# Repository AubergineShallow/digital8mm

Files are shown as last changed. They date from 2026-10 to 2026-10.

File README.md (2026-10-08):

# digital8mm: GS8 D2

GS8 D2 is a pistol-grip digital "Super 8" cine camera in the spirit of the Nizo:
- a Raspberry Pi 5 with the Raspberry Pi Global Shutter camera (IMX296, C/CS mount);
- an integrated micro-OLED electronic viewfinder;
- a 3D-printed ASA body;
- a physical 18/24 fps switch, an exposure dial and a record button;
- recording RAW to a removable USB stick.

This repository holds **only the D2 fork** of the wider GS8 project, plus the few shared files its build needs.

**Status:** a computed CAD release candidate (r6, 2026-10-08), **not a qualified design**.
- Every result here is a computed check on built solids and purchased-part proxies, desk research, or a document.
- Nothing has been printed, sliced, bought, measured, assembled or powered.
- 53 physical bench gates are open.
- **Print order (r6).** It is settled and enforced: [`PRINT-GUIDE.md`](cad/gs8-d2-v1/PRINT-GUIDE.md) section 7 says
  which measurements each part waits for. Start with the calibration coupons and the bench measurements (camera and
  lens first).
- **Print orientation (r6).** It is settled and checked layer by layer (`print_overhang`).
- **Open design defect.** The lens collar's clamp has no spring (audit 2026-10-06 M1); fix it before the collar is
  printed.

## Start here

1. [`cad/gs8-d2-v1/HANDOFF.md`](cad/gs8-d2-v1/HANDOFF.md): current state, latest build receipt, open items.
2. [`CLOUD-START-HERE.md`](CLOUD-START-HERE.md): how to reproduce the CAD and run the software on a host.
3. Design and build documents:
   - [`SPEC.md`](cad/gs8-d2-v1/SPEC.md): the contract;
   - [`DESIGN.md`](cad/gs8-d2-v1/DESIGN.md);
   - [`ASSEMBLY.md`](cad/gs8-d2-v1/ASSEMBLY.md);
   - [`PRINT-GUIDE.md`](cad/gs8-d2-v1/PRINT-GUIDE.md);
   - [`FASTENER-POLICY.md`](cad/gs8-d2-v1/FASTENER-POLICY.md);
   - [`MEASURED-PARTS.md`](cad/gs8-d2-v1/MEASURED-PARTS.md): the bench gates.
4. Electronics: [`electronics/gs8-d2-v1/WIRING.md`](electronics/gs8-d2-v1/WIRING.md) and
   [`BOM.md`](electronics/gs8-d2-v1/BOM.md).

## Layout

| Path | Contents |
|---|---|
| `cad/gs8-d2-v1/` | CadQuery sources (`layout.py` is the single geometry source), checks, tests, docs, research notes |
| `cad/gs8-d2-v1/out/` | Current release outputs: production STLs, modifier and coupon meshes, the collar centring gauge (`stl/tools/`), STEP, manifests, `checks.json`, `build-receipt.json`; Fujinon variant in `out/_fujinon-cloud-polish-20261007/` |
| `electronics/gs8-d2-v1/` | Wiring, BOM generator and BOM, power and fuse research, second-hand sourcing notes |
| `software/gs8-camera-evf/` | Camera software package, including the D2 integration (`d2_*.py`, `D2-INTEGRATION.md`) |
| `audit/d2-readiness-*` | Independent readiness audits of D2 and their responses |
| `visual-review/`, `validation/` | Rendered review views and computed verification records |

**Shared files carried over from the parent project** because the D2 build reads them:
- `electronics/gs8-evf-v1/EVF-SELECTION.md`: an EVF gate document;
- `cad/gs8-pxl-v3/cad-requirements-lock.txt`: the pinned CAD environment;
- `tools/bootstrap_cad.py`: creates that environment;
- `outputs/bom-release-2026-09-25/prices.json`: BOM prices.

**Kept out of git** (see `.gitignore`):
- manufacturer drawings and datasheet images used in research;
- airflow-simulation checkpoints;
- historical build folders;
- baseline zip snapshots.

## Reproduce

Use the pinned environment (Python 3.12.14 plus 43 locked packages), then run from the repository root. On Windows
use `.venv-cad/Scripts/python.exe` as the interpreter:

```text
python tools/bootstrap_cad.py
python cad/gs8-d2-v1/run_locked.py -- cad/gs8-d2-v1/test_r3_regressions.py
python cad/gs8-d2-v1/run_locked.py -- cad/gs8-d2-v1/build_d2.py --skip-renders --sweep-step 1.0
```

The full release sequence (coupons, Fujinon variant, tables, BOM, audit) is in `CLOUD-START-HERE.md`. Heavy CAD
commands always go through `run_locked.py`.

## Licences

- `software/gs8-camera-evf/` and `tools/` carry their own licence files.
- The DejaVu font has its licence in `cad/gs8-d2-v1/fonts/`.
- No licence has been chosen yet for the rest of this repository.

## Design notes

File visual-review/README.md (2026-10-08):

# D2 cloud polish visual supplement

Six views of the final Kowa cloud-polish CAD candidate. They preserve the approved D2 architecture and show the intended paint-filled markings. The camera has not been physically built or tested.

## Gallery

- `renders/hero.png` - overall form and intended finish
- `renders/controls.png` - corrected selector shaft state and pinned-font labels
- `renders/controls-raw.png` - the same control geometry with unfilled engraving
- `renders/collar_pinch.png` - collar, washer seating and top-down pinch access
- `renders/rear.png` - viewfinder, storage access, grip and strap-side view
- `renders/service.png` - illustrative part separation; harnesses omitted

The exploded view is not an assembly sequence. Follow the main ASSEMBLY.md, including shutdown and physical battery isolation before internal service. Assembly STEP depicts cleared, post-processed holes; sacrificial printing membranes belong to the production STL/print guide.

The visible materials are illustrative. Black fill on the silver panel and white fill on the selector index/power symbol follow the existing finish intent. The exposed encoder shaft is a neutral hardware proxy, not a blue PCB surface. No decorative part was added, and no bore, fastener, or access opening is hidden.

## Findings and evidence

`REVIEW.md` explains the visual/ergonomic review and the changes it informed. `ENCODER-PUSH-REQUIREMENT.md` defines the measurement and acceptance procedure for the uncommissioned encoder push. `control_geometry_probe.json` preserves the baseline geometric measurements behind that finding and the repaired selector mismatch.

All 53 physical gates remain open. The render is not evidence of lens-band fit, optical focus, print quality, switch travel, comfort, cable routing, thermal performance or assembled stability. Kowa is the default modeled lens; the alternative Fujinon has its separate validated computational build in the main package.

`RENDER-PROVENANCE.json` binds the final images/scripts to the Kowa build receipt and source/STEP checks. It also records the independently passing Fujinon receipt. Baseline and intermediate candidate renderings are excluded.

## Reproduce the views

Prerequisites: the main project beside this folder; its pinned CadQuery 2.6.1 environment and exported final STEP files; Blender 4.3.2. From `project/visual-review`, use the pinned Python interpreter for this serialized mesh-export step:

    python ../cad/gs8-d2-v1/run_locked.py -- scripts/export_review_meshes.py --cad-root ../cad/gs8-d2-v1 --build-out ../cad/gs8-d2-v1/out --out meshes

The exporter refuses mismatched recorded Python/font sources or part STEP hashes. Do not run a second CAD command concurrently or remove its lock.

Render one view:

    blender -b -t 6 --python scripts/render_review.py -- --assets meshes --out renders --view hero --samples 128 --revision r5-cloud-polish-20261007

Repeat with `controls`, `collar_pinch`, `rear` and `service`. Add `--raw` to `controls` for the unfilled comparison. Optional exploration views are `collar` and `grip`.

The renderer uses Cycles CPU with denoising disabled and no external scene assets. It changes only lighting, display materials and explanatory exploded positions. The scripts do not rebuild a production release or close any hardware gate.

The separately delivered six-page PDF contains these same six views. `scripts/build_visual_gallery.py` reproduces it from `renders` using Pillow and ReportLab; its hash is recorded in RENDER-PROVENANCE.json.

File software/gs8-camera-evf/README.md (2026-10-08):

# GS8 EVF software fork

## D2 cloud-copy integration (2026-10-06)

For D2's physical 18/24 switch, toggle-run input and **1S X1203** power policy,
start with [D2-INTEGRATION.md](D2-INTEGRATION.md). The new `d2-demo` command runs
labelled synthetic controls/descriptor takes on a host; `d2-run` is an explicit
integrator adapter/config entrypoint with no default live deployment. D2 host
logic is tested; physical GPIO, display retention, media handling and power/heat
qualification remain open. The historical `run` path and **3S** battery text
below are preserved and must not be used as D2 wiring/configuration.

[D2-PRESENTATION.md](D2-PRESENTATION.md) adds pure host-rendered EVF status pixels
and a labelled preview gallery. Its full-sensor viewport requires a future
compositor adapter; it is not a drop-in overlay or verified shutdown display.

## Historical release-v1 / GNB 3S commissioning path

The remaining commands and battery configuration describe the preserved
**3S / hold-trigger** path, not D2's **1S / toggle-run** path. For the D2 cloud
copy, use [D2-INTEGRATION](D2-INTEGRATION.md) and the project-level
[CLOUD-START-HERE](../../CLOUD-START-HERE.md).

Historical branch battery: **GNB11003S60AHV 3S LiHV**, charged outside the camera.
`power.py` supplies the common pack-voltage stop policy and
`step_with_battery` recorder adapter. It inhibits new takes before voltage
qualification and uses the existing durable-drain contract before OS poweroff.
It does not replace independent per-cell protection or a kernel halt interface.
See [power design](../../electronics/gs8-gnb3s-v1/README.md).

This independent package preserves `software/gs8-camera` and adds a real,
lazy-loaded Picamera2 adapter for the colour IMX296 and an HDMI colour EVF.
Host tests pass; no Pi, sensor, DNG output, display, or optical latency has been
tested on physical hardware here. Treat this as a commissioning build.

The ISP feeds a 728 × 544 XRGB8888 preview directly to DRM/KMS. That is exactly
half the 1456 × 1088 sensor in each dimension. DRM preserves the whole sensor
aspect ratio within the HDMI canvas; no electronic finder parallax is added.
The default HDMI canvas is 1024 × 768, the native input of the selected EVF-A (and of
EVF-A2 and EVF-B; see [EVF-SELECTION.md](../../electronics/gs8-evf-v1/EVF-SELECTION.md)).
`--display-size 1920 1080` applies only to the external Kinefinity EAGLE fallback. The active CRTC must match the
requested dimensions at progressive 59–61 Hz, or startup fails. The display
controller can still scale/crop internally: verify a grid and colour bars in
the actual eyepiece, using its native input resolution wherever supported.

## Capture and exposure policy

| Recording | Default sensor/ISP rate | Recorded source frames | 90° exposure |
|---|---:|---|---:|
| 24 FPS | 48 FPS requested | every second frame | 10,417 µs |
| 18 FPS | 54 FPS requested | every third frame | 13,889 µs |

These are new sensor exposures, not repeated recording frames. A 60 Hz display
repeats some of the 48/54 source images. The integer ratios preserve uniform
recorded sampling; the sensor clock and microsecond frame-duration quantisation
still cause small rate error, so actual timestamps and measured rate are saved.

`--source-fps 60` lowers the source period for either recording rate, but 24 FPS
then alternates 2/3 sensor periods (33.3/50 ms), and 18 FPS uses 3/4 periods
(50/66.7 ms). This uneven capture cadence is explicit in the manifest. No
interpolation, duplicates or fabricated sensor timestamps hide the difference.

High source FPS cannot coexist with long per-frame cinema exposures on this
single sensor: 180° at 18 FPS is 27,778 µs, and at 24 FPS it is 20,833 µs.
Both are rejected by the default high-rate modes with a provisional 200 µs
sensor timing margin. **The hardware CLI explicitly defaults to 90°.** It
never silently shortens a selected shutter angle. Actual exposure, gain, WB,
frame duration, and source timestamp are checked and recorded for each take.

## Latency and storage ownership

Preview uses upstream Picamera2's newest completed request, DMA buffer scanout,
`queue=False`, four camera buffers, and noise reduction off. There is no video
encoder, network transport, compositor, or Python preview pixel copy.
`queue=False` disables cached still capture; upstream newest-request rendering
is what prevents a FIFO of old preview frames.

The callback only checks metadata and hands off a reference. A worker retains
**at most one** camera request, copies selected RAW pixels, and releases that
request before a separate worker creates an uncompressed DNG. Copied RAW is
bounded to two queued frames, DNG output to four, and the CLI disk writer to
four. Disk or conversion overload explicitly fails the take rather than
retaining the entire sensor pool. Accepted data drains before durable close;
the inherited journal, hashes, commit receipt and storage reservation remain.

Recording sample indices and original sensor frame sequences are separate.
Intentionally unrecorded preview exposures are counted separately from losses.
Any sensor sequence gap or failure to sustain the requested cadence fails the
take. `record_pts_ns` is an explicitly nominal postproduction timeline;
`sensor_timestamp_ns` remains libcamera's measured CLOCK_BOOTTIME timestamp.

Continuous preview survives normal take completion through `release_take()`.
Subsequent takes use the same sensor controls; changing controls requires a new
backend session. Idle preview errors inhibit recording. Shutdown and faults
fully close the preview/camera; no software code asserts the OS_HALTED line.

## Run on a Raspberry Pi 5

Use Raspberry Pi OS with its matched apt versions of `python3-picamera2`,
libcamera, KMS bindings and NumPy. Run on the local text console with KMS access,
the EVF as the only connected display, and no desktop display server owning DRM.
`kmsprint` reports the active HDMI timing. Before starting, apply the EVF-A HDMI
settings in [EVF-SELECTION.md](../../electronics/gs8-evf-v1/EVF-SELECTION.md) section 4
(also [release WIRING.md](../../electronics/gs8-release-v1/WIRING.md) section 8):
`max_framebuffers=2` and `disable_fw_kms_setup=1` in `config.txt`, and
`video=HDMI-A-1:1024x768@60D vc4.force_hotplug=1` in `cmdline.txt`. Section 4 also
gives the custom-EDID fallback, and receipt gate G2 accepts the mode. The software never
sets an HDMI timing. It refuses to start unless the active mode matches
`--display-size` at progressive 59–61 Hz. Pin and record the installed package
versions after commissioning; upstream API inspection alone is not a version
qualification.

From this package directory:

```sh
python3 -m venv --system-site-packages .venv
. .venv/bin/activate
python -m pip install -e .
kmsprint
# Set these to measured white-balance calibration values for the scene:
export GS8_WB_RED=1.5 GS8_WB_BLUE=1.25  # examples only; replace before commissioning
gs8-camera-evf run --output /media/gs8/takes --fps 24 --shutter-angle 90 \
  --wb-gains "$GS8_WB_RED" "$GS8_WB_BLUE" --seconds 10 --takes 3 --pause-seconds 2 \
  --display-size 1024 768
# External Kinefinity EAGLE fallback only (1920x1080); EVF-A uses --display-size 1024 768:
gs8-camera-evf run --output /media/gs8/takes --fps 18 --shutter-angle 90 \
  --wb-gains "$GS8_WB_RED" "$GS8_WB_BLUE" --preview-only --seconds 60 \
  --display-size 1920 1080
gs8-camera-evf inspect --output /media/gs8/takes
```

SIGINT/SIGTERM request a drained stop. A take may remain failed/incomplete if
hardware or storage refuses to drain. The CLI creates scheduled bench takes;
physical selector/trigger GPIO, audio/I2S, film/pixel looks, automatic service
startup and shutdown wiring still require integration/commissioning. Hardware
capture rejects audio, encoded recording and unimplemented looks. The separate
`simulate` command produces labelled descriptors, never camera footage.

The optional `--battery-hwmon PATH` enables an INA260 low-battery drained stop
through the Linux hwmon driver. It needs a kernel `ina2xx` hwmon device named `ina260`,
which the release `config.txt` does not create yet (open item in
[release WIRING.md](../../electronics/gs8-release-v1/WIRING.md) section 10).
Add `--battery-poweroff` to request OS poweroff
after a battery-triggered stop only when recorder/preview/store cleanup succeeds.
Startup requires one second of valid readings at ≥11.1 V; ≤10.5 V for one second,
≤10.2 V immediately, or faulty/stale telemetry latches stop. Thresholds remain
provisional. Normal command completion ends monitoring without halting the Pi.
This is commissioning software, not an independent battery protector or a
completed physical cutoff. See the [GNB 3S power design](../../electronics/gs8-gnb3s-v1/README.md)
for setup boundaries, warnings, waveform qualification and remaining gates.

Uncompressed 16-bit containers for RAW10 are about 3.17 MB/frame before DNG
overhead: about 76 MB/s at 24 FPS or 57 MB/s at 18 FPS. Use storage with measured
sustained write/fsync margin. DNG conversion and Linux scheduling can compete
with preview despite bounded ownership: benchmark on the actual Pi under heat,
power and disk stress. Optical source-to-eyepiece measurements, not callback
timing, must establish a latency claim. See the fork's root EVF design and
latency acceptance procedure.

## Host verification

```sh
python -m unittest discover -s tests -v
python -m gs8_camera_evf simulate --output /tmp/gs8-evf-smoke --fps 24 --frames 48
```

Tests include source cadence, colour-mode validation, exposure conflicts,
HDMI geometry, retained-buffer limits, blocked conversion, queue saturation,
source loss, applied metadata, close retry, idle fault handling, two complete
takes with continuous preview, and final shutdown. Fake DNG bytes are labelled
test data; these tests do not validate a real DNG decoder or display latency.

## Primary sources inspected 2026-09-20

- [Raspberry Pi Global Shutter Camera specifications](https://www.raspberrypi.com/products/raspberry-pi-global-shutter-camera/): colour IMX296, RAW10, up to 1456 × 1088 at60 Hz.
- [Picamera2 camera configuration and event loop source](https://github.com/raspberrypi/picamera2/blob/main/picamera2/picamera2.py): stream controls, queue semantics and newest-request preview selection.
- [Picamera2 request and DNG helper source](https://github.com/raspberrypi/picamera2/blob/main/picamera2/request.py): reference ownership, owning RAW copies, `Helpers.save_dng()`.
- [Picamera2 DRM preview source](https://github.com/raspberrypi/picamera2/blob/main/picamera2/previews/drm_preview.py): DMA scanout, aspect fit, retained display request and atomic commit.
- [libcamera control definitions](https://docs.libcamera.org/master/internal-api/namespacelibcamera_1_1controls.html): applied sensor controls and timestamp clock.
- [KMS Python bindings](https://github.com/tomba/kmsxx/blob/master/py/pykms/pykmsbase.cpp): CRTC active mode and video timing readback.

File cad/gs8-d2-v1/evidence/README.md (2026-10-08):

# GS8 D2 evidence records (r3)

Nothing in this folder exists until someone slices, prints, measures or assembles real hardware. The build machine
has no slicer, printer or parts: `build_d2.py` only reads the records here and reports them; it never judges them and
never closes a hardware gate.

## One record per tested item

A record is a JSON object (a file may hold one object, a list, or `{"records": [...]}`) in any `*.json` file under
`evidence/` (by convention `slicer/`, `coupons/`, `measured/`, `assembly/`). Copy `_record-template.json`. Files whose
name starts with `_` or contains `template`, and this README, are skipped. Any other non-JSON file (a photo, a `.md`
report) is listed as `ignored_files` in the receipt: keep it as an attachment and name it in `notes`, but it is not
evidence by itself. **File names are never matched**: `panel.md`, `base_edge_panel.json` or `old-panel-r1.md` say
nothing to the build.

| Field | Content |
|---|---|
| `item` | the exact item id: a printed part id for `slicer_review` (`panel`, `tub`, ...), a gate id otherwise (`G-CAP-1`, `G-KNOB-1`, `G-W6`, `EVF-G2`, ...) |
| `state` | `slicer_review`, `coupon_validation`, `measured_fit` or `assembly_operation` |
| `artifacts` | `{path: sha256}` of every artifact actually tested: `stl/<part>.stl` (production STL), `stl/coupons/<coupon>.stl`, or a source/doc path relative to `cad/gs8-d2-v1/` or the repo root |
| `profile` | printer, nozzle, material, slicer + version + profile (or the measuring tool / variant) |
| `verdict` | `pass` or `fail` (nothing else) |
| `date`, `by` | when and who. r6 (audit 2026-10-06 L12b): `date` is ISO 8601, `YYYY-MM-DD`, optionally with a time (`2026-10-20 14:30`); anything else is rejected, because the print order compares dates |
| `notes` | optional: settings, values, observations, attachment names |

sha256 of a file: `python -c "import hashlib,sys;print(hashlib.sha256(open(sys.argv[1],'rb').read()).hexdigest())" out/stl/panel.stl`
(the receipt `out/build-receipt.json` `files` lists the current hashes).

## What the build reports (receipt `status_states`, `open_evidence`, `hardware_gates`)

- **Completeness** per item: a current, valid record exists (`evidence_complete`).
- **Outcome** per item: `pass`; `fail`; `conflict` (current records disagree); `stale` (every record names an artifact
  whose sha256 differs from the CURRENT production STL, coupon STL or source, or that no longer exists: r1 and older
  records are stale); `rejected` (the item has a rejected record: it stays open until that record is corrected or
  removed, whatever the other records say); `not run`.
- Rejected records (listed with the reason, never counted as a pass): missing field, bad hash, verdict other than
  pass/fail, unknown state, a coupon artifact on a production-part item, a record that does not name the required
  artifacts. A record of a valid state whose `item` is not a required id (e.g. `Panel` for `panel`) is listed in that
  state's `unmatched_records` and keeps the state open. A file that is not readable JSON, or a record with an unknown
  state AND an unknown item, is listed in `evidence.unassigned_records` (and `rejected_records`) and named in
  `open_evidence`.
- Required artifacts (artifact keys: production / coupon STLs as `stl/...`; docs and sources as repo-root paths, e.g.
  `cad/gs8-d2-v1/MEASURED-PARTS.md`; a path relative to `cad/gs8-d2-v1/` is accepted and converted):
  - `slicer_review`: `stl/<item>.stl` and (r4) every modifier mesh of that part,
    `stl/modifiers/<item>__mod_<id>.stl` (r5: tub 10, panel 4, base_grip 4; the slice must load them);
  - `coupon_validation`: every coupon STL of its gate (from `out/coupons-manifest.json`, `coupons-r1-manifest.json`)
    or calibration;
  - `measured_fit`: the gate's acceptance doc (`electronics/gs8-evf-v1/EVF-SELECTION.md` for EVF-G*,
    `electronics/gs8-d2-v1/WIRING.md` for G-W*, else `cad/gs8-d2-v1/MEASURED-PARTS.md` if it names the gate, else
    `cad/gs8-d2-v1/SPEC.md`); also name any printed STL the part was fitted to (it is hash-checked too);
  - `assembly_operation`: that doc AND every production STL `stl/<part>.stl` (the assembly, service or bench test
    belongs to that release geometry; a geometry change makes the record stale).
- A state stays in `open_evidence` until EVERY required item has a current pass; failed, conflicting and stale item ids
  are named there. A rebuild that changes an STL or source makes the records for it stale: re-test and add a new
  record (keep the old one; it stays as history).

## Required items

- `slicer_review`: the 12 printed parts (`base_grip`, `cap`, `eyecup`, `hood`, `knob_exp`, `knob_fps`, `lens_collar`,
  `panel`, `pi_keeper`, `plunger`, `stick_sleeve`, `tub`; r5 added the lens collar, audit 2026-10-06 B-9).
- `coupon_validation`: G-PT-1, G-KEEP-1, G-PANEL-1, G-CAP-1, G-EVF-2, G-SNAP-2, (r5) **G-COL-1** (`collar_tub_front`
  + `collar_hood_plate` + `collar_part`, and since r6 the centring gauge `stl/tools/collar_gauge.stl`) and the
  PRINT-GUIDE s6 calibrations **G-KNOB-1** (`knob_bore_ladder_enc` +
  `knob_bore_ladder_sw`), **G-COMB-1** (`clearance_comb`), **G-J4-1** (`tongue` + `keyhole_slot`).
- **Names (audit L12c):** MEASURED-PARTS record ids (`MP-CAM`, `MP-PACK`, ...) are not items. File the record under
  its gate id: MP-CAM is `G-CAM-1` (the camera stack) and `G-LENS` (its lens line). A record filed as `MP-CAM` is
  unmatched and keeps `measured_fit` open.
- **Print order (r6, audit 2026-10-06 M2):** a `slicer_review` record for a part counts only after every gate of
  `layout.PRINT_PREREQS[part]` (PRINT-GUIDE s7) has a current recorded pass dated on or before it. The same holds for
  a G-COL-1 coupon record and `COUPON_PREREQS`. Otherwise the record is **rejected** with the missing gate named, and
  the part stays open. File the measured and calibration records first, then slice. The receipt's `print_release`
  says which parts that releases.
- `measured_fit`, `assembly_operation`: every other gate id named in MEASURED-PARTS.md, SPEC.md, WIRING.md and the
  EVF-SELECTION gate table (the receipt lists them in `hardware_gates`).
- **r4 split items** (`assembly_operation`): `G-SNAP-2/whole` (5 remove/refit cycles of the whole hood on the tub),
  `G-KEEP-1/whole` (5 keeper cycles on the real stack in the printed tub + the far-corner tilt test) and
  `G-PANEL-1/whole` (5 panel cycles on the body, strap fitted). Name the gate's doc (SPEC.md) and every production
  STL. The gate itself reads `recorded pass` only when its coupon item AND its `/whole` item have a current pass.
- **Field types (r4):** `item`, `state`, `verdict`, `profile`, `date`, `by` must be JSON strings and `artifacts` an
  object; a record with another type is rejected and listed (it never stops the build).

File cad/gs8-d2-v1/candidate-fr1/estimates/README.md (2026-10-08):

# Panel stiffness estimates (ESTIMATE only, not FEA-validated, nothing measured)

Copied 2026-10-05 15:16 by fix-candidate (finding VC-M3) from the fr-panel-2 session scratchpad `fp2/` so that
JOINT-panel.md s. 11.2 and CANDIDATE.md s. 2/6 can be reproduced from the fork. Files are byte copies of the scratchpad
originals (10:33-11:23).

- `grill.py`: grillage (Hambly) model of the 2.8 ASA panel (method in JOINT-panel.md s. 11.1).
- `opts.py`, `opts2.py`: option table (opts2 = unilateral wall-bearing contact, the model the table uses).
  Option '1e 1c+front rib' is **A2** (the chosen FR panel geometry).
- `opts2-output.txt`: output of `opts2.py` re-run here 15:17 (pure numpy, no CAD); it reproduces every number of the
  JOINT-panel.md s. 11.2 table and the bottom-edge profiles.
- `sens.py`: sensitivity runs; `depth.py` + `depth.pkl` + `ribchk.py` + `show.py`: the inner-face free-depth map used to
  place the frame ribs (depth.py reads the r2 STEP parts from `cad/gs8-d2-v1/out/step/parts/`, run from the repo root).

Run: `cd cad/gs8-d2-v1/candidate-fr1/estimates && ../../../../.venv-cad/Scripts/python.exe opts2.py`

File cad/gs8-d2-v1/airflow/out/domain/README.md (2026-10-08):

# D2 air domain (af-domain), baseline r2 arrangement

Made 2026-10-05 by `airflow/export_meshes.py` (run once under the CAD lock, 129 s) and `airflow/voxelize.py`
(run outside the lock, about 30 s for both grids). Geometry: the baseline release pipeline (`build_d2.build_printed` +
`build_cots`, default lens kowa_lm6hc, no FR1 changes). There were no stubs, and all 38 meshes are watertight
2-manifolds (`out/meshes/index.json` has the bounds, triangle counts and source hashes). Purchased parts are proxies.
Nothing here is a measurement.

## Files

- `../domain-2.0.npz`, `../domain-1.5.npz`: the shared interface from `airflow/NOTES.md`. Keys: `dx`, `origin`
  (centre of cell (0,0,0), assembly mm), `solid`, every `mask__*`, and `meta_json`. Two extra keys: `label` (int8,
  legend in meta) and `part` (int16 index into `part_legend`, -1 = none).
- `summary-<dx>.json`: the same meta as readable JSON (vents, fan, heat, pockets, plugs, connectivity, counts).
- `slice-<dx>-<axis><value>.png`: label slices through the cooler (z 27), the blower top / out_corner (z 33), the
  X1203 sandwich (z 13), the exhaust plenum (x -7), the EVF board (x -140), the roof inlet over the blower (x -58),
  roof inlet - blower - fins - front (y -10), and the right wall (y -33.6). Dark red dots mark air cells that
  receive heat.
- `voxelize.log`: per-part occupancy, timings and results.

## How the domain is built

- **Grid.** Cell faces lie on multiples of dx, so x = 0 (the front face) and z = 0 (the body bottom) are cell faces.
  dx 2.0 gives 86 x 45 x 60 cells; dx 1.5 gives 112 x 57 x 77.
- **Occupancy.** Each part is sliced (manifold3d) at 3 levels per cell and scan-converted with the even-odd rule at
  3 x 3 points per cell, giving 27 sub-samples. The shells (tub, hood, panel, base_grip) are solid where ANY
  sub-sample is inside, which keeps walls of dx/3 or more closed. All other parts are solid where 14 or more of the
  27 sub-samples are inside.
- **Body interior.** First the vent zones and the plugs are closed and the outside is flood-filled from the grid
  boundary. Nothing leaks: the interior never meets the outside except through a vent. The main interior is the
  connected air that holds the fan intake. The outside is inactive (solid) except in the vent buffers.
- **Closed holes (label 10, `mask__leak__*`).** The grip/battery bay is excluded. The floor lead holes
  (`floor_pigtail`, `floor_run_lead`) are treated as closed by the leads and a grommet. The microSD tweezer slot
  through both front walls (`ko_sd`, about 12 x 2.3 mm less the card) is treated as closed with the card in place.
  It is a real leak path. Opening it as a sensitivity also needs an outside buffer there, which is not built.
- **Vents (`mask__vent__<id>`, label 5).** A vent zone is the set of cells that overlap the wall along the normal and
  whose centre lies inside the vent's lateral box. The front vents are the tub window and the hood plate in series
  (x -5.2..0). The slots are not resolved; the porous zone carries the loss. The meta gives each vent's normal,
  thickness in cells, face cells, discrete/box area ratio (1.00 to 1.29), slot_w/pitch and its shortest air path
  from the fan intake and from the fin exit.
- **Outside buffer.** Beyond each vent face there are 5 buffer cells (label 3), grown 2 cells laterally, plus an
  ambient layer (label 4, `mask__ambient`) on the far face and the lateral rim.
- **Fan.** The proxy blower box (x -72.8..-42.8, y -24..4, z 23.4..36.3) is turned into housing walls one cell thick
  (-X, +-Y, top; the floor is the cooler plate) and an interior actuator (`mask__fan_actuator`, force unit +X). The
  top wall has an intake disc of r 9.0 at the proxy hub circle (`mask__fan_intake`). That radius is an ESTIMATE: no
  published intake size was used. The +X housing face is open only over the fin height (z 23.4..30.5) and is wall
  above it.
- **Fins.** `mask__fin_block` covers x -42.8..-9.5, y -25.55..16.95, z 23.4..30.5. The plates are normal to Y and
  open on top in the proxy, which models no shroud. So the block should be porous with low resistance along X (and
  along Z between the plates) and high resistance along Y. `mask__fan_outlet` is the first cell layer past the fins
  (x about -9). The SoC heat goes into the fin block (`mask__heat__soc`).
- **Heat masks.** Each mask is the interior air within 1 cell (26-neighbour) of its proxy:
  - X1203: the charger/boost field box.
  - EVF board.
  - Camera: gs_camera.
  - USB stick.
  - Pi board remainder: the PCB slab plus the underside parts (z 16..21.4); the jack blocks get no heat.
- **Probes.** Each probe is a set of air cells to average over:
  - `fan_intake_air`: the 2 layers above the intake.
  - The 5 component probes. Each one is the same set of cells as that component's heat mask.
  - `exhaust_plenum`: the ko_exhaust box.
  - `fin_exit`.
  - `roof_inlet_inner`: the layer under the roof zone.
  - `outside_<vent>`: the first buffer layer beyond each vent.

## Checks

| | dx 2.0 | dx 1.5 |
|---|---|---|
| interior air | 656 cm3 (82 051 cells) | 678 cm3 (200 983 cells) |
| fluid components | 1 | 1 |
| every vent reaches the fan intake and the fin exit through air | yes | yes |
| dropped pockets (no path to the fan or a vent) | 19, 9.6 cm3 | 11, 5.4 cm3 |
| fin block cells / actuator cells / intake cells | 1008 / 816 / 62 | 2576 / 2210 / 113 |
| fin section discrete / proxy | 252 / 302 mm2 | 252 / 302 mm2 |
| blower outlet open discrete / proxy | 144 / 199 mm2 | 153 / 199 mm2 |

**Dropped pockets.** The pockets are sealed air with no forced flow, so they are solid in the model.
- The largest (5-9 cm3) is the hood lens-collar cavity in front of the front wall, around the camera ring and C-CS
  adapter.
- Next come the small EVF optics cavities behind the board (hmx039 / eyepiece / foam).
- The rest are single cells: around the stack standoffs and screw bosses, plus a 40 mm3 corner by the X1203 at
  dx 2.0.

## Findings for the solver and the report (geometry, not flow results)

- **x1203 slots.** The proxy pogo-pin field (x -64..-13, y -31.8..-27.3, z 7.6..16) sits directly behind the x1203
  slots (x -65..-49, z 9.5..17.5). The slots only reach the sandwich through a band about one cell high above the
  pins (z 16..17.5) and around the ends. Their path from the fan intake (49 / 61 cells) is the longest of the vents.
  The pogo box is an estimate, so this needs checking on the real board.
- **out_wall slots.** The Pi 5 GPIO header and the board edge (0.2 mm off the right wall) sit behind the lower part
  of the slots, and the QT lead keep-out sits behind the upper part. At dx 1.5, 20 zone cells are pi5 solid.
- **Shortest paths.** The fin exit is 2 cells from out_band, 4 from out_corner and 7 from out_wall. The roof inlet is
  31 / 41 cells from the fan intake through the tall open chamber over the blower. There is NO wall between the fin
  exit / plenum and the space above the fins (the deleted baffle), so recirculation of exhaust to the intake is
  geometrically open.
- **Not modelled.** Cables and keep-out volumes (ribbon S-fold, HDMI coil, leads) are not modelled as solids, so
  they add blockage the model does not include. Fin height is 3 cells at dx 2.0 and 4 cells at dx 1.5 (6.0 mm
  against 7.1 mm), and the solver should scale the porous loss by the section ratio above.

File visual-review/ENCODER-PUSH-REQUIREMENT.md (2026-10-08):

# D2 exposure encoder push acceptance

Acceptance guidance integrated into the cloud-polish MP-ENC/G-MP-ENC and G-W9 work. The original geometry measurements are from the immutable r5 source. Required switch travel remains unknown, and no physical control test is claimed.

## Finding

The exposure encoder is push-capable, and WIRING section 8 makes a reset function available. The current fit gate verifies only shaft fit and the knob rest gap. It does not verify axial push travel. A knob can rotate normally yet stop against the panel or bushing before the switch closes.

Source evidence:
- `layout.py`: panel outer plane `YL = 35.0`; `KNOBS["knob_exp"]["y"] = (35.2, 44.2)`.
- `layout.py`: fixed bushing tip `ENCODER["bushing"]["a"][1] = 37.2`.
- `printed_small.py::build_knob`: recess roof is bushing tip + `FDM["SLIDE"] = 37.45`.
- Therefore unloaded panel clearance is 0.20 mm and unloaded bushing-roof clearance is 0.25 mm. The first-contact limit is at most 0.20 mm, before print/finish error or a positive running-clearance allowance. These are assembly-coordinate distances, not a measured switch travel.
- `MEASURED-PARTS.md`, MP-ENC: no push travel or full-stroke clearance record exists.

## Datum definitions

Use the fitted production panel, encoder and knob. The encoder must be fully latched in its actual cradle and the knob fitted to the depth intended for normal operation.

1. Panel datum P: the local outer panel plane, nominal Y = 35.0 mm. Positive Y points out of the control face; a press moves the knob and shaft in negative Y.
2. Fixed bushing datum B: the outer end of the stationary threaded bushing. Do not confuse this with the moving shaft shoulder or tip.
3. Rest datum K0: the nearest rigid knob underside face over the panel, with no finger load and the switch released.
4. Recess datum KR: the inside roof of the knob recess directly above the stationary bushing.
5. Travel s: the negative-Y displacement of the moving shaft/knob from the released position. Measure it at the shaft or knob using a dial indicator/caliper with the panel fixed, not by hand-force displacement of the whole panel.

Record gP = K0 - P and gB = KR - B after painting/finishing. Record the encoder part/variant, actuation stroke, release stroke, rated/full permitted stroke where available, and any drawing tolerances. Record whether the knob slides on the shaft or the cradle visibly deflects during the operation; neither is acceptable as a substitute for real switch travel.

## Acceptance procedure for MP-ENC and G-W9

- Measure the actual part before freezing knob height and recess depth. Record reliable contact closure and release over at least ten normal presses; use the manufacturer's allowed travel and force limits when available. If the switch travel specification is unavailable, leave it unconfirmed until the installed test is recorded.
- Choose the required operating stroke from the actual part data and repeated test, including its stated tolerance/overtravel. Do not populate the CAD parameter with a generic encoder value.
- Parameterize `required_push_travel_mm` as unknown until that record exists. Derive both rest gaps from the model, and report the available first-contact travel as `min(gP, gB)`.
- At the required operating stroke, the knob must clear both the panel and the fixed bushing by the declared axial running allowance. Use the project's existing slide allowance (0.25 mm) unless a validated fit record explicitly establishes another allowance; never infer allowance from successful rotation alone.
- Keep sufficient measured D-flat engagement and no axial shaft preload at rest. The knob must remain removable by the documented method. Do not hide the through bore with a separate cosmetic cap.
- Turn throughout the useful range, then press and release with the production panel closed. There must be no panel rubbing, bushing stop, binding, switch held closed at rest, accidental reset while rotating, or knob migration. Verify the reset behavior on the EVF under G-W9; software-only tests do not close this hardware gate.
- If it fails, raise the knob mounting/underside clearance and deepen its bushing recess as required by the measurement, then recheck shaft engagement, envelope/hand clearance, printability and the CAD operation sweep. Reprint only the affected part if the revised design permits.

## Example check (symbolic, not an assumed hardware dimension)

`panel_remaining = gP - required_push_travel_mm`

`bushing_remaining = gB - required_push_travel_mm`

`pass = measured_travel_is_current and min(panel_remaining, bushing_remaining) >= axial_running_allowance_mm`

For the existing r5 gaps this reduces to `min(0.20 - s, 0.25 - s)`. No positive stroke can satisfy a 0.25 mm residual allowance. The current CAD does not establish push readiness; this should be an explicit uncommissioned control operation, not a fabricated pass or a reason to invent a switch dimension.

The encoder remains the exposure control and the physical 18/24 selector remains unchanged. No new menu, indicator, printed part, or external control is proposed.

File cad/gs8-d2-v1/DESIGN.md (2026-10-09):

> Cloud-polish copy (`r5-cloud-polish-20261007`): see `CLOUD-POLISH-NOTES.md` before the historical record below.
> The generated blocks reflect the current copied build; hand-written r1-r5 results remain labelled history.
> This fork does not supersede later desktop work. All physical gates remain unvalidated.

# GS8 D2 release v1: design record (`cad/gs8-d2-v1`)

Integrator record, 2026-10-04 (machine time 12:43-14:15; skeleton by the docs owner); fixer pass 13:16-14:10 (section 6b); **r2 rectification 2026-10-05 00:00-01:30 (section 6c, `RECTIFICATION.md`)**; **r2 fixer pass 02:00-03:40
(verifier findings on r2; section 6d)**. **r5 2026-10-06: heavy-lens support (J7-R float; section 6f, `R5-BRIEF.md`).** The blocks between
`BEGIN`/`END` markers are generated by `python cad/gs8-d2-v1/make_tables.py` from `layout.py`, the build receipt and
the print manifest; the text around them is maintained by hand. Nothing in D2 is printed, bought or measured: purchased parts are
proxies, and only computed checks may say "pass".

## 1. Status

| Item | State (**r5 release build 2026-10-06 16:32:38 +0800**: heavy-lens support, the J7-R float (`R5-BRIEF.md`; `RECTIFICATION.md` "r5"): the camera model is rebuilt to the official GS drawing, a printed per-lens `lens_collar` carries the lens on 3 M3 screws in tub inserts + a foot, the camera hangs on the lens; pins and turret deleted. Kowa, `--sweep-step 1.0`; receipt `out/build-receipt.json`, checks.json SHA-256 c9d748c8...; 17 of 17 sources, 101 of 101 outputs and 4 of 4 gate docs match the files on disk; the generated s3 block carries the full receipt status) |
|---|---|
| `cad_checks` | **computed: pass**: 27 of 27 checks, 749 rows (732 pass, 17 info, 0 failed), 0 stubs (section 3). New r5 categories: `inserts` 4, `j7_float` 11, `lens_support` 28 pass + 4 info (WARN: no support band is measured yet), `lens_clamp` 3 pass + 1 info (WARN: the Kowa's slip moment 0.170 N m is below the 5 g moment 0.286 N m; static ratio 2.97 >= 1.5). `critical_features` 135 rows = 125 pass + 10 info (incl. the J7 joint_check row; the 10 info as r4); `cable_routes` 8 pass + 2 info. `cad_release_candidate: true` means only that: computed CAD checks on proxies |
| `slicer_review` | **not run** (no slicer on this machine; none downloaded): 0 of 12 printed parts with a current recorded pass |
| `coupon_validation` | **not run** (27 coupon STLs exported, none printed): 0 of 10 items (7 coupon gates incl. r5's G-COL-1 + the calibration records G-KNOB-1, G-COMB-1, G-J4-1) |
| `measured_fit` | **not run** (every purchased part is a proxy; `MEASURED-PARTS.md` lists what to measure; r5: MP-CAM rewritten with its lens line): 0 of 17 gates |
| `assembly_operation` | **not run** (no dry assembly, no service cycle, no powered test): 0 of 26 items (incl. G-W13, r5's G-CAM-2 sag acceptance and the r4 whole-part halves `G-SNAP-2/whole`, `G-KEEP-1/whole`, `G-PANEL-1/whole`) |
| Hardware gates | 55 listed, 53 open, 2 withdrawn (G-SNAP-1, G-SKIRT-1): the gate-doc ids incl. EVF-G1..G9, G4b, G-MP-FPC, G-W13, r5's G-COL-1 and G-CAM-2, the calibration ids G-KNOB-1, G-COMB-1, G-J4-1, and the 3 `/whole` items; receipt `hardware_gates` |
| Printed parts | 12 (generated count: s1.1; r5 adds the `lens_collar`, one per lens with a support band; r1 had 12 with the 2 skirts, r2-r4 11); all real CadQuery solids, 0 stubs |
| Purchased parts | 20 COTS proxies + 7 PT screws (4 enclosure + 2 keeper + the J4 lock s_j) + (r5) 4 M3 lens-collar screws with washers and heat-set inserts (`m3_hw`; generated counts incl. the separate X1203 kit screws/standoffs: s1.1), from datasheet, listing, drawing, repo or estimate |
| Second run | Fujinon lens, `--fast --sweep-step 1.0`, on the final r5 sources (`out/_fujinon-r5`, built 16:16:05): 27 of 27 checks pass, 746 rows (729 pass, 17 info, 0 failed); its STLs differ from the Kowa build only in its own `lens_collar` (`out/checks-fujinon-sweep1mm.json`, SHA-256 83b55def..., hash-linked in the receipt) |
| r5 geometry vs r4 | changed: `tub` (lip dia 32.4 + BFAR counterbore dia 37.5 instead of the dia 36.5 bore, no pins, 3 M3 insert bosses; 96.4 -> 96.6 g), `hood` (no turret, 4 foot holes dia 8.6, roll fin + 2 webs; 64.6 -> 51.7 g), `panel` (camera keeper moved to x -30.67..-27.34; 46.5 g); new: `lens_collar` (17.0 g Kowa / 18.6 g Fujinon, about 0.95 h) and the tub modifiers `tub__mod_s_c1..3` (15 -> 18 modifier meshes); the other production STLs (8 of them) and 15 modifiers byte-identical to r4. Coupons: 3 new for G-COL-1 (`collar_tub_front`, `collar_hood_plate`, `collar_part`); `hood_ledge_ret` re-triangulated only (same volume and bounds: the TL insert boss edge meets its cut plane); the other 23 identical. r4 outputs: `out/_r4-2026-10-06/` and `baseline-r4-2026-10-06.zip` |
| Audit findings 1-8 | all accepted; 1, 2, 3, 6 rectified in CAD (physical gates open); 4, 5 dependent on hardware; 7 docs + options presented; 8 receipt states. Per finding: `RECTIFICATION.md` |
| User decisions open | the lens (r5: both the Kowa and the Fujinon build and pass with their own collars; every lens needs a fixed band under J7-R regardless of mass, a zoom one of at least 15 mm); the black band (16 -> 8 mm, audit finding 3: the band could come back only through R2's rejected option (b), removable barb-free skirts at +2 printed parts, NOTES.md "r2 R2 options"; not OPTIONS.md (b), which is the shorter FPC); OPTIONS.md (b) 150 mm FPC ((a), 18/24 in the menu, was declined by the user on 2026-10-05: the 18/24 stays a physical switch); the EVF feed: option A diode or option C 4.55 V LDO as the primary feed (WIRING s4.8; BOM D2-16R/C/P at quantity 0) |
| Next gate | in this order (HANDOFF s5): measure the parts, **first MP-CAM with its lens line (G-CAM-1, G-LENS, r5) before any collar is printed**, and run the EVF bench assembly incl. G-W6 (MEASURED-PARTS); print and run the coupons (PRINT-GUIDE s6: G-PT-1, G-KEEP-1, G-PANEL-1, G-CAP-1, G-EVF-2, G-SNAP-2, r5's G-COL-1, and the s6.1 calibration records G-KNOB-1, G-COMB-1, G-J4-1); then the print set; then G-CAM-2 on the assembled camera and G-W12 |
| Still open in CAD (r2 fixer) | the cap detent strip is 1.25-1.5 (a gated `flexure` exception, G-CAP-1); the hood plunger-channel web 1.08 (a named exception); RECTIFICATION "Fixer pass". r5: the `lens_clamp` Kowa 5 g WARN (until G-COL-1 measures the pinch) and the `lens_support` band-status WARNs (until G-LENS) |
| r1 outputs | `out/_r1-2026-10-04/` and `baseline-r1-2026-10-04.zip` (r1 receipt 2026-10-04 14:15:51) |

### 1.1 Counts (generated, r3: the one authoritative count table)

Audit 2026-10-05 correction 1D. The shared counts below are computed by `make_tables.py` from source (`layout.py`, the
coupon manifests, `MEASURED-PARTS.md`, the ASSEMBLY s1.1 toolset table); other docs point here instead of restating
them, and `make_tables.py --check` lints the handwritten count phrases left in the D2 docs against this table.
The X1203 kit screws and standoffs are purchased with the UPS board and are not body screws.

<!-- BEGIN:counts -->
Generated by `make_tables.py` from source; the other D2 docs point here instead of restating these totals. `make_tables.py --check` lints handwritten count phrases against this table.

| Count | Value | Detail | Source |
|---|---|---|---|
| Printed production parts | **12** | `tub`, `hood`, `panel`, `base_grip`, `cap`, `plunger`, `knob_exp`, `knob_fps`, `eyecup`, `stick_sleeve`, `pi_keeper`, `lens_collar` | `layout.PARTS` |
| PT 3.0 x 12 PH1 body screws | **7** | step 3: `s_j`; step 4: `s_k1`, `s_k2`; step 8: `s_b1`, `s_b2`, `s_r1`, `s_r2` | `layout.SCREWS` kind PT (`layout.pt_screw_ids()`) |
| M3 lens-collar screws (ISO 7045 PH1 + washer, into heat-set inserts) | **4** | step 7: `s_c1`, `s_c2`, `s_c3`; step 8: `s_c4` | `layout.SCREWS` kind M3 |
| X1203 kit M2.5 screws (UPS kit, not body screws) | **8** | 8 x M2.5 x 5 pan, PH (kit): 4 down through the Pi, 4 up through the X1203 | `layout.X1203_KIT['screws']` |
| X1203 kit standoffs (UPS kit) | **4** | 4 x M2.5 F-F hex 5 AF brass, 10.9 long (stack gap estimate; kit length on receipt) | `layout.X1203_KIT['standoff']` |
| Coupon STLs | **27** | 23 (`out/coupons-manifest.json`, 28 pieces by qty) + 4 (`out/coupons-r1-manifest.json`, 4 pieces by qty); 27 STL files in `out/stl/coupons/` | coupon manifests |
| Measured-part records | **10** | MP-PACK, MP-X1203, MP-CAM, MP-HDMI, MP-RUN, MP-EVF, MP-ENC, MP-SW, MP-STICK, MP-FPC | `MP-*` ids in MEASURED-PARTS.md |
| Harnesses (cables) | **10** | `fpc`, `hdmi`, `usb_5v`, `oled_flex`, `qt`, `run_lead`, `fps_lead`, `pigtail`, `fan`, `pack_lead` | `layout.CABLES` |
| Assembly tool categories | **17** | ASSEMBLY.md s1.1 rows 1-17 | ASSEMBLY.md s1.1 table |
| Assembly steps | **10** | 2 bench, 8 in the body | `layout.STEPS` |
<!-- END:counts -->

## 2. What D2 is

The D2 "Integral, refined" concept (`concepts/nizo-evf-2026-10-03/D2/CONCEPT.md`), developed into CAD with computed
checks on purchased-part proxies. Print and assembly readiness are open: `status_states` slicer_review,
coupon_validation, measured_fit and assembly_operation are all "not run". The design:
- a satin-silver ASA tub (open to the left) and dial panel, a black hood (roof, eyepiece housing, front plate; r5: no turret) and (r5) a black printed lens collar that carries the lens;
- a black base + grip in one print on 2 keyhole tongues, with a sliding battery cap (r2: no skirts);
- 7 x PT 3.0 x 12 PH1 screws in the whole body (4 close the enclosure, 2 hold the removable Pi keeper, r2, 1 locks the
  base slide, r2 fixer), plus (r5) 4 M3 PH1 lens-collar screws in brass heat-set inserts. "One PH1" covers the **screws only**: the whole build also needs a soldering iron, a socket,
  a saw and file, tweezers, 2 hood release pins, a torque screwdriver, the printed collar centring gauge and more
  (ASSEMBLY s1.1, 17 tools since r7);
- Pi 5 + Active Cooler on a Geekworm X1203 (pogo pins) flat on the floor, located by 4 bosses and held by a removable
  printed keeper (r2); GS camera hanging on the lens (r5, J7-R float; r1-r4: on 2 pins); EVF-A at the rear top;
  USB SSD stick out of a rear scoop; 1S2P 18650 pack + XT30 in the grip;
- controls: run button (GPIO26), exposure encoder (I2C 0x37), 18/24 rotary (GPIO13), power plunger on the Pi button.
  I/O = exposure dial (encoder, with its push switch), 18/24 dial, power plunger (on/off), run (record) button and the EVF; **no LED indicators** (user decision 2026-10-05: the plunger is black ASA, no light pipe; the Pi 5 onboard LEDs are switched off in config.txt; power-on and shutdown are shown on the EVF, WIRING s8).
Body 154 x 70 x 100 mm. Single source of truth: `layout.py`; contract and interfaces: `SPEC.md`.

## 3. Build results

<!-- BEGIN:checks -->
Source: `out/build-receipt.json`, built 2026-10-09 05:56:23 +0800 (--skip-renders --sweep-step 1.0). CAD release candidate (computed checks only, not a hardware or finished-camera claim): **True**. Stub parts: none.

| Evidence state | Status |
|---|---|
| `cad_checks` | computed: pass (34 of 34 checks, 960 rows) |
| `slicer_review` | not run |
| `coupon_validation` | not run |
| `measured_fit` | not run |
| `assembly_operation` | not run |

Open evidence: slicer_review (not run: 12 item(s)), coupon_validation (not run: 10 item(s)), measured_fit (not run: 17 item(s)), assembly_operation (not run: 29 item(s)).

| Check | n | passed | failed | stub | info | status |
|---|---|---|---|---|---|---|
| contract | 38 | 38 | 0 | 0 | 0 | pass |
| cots_containment | 20 | 20 | 0 | 0 | 0 | pass |
| interference | 62 | 62 | 0 | 0 | 0 | pass |
| mate_overlap | 42 | 42 | 0 | 0 | 0 | pass |
| clearance | 13 | 13 | 0 | 0 | 0 | pass |
| keepouts | 109 | 109 | 0 | 0 | 0 | pass |
| cable_routes | 10 | 8 | 0 | 0 | 2 | pass |
| lead_access | 9 | 9 | 0 | 0 | 0 | pass |
| mate_reach | 6 | 5 | 0 | 0 | 1 | pass |
| cable_stow | 7 | 1 | 0 | 0 | 6 | pass |
| header_housings | 10 | 10 | 0 | 0 | 0 | pass |
| bed_fit | 12 | 12 | 0 | 0 | 0 | pass |
| stl_mesh | 12 | 12 | 0 | 0 | 0 | pass |
| print_modifiers | 18 | 18 | 0 | 0 | 0 | pass |
| print_overhang | 13 | 13 | 0 | 0 | 0 | pass |
| thin_wall | 12 | 12 | 0 | 0 | 0 | pass |
| critical_features | 141 | 131 | 0 | 0 | 10 | pass |
| evf_restraint | 8 | 8 | 0 | 0 | 0 | pass |
| driver | 11 | 11 | 0 | 0 | 0 | pass |
| engrave_groove | 10 | 10 | 0 | 0 | 0 | pass |
| boss_geometry | 7 | 7 | 0 | 0 | 0 | pass |
| inserts | 4 | 4 | 0 | 0 | 0 | pass |
| j7_float | 50 | 50 | 0 | 0 | 0 | pass |
| roll_catch | 59 | 58 | 0 | 0 | 1 | pass |
| lens_support | 42 | 37 | 0 | 0 | 5 | pass |
| lens_clamp | 6 | 4 | 0 | 0 | 2 | pass |
| sweeps | 14 | 14 | 0 | 0 | 0 | pass |
| handling | 17 | 14 | 0 | 0 | 3 | pass |
| mate_paths | 13 | 13 | 0 | 0 | 0 | pass |
| removals | 13 | 13 | 0 | 0 | 0 | pass |
| service_driver | 11 | 11 | 0 | 0 | 0 | pass |
| release_access | 2 | 2 | 0 | 0 | 0 | pass |
| stack_retention | 1 | 1 | 0 | 0 | 0 | pass |
| layout_self_check | 188 | 188 | 0 | 0 | 0 | pass |
| mass_com |  |  |  |  |  | info |

| Lens | Total mass (g) | CoM (x, y, z) | CoM ahead of the grip axis (mm) | CoM above the grip top (mm) |
|---|---|---|---|---|
| kowa_lm6hc | 896 | (-45.5, 0.8, 26.8) | +1.6 | 34.8 |
| fujinon_hf6xa | 783 | (-56.6, 1.0, 22.0) | -9.7 | 30.0 |

_Only computed checks may say "pass"; purchased parts are proxies and nothing is hardware-verified._
<!-- END:checks -->

No check failed and no part is a stub. r2 has 19 checks (r1: 15; new in r2: `critical_features`,
`evf_restraint`, `removals`, `service_driver`). What the passes cover (computed on proxies; nothing printed or measured):
- **critical_features** (new, finding 2; 82 rows): 74 structural sections measured on the B-rep (exact line/face
  intersection) at their narrowest points, all >= min_mm; 6 coverage rows (tub, panel, hood, base_grip, cap,
  pi_keeper each have structural entries); 2 named nonstructural exceptions reported, not used as a pass basis (panel
  `antirot_slot_skin` 0.8, `badge_glyph_ridge` 0.33). Smallest margins: hood hook beams and J2 lip 1.60 / 1.6, base
  keyhole lips 1.60 / 1.6, hood tooth roots 1.22 / 1.2, keeper finger tips 1.70 / 1.6, Pi boss walls 1.70 / 1.6, panel
  boss cap 1.30 / 1.2, panel end lands 1.30 / 1.2, cap key head tip 1.55 / 1.2, cap detent bump 1.60 / 1.2.
  `unclassified_thin_spots` (screen samples under the wall threshold that no entry covers): none.
- **evf_restraint** (new, finding 6): gap to first contact +X 0.25, -X 0.25 (tub groove walls), +Y 0.30 (panel stop
  rib, on bare PCB), -Y 0.30 (tub groove ends; 29 % of that contact is on the HDMI receptacle proxy: G-EVF-2), +Z 0.25,
  -Z 0.25 (tub groove floors); limit 0.6. r1 had 4.2 in +Y.
- **removals / service_driver** (new, findings 1 and 3): `keeper_out` (2 screws, slide +Y), `pi_out` (reverse L path,
  no latch) and `panel_off` (4 screws, pull +Y, strap, cap, pack, lens and stick fitted: geometry evidence only; r3: every service starts with the pack out, ASSEMBLY s7 P1-P4) sweep at 0 mm3 with no release
  zone; r2 fixer adds `hood_off` (release zones hk1-hk4 only), `camera_out`, `eyepiece_out`, `evf_out` and the coverage
  row "parts taken off" (every part an entry takes off has its own path or a named latch-free reason); s_k1, s_k2,
  s_b1, s_b2, s_r1, s_r2 pass the straight-driver audit in their service states.
- **stack_retention** (r2 fixer, verifier M-V-MPS-4): with the new hood post 0.15 over the far kit screw head the
  stack CoM (-54.5, -7.1) lies 16.7 mm inside the retention hull (r2: 16 mm outside); the largest rigid lift the gaps
  allow at a boss pocket is 0.10-0.19 (r2 without the post: up to 0.58), limit 1.9 (pocket 2.4 - 0.5).
- **release_access** (r2 fixer): a dia 1.5 pin from the right through each hood release hole reaches the hk1/hk2 tooth
  with 0 mm3 on any other part; at the 0.55 push the beam strain is 1.51 % nominal, 2.26 % with Kt (limit 2.5 %).
- **interference** (55 pairs, exact OCP boolean, tol 0.05 mm3) and **mate_overlap** (30 mates): the 2 declared
  interference mates (panel cap on the eyepiece spigot, eyecup sleeve) stay within their stated values.
- **clearance** (12 zones): J1 hooks 0.10 / 0.09 (hk3/hk4 measured normal to the 45 deg return faces); J2 0.25 /
  0.225; J4 0.25 / 0.225; J7 0.25 / 0.225; J8 1.25 / 1.125; **J9 keeper bridge over the panel bosses 0.25 / 0.225 (r2
  fixer; r2 had 0.20 and no zone)**; J10 0.25 / 0.225.
- **keepouts** (97 pairs; r4: 33 keep-outs incl. 6 cable link boxes): no printed solid enters a cable or plug keep-out.
- **cable_routes** (r4; 10 cables): every route is one continuous chain of keep-out boxes (passage >= 1.0 x 1.0
  between neighbours), both chain ends reach the cable's end parts within 1.0, and an estimated route length plus
  max(10 mm, 10 %) fits the cable. Tightest: the QT lead, 17.4 mm over route + allowance. Bend radius is not
  checked (bench: G-HDMI, MEASURED-PARTS). The fan lead and the OLED flex are direct (info).
- **print_modifiers** (r4; 15 meshes): every slicer modifier mesh (`out/stl/modifiers/`, FASTENER-POLICY 40 % round
  each pilot) overlaps its part.
- **thin_wall** (secondary screen since r2; a fail blocks, a pass proves nothing): sampled minimums tub 1.25, hood 1.30
  (r1 1.05), panel 0.80 (= the named antirot skin), base_grip 1.44 (r1 0.77), cap 1.60 (r1 0.70), pi_keeper 1.30,
  plunger 1.20, knob_fps 0.99 (index groove edge), eyecup 1.60, stick_sleeve 0.80 (`THIN_OK`).
- **driver** (bit dia 6.5 x 40 + handle dia 30 x 100): s_b1 / s_b2 bit 0.25 radial, handle 12.3 / 24.2 mm from the grip;
  s_r1 / s_r2 bit 0.25; s_k1 / s_k2 (step 4) bit 1.23 from the keeper counterbore wall, handle 20.1 / 38.5; s_j (step
  3) bit 0.25, handle 2.35 from the strap.
- **boss_geometry** (7 screws; r2 fixer: wall sampled at 7 levels over 5-95 % of the depth): pilot dia 2.50; depth 8.4
  (s_b) / 11.0 (s_r, s_j) / 8.6 (s_k, need 8.5); minimum wall round the pilot 2.50 / 2.75 / s_k1 2.55, **s_k2 2.35**
  (r2 2.60 at 30-70 % but 1.75 over the top 2 mm) / s_j 2.75 (need 2.25).
- **sweeps** (12 insertions incl. `keeper_in`; `pi_in` has no snaps now): 0 hits; the Fujinon run repeats them at 1 mm.
- **engrave_groove**, **bed_fit**, **stl_mesh**, **contract**, **cots_containment**, **layout_self_check** (129 rows): pass.

**CoM against the concept.** Kowa: 887 g, CoM 3.7 mm ahead of the grip axis (concept +1.5; r1 +4.0) and 34.6 above the
grip top. Fujinon: 772 g, CoM 8.9 mm behind the grip axis (concept -8.3 with the sleeve; r1 -8.7). The keeper and its 2
screws (8.3 g, low at the rear of the stack) move the CoM about 0.4 mm rearward. Both CoMs stay over the 48 mm grip
(x -71..-23). Not measured: the COTS masses are listed or estimated values.

## 4. Parts

### 4.1 Printed (12 since r5)

<!-- BEGIN:parts -->
| id | Module | Owner | Material, colour | Face down | Envelope (assembly frame) | Mass as printed (g) | Basis |
|---|---|---|---|---|---|---|---|
| `tub` | `printed_tub.py` | tub | ASA, satin silver | -Y | x -154..-2.7 / y -35..35 / z -3.6..97.3 | 96.5 | manifest (out/print-manifest.json) |
| `hood` | `printed_hood.py` | hood_panel | ASA, black | +Z | x -170.2..1 / y -32.5..35 / z 0.3..100 | 52.4 | manifest (out/print-manifest.json) |
| `panel` | `printed_panel.py` | hood_panel | ASA, satin silver | +Y | x -154..-2.7 / y -32.3..35 / z 2.6..97 | 46.5 | manifest (out/print-manifest.json) |
| `base_grip` | `printed_grip.py` | grip_small | ASA, black | +Z | x -117..-0.5 / y -35.2..35.2 / z -110..0 | 58.4 | manifest (out/print-manifest.json) |
| `cap` | `printed_grip.py` | grip_small | ASA, black | -Z | x -71..-23 / y -15..15 / z -116..-105.8 | 7.2 | manifest (out/print-manifest.json) |
| `plunger` | `printed_small.py` | grip_small | ASA, black | +X | x -5.3..-1.3 / y 2.2..15.8 / z 16.6..24.4 | 0.3 | manifest (out/print-manifest.json) |
| `knob_exp` | `printed_small.py` | grip_small | ASA, black | +Y | x -77..-49 / y 35.2..44.2 / z 43..71 | 5.1 | manifest (out/print-manifest.json) |
| `knob_fps` | `printed_small.py` | grip_small | ASA, black | +Y | x -133..-113 / y 35.2..42.2 / z 47..67 | 1.3 | manifest (out/print-manifest.json) |
| `eyecup` | `printed_small.py` | grip_small | TPU 95A, black | +X | x -187.6..-171.3 / y -7..39 / z 55..101 | 5.3 | manifest (out/print-manifest.json) |
| `stick_sleeve` | `printed_small.py` | grip_small | ASA, satin silver | -X | x -154..-138 / y -16.8..6.2 / z 17.9..30.9 | 1.2 | manifest (out/print-manifest.json) |
| `pi_keeper` | `printed_keeper.py` | tub | ASA, black | +Z | x -105..-41 / y -23..31.9 / z 7.7..15.6 | 6.6 | manifest (out/print-manifest.json) |
| `lens_collar` | `printed_collar.py` | tub | ASA (PC if G-W11 shows > 50 C at the camera), black | +X | x -2.7..8.6 / y -35..33.6 / z 30..96.1 | 17.3 | manifest (out/print-manifest.json) |
<!-- END:parts -->

**Print set (r2 geometry, r3 manifest):** 10 ASA parts + 1 TPU part (eyecup); 292.9 g as printed (368.5 g at 100 %
infill), about 15.7 h of printing (`out/print-manifest.json` totals). Both figures are **estimates** from the
manifest's mass and time models, not slicer results (tub 4.9 h, hood 3.3 h, base_grip 3.0 h, panel 2.4 h, the 7 small
parts 2.0 h). Supports: tub 2 small paint-on blocks, hood 2 tree supports; every other part needs no support by the
computed overhang check (slicer review not run). Every part fits both bed classes (computed bed_fit check).

Print settings, orientation and supports: `PRINT-GUIDE.md`.

### 4.2 Purchased (COTS proxies)

<!-- BEGIN:cots -->
| id | Part | P/N or class | Source | Mass (g) | Step |
|---|---|---|---|---|---|
| `pi5` | Raspberry Pi 5 (4/8 GB) | SC1111/SC1112 | datasheet RP-008347 | 46 | 4 |
| `cooler` | Raspberry Pi Active Cooler | SC1148 | datasheet RP-008188 | 25 | 1 |
| `x1203` | Geekworm X1203 UPS (pogo pins, XH lead to any 1S pack) | X1203 | listing; height estimate | 30 | 1 |
| `x1203_kit` | X1203 kit standoffs + screws | kit | listing (estimate) | 6 | 1 |
| `gs_camera` | Raspberry Pi Global Shutter Camera (tripod block removed at B0) | SC0926 class | official GS side drawing (gs_side.png) via R5 judge 3 s6.1; MP-CAM open | 34 | 7 |
| `c_cs_adapter` | C-CS adapter ring 5 mm (with the camera) | kit | GS drawing (dia 30.75 x 5.0 face to face; MP-CAM) | 4 | 7 |
| `lens` | C-mount lens (LENS parameter) | see LENSES | see LENSES | 215 | 8 |
| `eyepiece` | Display Components 0PE039-16X glass eyepiece | 0PE039-16X | repo EVF-SELECTION.md | 35 | 6 |
| `hmx039` | Hicenda HMX039-V1 micro-OLED + 50 mm flex | HMX039 kit | repo | 2 | 6 |
| `evf_board` | Hicenda HDMI driver board Rev I | HMX039 kit | repo; thickness estimate | 8 | 6 |
| `usb_stick` | SanDisk Extreme PRO USB 3.2 SSD stick | SDCZ880 | listing 71 x 21.3 x 11.4 | 22 | 9 |
| `encoder` | Adafruit 5880 I2C QT rotary encoder (A0 bridged, 0x37) | 5880 | listing; depth estimate | 8 | 2 |
| `switch_1824` | mini 2-position rotary switch + nut + washer | Lorlin CK1049 class | estimate | 12 | 2 |
| `run_button` | pre-wired momentary, red cap (Squid Button class) | Pi Hut Squid | estimate | 4 | 3 |
| `pack` | 1S2P 18650 pack, BMS, XT30 male lead, pull ribbon | class | estimate | 105 | 10 |
| `xt30_pair` | XT30 pair (pigtail female + pack male) + fused 18 AWG pigtail (cut length L_cut, PIGTAIL) with its inline 15 A fuse | XT30U; fuse Littelfuse 0251015.MXL | estimate; fuse body: Littelfuse 251 datasheet rev VL | 12 | 10 |
| `tripod_nut` | 1/4-20 UNC hex nut, steel | ISO 4032 class | standard | 4 | 3 |
| `strap` | 12 mm hand strap with buckle | class | estimate | 15 | 3 |
| `microsd` | microSD card (OS), 32 GB A2 class | consumable class | PALETTE.md: protrudes ~2-3 mm past the Pi edge (2.5 used); socket part inside the pi5 underside proxy is not modelled (proxy x -12.4..-3.5) | 0.4 | 5 |
| `pt_screws` | 7 x PT 3.0 x 12 PH1 | see FASTENER-POLICY | standard class | 5.6 | 8 |
| `foam_pad` | closed-cell foam 16 x 14 x 1.0 (OLED pad) | consumable | estimate | 0.1 | 6 |
| `m3_hw` | lens collar M3 hardware: 3 x M3 x 10 + 1 x M3 x 16 ISO 7045 PH1 A2, 4 x ISO 7089 M3 washers, 3 x M3 short heat-set inserts (tub) + 1 x M3 L 5.7 insert (collar lug) | ISO 7045 / ISO 7089 / heat-set insert class | standard class (FASTENER-POLICY s I, r5) | 4.8 | 7 |
<!-- END:cots -->

Prices, SKUs and every consumable and tool: `electronics/gs8-d2-v1/BOM.md`.

## 5. Interfaces

SPEC.md s3 (joints J1-J15 and the 4 PT screw stations) is the contract; `layout.py` now carries every change below
(marked `INTEGRATOR` in the source). Joints whose built geometry differs from SPEC s3:

| Joint | Built | Why |
|---|---|---|
| J1 hood -> tub | band right edge y -32.35 (was -32.0), envelope y0 -32.5; **r2: tooth land 0.4 -> 0.6, catch plane and ledges +0.2 (z 88.15)** | closes the 0.5 open slit along the roof's right edge; r2: the tooth root was 1.05, under MIN_WALL 1.2 for a lug in shear (now 1.25, `hood_tooth_hk*`) |
| J2 panel -> hood | rail web to y 23.9; 6 piers 3 wide; the panel tongue is 5 teeth (SLIDE 0.25 to the piers) | the hood prints roof down: the groove lip was a 6.25 overhang, now 21 mm bridges |
| J3 panel -> tub | front locate rib z 41.3..70 (was 40) | the rib box overlapped rib_l (top z 41) |
| J4 base -> tub | T-tongue -Y wings without the 45 deg end chamfer; 2 paint-on supports | the 45 deg end left a 0.65 feather in mid-air; one-sided tongues would change the J4 load path (tub T5: keep the T) |
| J5 skirts -> base | **eliminated (r2, finding 3)**: no skirts, no grooves, no barbs; plain base side faces; the 2 panel boss tabs fill the tub lip notches flush | the skirt_l barb had no release access and the panel could not open without it; the J5 key/groove sections were 0.68-0.77 |
| J6 cap -> grip | 2 keys rise inside the bay into grooves z -108.6..-106.25 in the side walls, closed at x -60, out through 2 front notches; detent bump; **r2: key head tip 1.55 (was 0.8), bump 1.6 x 1.2 (was 0.6), detent arm >= 1.25, groove-exit feather removed** | the bottom rails had nothing to hold; r2: finding 2 sections |
| J7 camera -> tub (r1-r4; pins deleted in r5) | pins at (y -15, z 75) and (15, 45) (other diagonal); rib_r deleted; rib_l is a 45 deg gusset out to the panel plane | the CS ring hit the (15, 75) pin on the -Y leg (7.2 mm3); rib_r lay over the Pi drop path (255 mm3) |
| J7 (r5: J7-R float) | the pins and the turret are deleted; the lens collar holds the lens on its fixed band and is anchored on the tub front face (s_c1..s_c3 into M3 inserts; LR foot); the camera hangs on the lens; tub lip, hood roll fin and panel keeper are catches with gaps (SPEC s3 J7; `j7_float`) | r1-r4's camera model did not match the official GS drawing, and a heavy lens hung on the camera's own mount (R5-BRIEF; RECTIFICATION r5) |
| J8 EVF | **r2: panel stop rib x -138.9..-136.3, z 70..86, 0.3 off the PCB +Y edge (`EVF_STOP`, finding 6)**; board slot: the bottom rail's -X wall exists only for y 0.7..3.7, the +X wall stops at ko_5v_end and the 18/24 switch; ko_5v_end x -136.5..-130.0 (+1) | the board's micro-HDMI receptacle sweeps the -X lip as it slides in; room for the 1N5817 splice and PH junction |
| J9 Pi stack -> tub | bosses OD 9.0 (r2), head pockets locate the stack; **r2: the 4 floor hooks are deleted; a removable printed `pi_keeper` on s_k1/s_k2 (PT 3.0 x 12) puts 4 rigid fingers 0.1 over the X1203 at the r1 hook stations**; L-shaped insertion path unchanged | finding 1: the hooks had no release access, so Pi service destroyed the tub |
| J10 plunger | flange 1.2 thick (x -2.5..-1.3) stops on the floor of a 0.4 recess in the tub front wall (travel 0.6 kept); the hood pocket is a channel open at the plate foot | MIN_WALL; the hood dropping at step 5 hit the old flange |
| J11 stick | sleeve wall 0.8 kept (`THIN_OK`); guide = 4-sided channel to x -131.5, then a floor rail with a 45 deg lip to x -94.5 | non-structural cover; ko_usb_evf leaves no room for upper and -Y walls |
| J12 controls | encoder cradle: 1 hook over the top edge + 2 on the x edges at z 45..50, teeth 0.55; 18/24 shaft cut to y 42.0; knob_fps 32 teeth | a hook under the PCB sat in ko_hdmi_run; the knob top is y 42.2; 40 teeth failed the thin-feature screen |
| J13 run button | switch drops into a cradle through the base opening; the red cap is pressed on through the dia 13.6 grip-face hole | the cap cannot pass the wall on the switch (needs a cap that comes off the stem: bench gate G-RUN-1) |
| J14 vents | the exhaust baffle is deleted; exhaust = 2 front-wall windows + hood plate slots + right-wall slots | the baffle box lay over the Pi PCB edge, so any wall there blocks the stack drop |

## 6. Decisions

SPEC.md s8 (carried from the concept) and s9 (concept numbers changed, and why). Electronics decisions W-1 to W-8 are in
`electronics/gs8-d2-v1/WIRING.md` s3. Interface requests from the build (NOTES.md) and how the integrator resolved
them; every one is now in `layout.py`:

| Request | Decision |
|---|---|
| cots_build: x1203_kit box | grown to x PX1-64.4..PX1-0.6 (hex standoffs across corners) |
| cots_build: cable ends | `layout.CABLE_ENDS` + `ends` on every `CABLES` row (checks.py reads them) |
| cots_build: xt30_pair vs ko_xt30 | proxy box x -63..-37, inside the keep-out (the grip wall stays) |
| cots_build: panel_on vs skirt_l | option (a): skirt_l moves to step 8 with its own +X insertion `skirt_l_in` (r1; superseded: skirts eliminated in r2) |
| cots_build + hood_panel 1: hood envelope | `HOOD_BOX` y0 -32.5; band y0 -32.35 (closes the roof slit) |
| cots_build + grip_small 3: MIN_WALL | plunger flange 1.2 (tub recess 0.4); stick_sleeve 0.8 accepted in `THIN_OK` |
| cots_build: pi_in / rib_r; tub T2, T3 | rib_r and BAFFLE deleted; pi_in path per tub T2 (0 mm3) |
| cots_build: camera_in pin; tub T1 | T1 (pins on the other diagonal) instead of dx -14.1, which crossed ko_hdmi_run |
| cots_build: board_in | the tub's gapped -X wall (built); `bottom_rail_gaps` kept as the final-pose gap |
| cots_build: Pi hook t vs SPEC 1.6 | t 1.6 with the leaning slab (tub T4); no exception needed |
| docs: fan row, usb_5v name, ko_5v_end, STEPS[0] | all four adopted; STEPS[0] lists the 3 EVF-lead joints and a multimeter |
| docs: manifest key names | kept |
| hood_panel 2-5 | adopted as modelled (rib z 41.3, J2 piers + 5 teeth, plunger channel, encoder cradle hooks) |
| grip_small 1, 2, 4, 5 | adopted (skirt and cap envelopes, J5/J6 numbers, shaft cut at step 2, run-button and skirt_l text) |
| tub T4 (record), T5 | recorded; T5: keep the T-tongues and their 2 supports |

**Build-time deviations from the concept** (in addition to SPEC s9): rib_r and the exhaust baffle are gone; (r1: skirt_l
went on at step 8; r2: no skirts); the Pi stack enters on an L path, not a straight drop; knob_fps has 32 teeth (concept 40); the
hood's front-top edge is a 3.0 x 45 deg chamfer (concept fillet 5, the roof is the bed face); the camera pins used the
other diagonal (r1-r4; deleted in r5); bench solder joints are 12 (r4: + the 2 pigtail fuse-splice joints; +2 if the pack lacks an XT30) against the concept's 5 (+2 Rev I), because
the EVF 5 V lead gets a 1N5817 and a PH junction (WIRING W-3, W-4).

## 6b. Fixer pass 2026-10-04 (verifier findings)

Table in the r1 record (`out/_r1-2026-10-04/`, `baseline-r1-2026-10-04.zip`, HANDOFF.md s4). Superseded in r2: the
Pi hooks (G-SNAP-1), the skirt key and groove (P-P7), the share rule as the thin-wall pass basis (A-F6).

## 6c. r2 rectification 2026-10-05 (audit `audit/d2-readiness-2026-10-04/REVIEW.md`)

| Finding | Change (owner) | Evidence in the r2 build |
|---|---|---|
| 1 Pi service destructive | floor hooks deleted; removable `pi_keeper` on 2 PT screws, the same PH1 (R1; options in NOTES "r2 R1 options") | `removals` keeper_out, pi_out; `service_driver` s_k1/s_k2; `sweeps` keeper_in; `keeper_*` features; coupons G-KEEP-1 |
| 2 thin-wall coverage | CRITICAL_FEATURES registry + exact sections + missing-coverage FAIL (R3); skirt J5 removed, panel end land 1.30, cap retention >= 1.25, base_grip fixes (R2); hood tooth root 1.25 (integrator) | `critical_features` 82 rows; `unclassified_thin_spots` none |
| 3 skirt barb blocks the panel | skirts eliminated; panel = 4 PH1 screws + pull (R2) | `removals` panel_off with the strap fitted; coupons G-PANEL-1 |
| 4 power 27 W > 25.5 W | workload states, restrictions, fallback (R4, WIRING s4) | gate G-W12 (not run) |
| 5 interfaces not frozen | MEASURED-PARTS.md, G-MP-* (R4) | gates open |
| 6 EVF +Y restraint | panel stop rib (R2) + 6-direction check (R3) | `evf_restraint` 6 rows; section renders evf-board-x137 / z78 |
| 7 simplicity | OPTIONS (a), (b) presented, (c) applied as finding 3; toolset, PH1 scope, insert repair (R4) | BOM build counts |
| 8 release status | `cad_release_candidate`, `status_states`, `open_evidence`, `hardware_gates` (R3) | receipt |

## 6d. r2 fixer pass 2026-10-05 02:00-03:40 (2 verifiers' findings on the r2 rectification)

Per finding (M- mechanical, E- evidence/electrical): `RECTIFICATION.md` "Fixer pass". In short:
- **Service paths.** Hood: hk1/hk2 keep the 90 deg catch and get 2 dia 1.6 release holes in the right wall (2 pins
  hold them open, one at a time); hk3/hk4 get a 45 deg return catch (cam out on a straight lift); `hood_off`,
  `camera_out`, `eyepiece_out`, `evf_out` modelled; the 3 mm release blade is gone from the toolset. J4: its own lock
  screw s_j (step 3), so panel service no longer frees the base.
- **Sections.** s_k2 re-sited (y 28.25, r 3.6): wall 2.35 over the whole depth (was 1.75 at the top); feature classes
  set the minimum (hook/lug/lip/boss 1.6), which lifted the hood tooth (land 1.0: 1.62), the tub ledges (1.7 tall:
  1.65), the cap key head tip (1.65) and the panel boss cap (top 12.6: 1.6); the keeper bridge underside 12.85 keeps
  SLIDE over the panel bosses; EVF rail and collar entries added; the cap detent strip stays below 1.6 as a gated
  exception (G-CAP-1).
- **EVF board.** The bottom rail stands 1.0 clear of the receptacle and plug and 0.6 off the plug envelope in +X; the
  top rail is relieved 0.75 over the ZIF: the PCB is the first contact in all 6 directions (0.25-0.31).
- **Coupons.** G-KEEP-1 uses the whole keeper, a tub floor coupon with both keeper bosses and the 4 Pi bosses, and 2
  flat stand-in boards on the real X1203 kit; G-SNAP-2 adds the hk3 return hook and ledge.
- **Evidence.** Gate ids match as whole tokens; each evidence state lists its items and stays open until every item has
  a file with a recorded verdict; the EVF-SELECTION gates are in `hardware_gates`; the Fujinon run is on the final
  sources and hash-linked.
- **Docs.** WIRING s4: the S3 board estimate is 11-12.5 W (it was below the published CPU-only 9.8 W) plus an HDMI
  +5 V row: envelope 17.7-22.1 W, 0.8-2.3 W under the G-W12 P1 limit without the CPU cap; gate order G-W6 (before the
  freeze) -> print set -> G-W12; FASTENER-POLICY E per-boss drill table; MEASURED-PARTS: un-chosen variants marked as
  user procurement decisions, MP-FPC and the cooler line added.
- **Stack retention (M-V-MPS-4):** a post from the hood roof stops 0.15 over the far kit screw head; check
  `stack_retention` (CoM inside the retention hull, LP lift bound).
- **Rear-wall seam feather:** the eyepiece bore's teardrop roof ran out through the panel seam plane and left a 0.25
  feather in the tub rear wall end face; the end face is notched 1.2 deep there (behind the hood housing plate).
- **Not done (open):** the hood plunger-channel web (1.08, named).

## 6e. r3 docs corrections 2026-10-05 (audit `audit/d2-readiness-2026-10-05/REVIEW.md` corrections 1 and 4)

Documentation only; no geometry, check threshold or export changed by these edits.
- **Service isolation (correction 1):** ASSEMBLY s7 opens with the prerequisite P1-P4 (shut down, cap off, pack out,
  then the XT30 parted at the grip mouth) for every internal electronic service, panel-only included; a halted Pi is not established
  isolation (X1203 standby draw, downstream rail states unmeasured). Initial assembly connects the pack last (step 10,
  ASSEMBLY s1 "Power last"). The `panel_off` sweep with the pack fitted stays as geometry evidence only. No switch added.
- **Counts (correction 4):** s1.1 `counts` is generated from source; `make_tables.py --check` lints handwritten count
  phrases in the D2 docs (`lint_selftest()` keeps the r2 phrases the audit found in OPTIONS and PRINT-GUIDE as cases it must flag).
  Corrected: OPTIONS 7 PT screws (incl. s_j) and 10 measured-part records (incl. MP-FPC); PRINT-GUIDE s6 coupon
  count (r3: 20 from make_coupons.py, 4 from coupons_r1.py); s1 black-band option reference (R2's finding-3 option (b), not OPTIONS (b)).
- **Far-corner stack tilt:** ASSEMBLY s7 item 10 now says CAD restraint added (hood stack-stop post, `stack_retention`),
  physical tilt/retention test open (G-KEEP-1 follow-up).
- **Calibration records:** PRINT-GUIDE s6.1 names G-KNOB-1, G-COMB-1 and G-J4-1 and how to file them as evidence
  records (`evidence/README.md`). Not run.

## 6f. r5 heavy-lens support, 2026-10-06 (`R5-BRIEF.md`; study `research/r5-lens-support/`; log `IMPL-NOTES.md`)

User request: "Fix the sagging issue for the heavy lens first". The study found that the GS lens mount is milled
aluminium; the compliant link is the housing-to-PCB joint (2 small M2 screws, nylon washers, a gasket), and D2's r4
camera model did not match the official drawing (C flange 10 mm too far forward, no front lands, pins that located
nothing). Decision: the **J7-R float** (judge 3's spec, judge 1's details).
- **J7 contract.** The printed `lens_collar` holds the lens on its fixed rear band and sets its axial position with a
  45 deg cone; it is anchored on the tub front wall (TL, TR, LL bolted by s_c1..s_c3 into M3 heat-set inserts; LR a
  compression foot; the axis 16.0 inside the anchor polygon). The camera body, BFAR and adapter touch no printed part
  at any BFAR screw-out s 0..3.0; the tub lip (0.5 ahead of the BFAR face), the hood roll fin (0.8 to the cover) and
  the panel keeper (0.5 behind the cover at s 3.0) are catches. Any creep or flex in the printed parts moves lens and
  sensor together: an aim change, never a focus tilt.
- **Parts.** tub: lip + counterbore teardrops, 3 insert bosses (LL moved from (24.5, 36) to (28, 36) to clear the Pi 5
  box by 0.3), no pins. hood: no turret, 4 foot holes, roll fin + 2 webs. panel: keeper moved. New `lens_collar`
  (`printed_collar.py`, one per lens with a `support` band). `CAM` and the `gs_camera` proxy rebuilt as tagged
  sub-solids parametric in s; the tripod block comes off at bench step B0. `LENSES` corrected (Kowa focus ring at the
  rear, iris at the front, each with an M2 thumb screw; knurl dia 42 at +2.2..+7.6 is the fixed band); Computar
  H6Z0812 as a data-only entry.
- **Fasteners.** 4 M3 screws (ISO 7045, PH1) + washers into brass inserts (FASTENER-POLICY I); every `SCREWS` row has a
  `kind`; PT counts and PT checks apply to the PT kind only.
- **Checks.** `j7_float`, `lens_support`, `lens_clamp`, `inserts` (SPEC s6 5h), required by the J7 joint; the J7 ring
  zones, pins and turret rows were replaced by their real-camera equivalents (RECTIFICATION r5); `boss_geometry` is
  PT-only.
- **Order.** The brief's preferred order is used (no check broke): camera + adapter, then the collar (panel off) at
  step 7; the lens through the collar at step 8 while a finger holds the camera, then s_c4, then the panel; a level
  check at step 10.
- **Open, by design:** every `CAM` value is from the drawing or unconfirmed (MP-CAM), every lens band is unmeasured
  (G-LENS), and the clamp numbers are estimates (G-COL-1). G-CAM-2 is the acceptance test on the assembled camera.

## 7. Mass and centre of mass

Computed by `build_d2.py` from the solids (ASA 1.07 g/cm3 x `INFILL_FACTOR`) plus the COTS masses, for both lenses;
see the table in section 3.

**Balance statement for the lens review (r5 release build).** With the Kowa LM6HC (215 g) and its collar (17.0 g) the
computed CoM is 1.5 mm ahead of the grip axis, (-45.5, 0.8, 26.9), 34.9 above the grip top: still over the hand. With
the Fujinon HF6XA-5M (100 g) and its collar (18.6 g) it is 9.8 mm behind the axis, (-56.8, 1.0, 22.1), still over the
48 mm grip but toward its rear edge. Totals 895 g (Kowa) and 782 g (Fujinon); printed parts about 297 g (estimate).
r4 had +3.7 / -8.9 and 887 / 772 g: the real camera model puts the lens 10 mm further rearward (C flange x +0.6),
and the collars add 17-19 g ahead of the grip. The mass_com rules are unchanged (R5-BRIEF choice 10); judge 3's
proposed WARN band outside 0..+8 is not applied, and the Fujinon would WARN under it. The brief expected about +1.4
and about -11. All are estimates from proxies and listed COTS masses; weigh the parts.

## 8. Exports

All under `cad/gs8-d2-v1/out/` (r5 build 2026-10-06; the r4 outputs are in `out/_r4-2026-10-06/`, the r1 outputs in
`out/_r1-2026-10-04/`):
- `stl/<part>.stl`: 12 STLs in print orientation (r5: + `lens_collar`, the default lens's collar); SHA-256 in the
  manifest. `stl/modifiers/`: 18 slicer modifier meshes. `stl/coupons/`: 27 coupon STLs (23 from `make_coupons.py` +
  `coupons-manifest.json`, incl. r5's 3 G-COL-1 coupons; 4 from `coupons_r1.py` + `coupons-r1-manifest.json`).
- `step/gs8-d2-assembly.step` (Kowa) plus `step/parts/`.
- `print-manifest.json` (mass and time labelled estimates), `checks.json`, `build-receipt.json` (source SHA-256,
  `status_states`, `cad_release_candidate`, `open_evidence`, `hardware_gates`), `parts-manifest.json`,
  `checks-fujinon-sweep1mm.json` (copied from the `--fast --lens fujinon_hf6xa --sweep-step 1.0` run in `out/_fujinon-r5/`).
- `renders/`: `hero.png`, `exploded.png`, `xray.png`, `print-poses.png`, `step-01..10.png`, `section-lens-axis.png`,
  `section-evf-axis.png`, and the r2 sections `section-evf-board-x137.png` / `-z78.png` (EVF stop and 6-direction
  gaps), `section-pi-keeper-y-20.png` / `-y12.png` / `-x80.png` (keeper fingers), `section-base-edge-x91.png`, and
  (r5) `section-j7-y0.png` (cone seat on the knurl, the camera clear of lip, counterbore and keeper) and
  `section-j7-z90.png` (the TL / TR anchors).

The hero render keeps the D2 identity of the concept render (`concepts/nizo-evf-2026-10-03/D2/out/D2-hero.png`): black
hood with eyepiece housing (r5: the turret is gone; the black lens collar sits in its place), satin-silver tub and dial panel with the two knobs, black base and grip under the
front, red run button, EVF eyecup at the rear. **One visible change (r2, finding 3):** the black band under the panel
is now the 8 mm base only (the concept's 16 mm base + skirt band is gone); the tub lip and 2 flush boss tabs show silver
at the panel foot with 0.3 seams. The user decides whether to keep this or restore the band (R2 option (b), +2 parts).

## 9. Open items and bench gates

- CAD-side gates: SPEC.md s10: G-LENS and G-CAM-1 (r5: rewritten as MP-CAM with its lens line), r5's G-COL-1
  (collar coupons) and G-CAM-2 (sag acceptance on the assembled camera), G-EVF-1, **G-EVF-2** (r2 stop), G-PI-1 (keeper finger zones),
  G-PLG-1, G-PT-1 (incl. the 2 keeper bosses), **G-KEEP-1**, G-SNAP-2, **G-PANEL-1**, G-CAP-1, G-HDMI, G-RUN-1, G-ENC-1,
  mock-ups. Withdrawn in r2: G-SNAP-1 (Pi hooks), G-SKIRT-1 (skirts).
- Purchased-part gates: `MEASURED-PARTS.md` G-MP-PACK, G-MP-X1203, G-MP-EVF (EVF bench assembly before the carrier
  freeze), G-MP-ENC, G-MP-SW, G-MP-STICK.
- Electronics gates: WIRING.md s9 (G-W1 to G-W13; G-W13 = the EVF feed regulator bench qualification, r3; G-W12 = the full-workload power test of finding 4; G-W6 keeps the
  diode upper bound open).
- Print coupons: PRINT-GUIDE.md s6 (27 coupon STLs since r5).
- Open geometry items (no check fails on them):
  - R1-O1 / verifier M-V-MPS-4: in CAD, fixed by the hood stack-stop post (check `stack_retention`); physically open:
    bench tilt/knock test with the real stack and the printed hood (part of G-KEEP-1's follow-up, not run).
  - s_k2 is a marginal M3-insert repair site (1.6 wall round the 4.0 drill, exactly the minimum): FASTENER-POLICY E.
  - The panel antirot slot skin (0.8, 2 perimeters) waits for the measured 18/24 tab height (G-MP-SW).
  - The overhang screen (info only) lists the bridges and the 2 tub tongue wings; no print has been sliced.
- Not verified at all: any printed fit, snap strain, PT torque, service cycle, thermal behaviour, battery life, the
  power budget under load, and the lens choice.

## 10. Files and commands

| File | Role |
|---|---|
| `layout.py` | single source of truth (frame, envelopes, joints, screws, COTS, cables, keep-outs, steps) |
| `d2_common.py` | FDM constants and CadQuery helpers |
| `printed_tub.py`, `printed_hood.py`, `printed_panel.py`, `printed_grip.py`, `printed_small.py`, `printed_keeper.py` | printed parts (MODULE CONTRACT in `layout.py`) |
| `cots.py`, `checks.py`, `build_d2.py` | COTS proxies, checks, build + exports |
| `make_coupons.py`, `coupons_r1.py` | print-test coupons cut from the built parts (PRINT-GUIDE s6) |
| `RECTIFICATION.md`, `RECTIFICATION-BRIEF.md` | r2: per-finding status and evidence; the r2 task brief |
| `make_tables.py` | refreshes the generated tables in this file (incl. the s1.1 counts), PRINT-GUIDE.md, ASSEMBLY.md and WIRING.md (`--docs` to limit); `--check` also lints handwritten counts |
| `SPEC.md`, `FASTENER-POLICY.md` | the contract and the screw policy |
| `PRINT-GUIDE.md`, `ASSEMBLY.md` | how to print and how to build |
| `../../electronics/gs8-d2-v1/WIRING.md`, `make_bom.py`, `BOM.md`, `bom.csv` | wiring and bill of materials |

How to rebuild (repo root; every CadQuery process through `run_locked.py`, foreground):
1. `python cad/gs8-d2-v1/layout.py` (plain-python self-check, 129 checks, < 1 s).
2. `.venv-cad/Scripts/python.exe cad/gs8-d2-v1/run_locked.py -- cad/gs8-d2-v1/build_d2.py` (full: checks, STL, STEP,
   manifests, receipt, renders; about 250 s since the engraving grow and the new checks, peak about 1 GB). Options:
   `--fast` (no STEP or renders, about 210 s),
   `--lens fujinon_hf6xa`, `--sweep-step 1.0`, `--part <id> --fast` (one part).
3. `.venv-cad/Scripts/python.exe cad/gs8-d2-v1/run_locked.py -- cad/gs8-d2-v1/make_coupons.py` (coupons, about 4 min).
4. `python cad/gs8-d2-v1/make_tables.py` (then `--check` exits 1 if a generated block is stale) and
   `python electronics/gs8-d2-v1/make_bom.py`.

Commands (repo root): `python cad/gs8-d2-v1/layout.py`; `.venv-cad/Scripts/python.exe cad/gs8-d2-v1/run_locked.py --
cad/gs8-d2-v1/build_d2.py`; `python cad/gs8-d2-v1/make_tables.py`; `python electronics/gs8-d2-v1/make_bom.py`.

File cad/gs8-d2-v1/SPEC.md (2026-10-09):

# GS8 D2 release layer: CAD specification (`cad/gs8-d2-v1`)

> **Integrator, 2026-10-04:** the build changed some numbers in s3, s5 and s7 (interface requests in NOTES.md). They
> are in `layout.py` (marked `INTEGRATOR`) and listed in DESIGN.md s5-s6. Where this file and `layout.py` differ,
> `layout.py` wins.
>
> **r2 rectification, 2026-10-05** (audit `audit/d2-readiness-2026-10-04/REVIEW.md`; per-finding record in
> `RECTIFICATION.md`): the 2 skirts and J5 are eliminated; the 4 Pi floor hooks are replaced by a removable printed
> `pi_keeper` on 2 more PT screws (s_k1, s_k2); a panel rib stops the EVF board in +Y; the hood hook tooth land is 0.6;
> s6 adds the critical-feature, EVF-restraint, removal and service-driver checks; s6.5 is no longer a pass basis.
>
> **r2 fixer, 2026-10-05 02:00-** (verifier findings on r2; `RECTIFICATION.md` "Fixer pass"): hood hooks land 1.0
> (catch plane z 88.45/88.55, ledges 1.7 tall), hk1/hk2 get pin release holes, hk3/hk4 a 45 deg return catch; s_k2
> boss re-sited (y 28.25, r 3.6); panel boss tops 12.6 and the keeper bridge underside 12.85; EVF rails cut back round
> the HDMI plug and the ZIF; cap key top -105.8; the J4 lock screw s_j (7 PT screws); a hood post over the far kit
> screw head; the rear-wall bore roof notched 1.2 at the seam; checks: feature classes, release access, stack
> retention, hood/camera/EVF removals.
> Where this file still quotes an older number, `layout.py` wins.
>
> **r5, 2026-10-06: heavy-lens support** (`R5-BRIEF.md`; study `research/r5-lens-support/`; record `RECTIFICATION.md`
> "r5"). The camera model is rebuilt to the official GS drawing (the C flange is at x +0.6, not +10.6), and J7 becomes
> the **J7-R float**: a printed, per-lens `lens_collar` clamps the lens on its fixed rear band and is anchored on the tub
> front wall by 3 M3 screws in brass heat-set inserts plus a compression foot. The camera (housing, back-focus ring,
> adapter, PCB, cover) hangs on the lens and touches no printed part in service; the tub lip, a hood roll fin and the
> panel keeper are catches with gaps. The 2 camera pins and the hood turret are deleted. Now 12 printed parts and
> 7 PT + 4 M3 screws (s1, s2, s3, s5, s6, s10).

Written 2026-10-04 by the spec owner for the five build owners. **`layout.py` is the single source of truth**: every
number in this file is quoted from it, and if the two disagree, `layout.py` wins. `python cad/gs8-d2-v1/layout.py`
runs plain-Python consistency checks (126 rows, 0 failed in the r2 build of 2026-10-05). Nothing here is printed, bought or measured.
Purchased parts are proxies, so a "pass" can only come from a computed check, never from hardware.

Sources: the D2 concept (`concepts/nizo-evf-2026-10-03/D2/CONCEPT.md`, `build_concept.py`, `out/*.png`),
`research/PALETTE.md`, `electronics/gs8-evf-v1/EVF-SELECTION.md`, the FDM rules of `cad/gs8-release-v1/release_common.py`,
and the GS camera record in `cad/gs8-stills-v1/SPEC.md` (R1 s1.1-1.2).

## 1. Frame and datums

| Datum | Value | Note |
|---|---|---|
| Axes | X forward (toward the lens), Y to the operator's left (panel side), Z up | as in the concept |
| Origin | x 0 = hood front-plate outer face; y 0 = body centre plane; z 0 = tub floor underside | concept x is shifted by -77 (`cx()`) |
| Body | 154 x 70 x 100: x -154..0, y -35..35, z 0..100 | the base and grip hang below z 0 |
| Tub | rear face x -154, front face x -2.7, wall 2.5, front-wall inner face **x -5.2**, wall tops **z 97.3** | right-wall inner face y -32.5 |
| Panel | y 32.2..35 (2.8 thick), z 8.2..97.0 | the tub/panel joint plane is y 32.2 |
| Optical axis | y 0, z 60 | |
| Camera stack (r5, J7-R) | tub lip land x -3.9..-2.7; lip gap 0.5; back-focus-ring (BFAR) face = CS flange **x -4.4**; C flange **x +0.6**; housing front x -5.6 - s (s = BFAR screw-out 0..3.0, nominal 1.25); cover rear x -23.84 / -25.09 / -26.84 at s 0 / 1.25 / 3.0 | r4 had lands on x -5.2 and the C flange at +10.6 (a camera model that does not match the official drawing). The lens's axial position comes from the collar's 45 deg cone on the rear edge of its fixed band; the camera sets nothing |
| EVF axis | y 16, z 78; flange datum **F = x -154.0** on the tub rear face; display plane F + 6.0 = **x -148.0** | the cup lip is at x -187.6 (33.6 proud) |
| Grip | x -71..-23, y -15..15, z -110..-8; axis x -47; grip top (web of the hand) z -8 | er 9 |
| Base | x -117..-0.5, y -35.2..35.2, z -8..0 | 5 mm front chamfer |
| Tripod | 1/4-20 socket at x -107, y 0 | nut z -5.7..-0.1 |

## 2. Parts

**Printed: 12 parts (r5).** The concept had 10. r1 had 12 (2 separate skirts); r2 removes the skirts (finding 3) and adds the `pi_keeper` (finding 1); r5 adds the `lens_collar` (one per lens with a support band: the release exports the default lens's collar; a `--lens` build exports its own).

| id | module | material, colour | face down | owner | envelope (layout `PARTS`) |
|---|---|---|---|---|---|
| tub | printed_tub.py | ASA satin silver | -Y (right wall) | tub | x -154..-2.7, y -35..35, z -3.65..97.3 |
| hood | printed_hood.py | ASA black | +Z (roof) | hood_panel | x -170.2..1.0, y -32.5..35, z 0.3..100 (r5: no turret; was x ..8.5) |
| panel | printed_panel.py | ASA satin silver | +Y (face) | hood_panel | x -154..-2.7, y -32.3..35, z 2.6..97.0 |
| base_grip | printed_grip.py | ASA black | +Z (base top) | grip_small | x -117..-0.5, y -35.2..35.2, z -110..0 |
| cap | printed_grip.py | ASA black | -Z | grip_small | x -71..-23, y +-15, z -116..-110.1 |
| plunger | printed_small.py | ASA black | +X | grip_small | x -5.3..-1.3 |
| knob_exp | printed_small.py | ASA black | +Y | grip_small | dia 28 x 9 |
| knob_fps | printed_small.py | ASA black | +Y | grip_small | dia 20 x 7 |
| eyecup | printed_small.py | TPU 95A black | +X | grip_small | dia 46 x 16.3 (13 cup + 3.0 sleeve over the eye-end body) |
| stick_sleeve | printed_small.py | ASA satin silver | -X | grip_small | 22.9 x 13 x 16 |
| pi_keeper | printed_keeper.py | ASA black | +Z (top face) | tub (R1, r2) | x -105..-41, y -23..31.9, z 7.7..15.6 |
| lens_collar (r5) | printed_collar.py | ASA black (PC if G-W11 finds the camera zone above 50 C) | +X (front face) | tub | x -2.7..8.6, y -35..33, z 30..95.5 (Kowa; per lens from `layout.collar_spec`) |

**Purchased: 22 COTS rows (incl. the microSD proxy, FIXER A-F2, and r5's `m3_hw` lens-collar hardware row) plus 10 cables** (layout `COTS`, `CABLES`; the fan lead is the 10th). These are:
- Pi 5, Active Cooler, X1203 and its kit (4 standoffs, 8 M2.5 screws);
- GS camera and the C-CS adapter (r5: modelled from the official drawing as tagged sub-solids, `cots.gs_camera_parts(L, s)`; the
  camera's tripod block comes off at bench step B0 and is not modelled);
- the lens, set by the `LENS` parameter: `kowa_lm6hc` (default, 215 g) or `fujinon_hf6xa` (100 g); r5 adds the
  Computar H6Z0812 zoom (305 g) as a data-only entry (`LENSES_DATA_ONLY`: checked by `lens_support` / `lens_clamp`,
  never built);
- 0PE039-16X eyepiece, HMX039 panel, EVF board and foam pad;
- SDCZ880 stick, Adafruit 5880 encoder, 18/24 rotary, run button;
- 1S2P pack, XT30 pair, tripod nut, strap and 7 PT screws (4 enclosure + 2 keeper, r2, + the J4 lock s_j, r2 fixer);
- r5: the lens-collar hardware (`m3_hw`): 4 M3 screws, ISO 7045 PH1 (s_c1..s_c3 M3 x 10, s_c4 M3 x 16), 4 ISO 7089
  washers and 4 brass heat-set inserts (3 short in the tub bosses, 1 L 5.7 in the collar's lower lug); FASTENER-POLICY I.

## 3. Interfaces

Each row names the part that carries each feature. Clearances are per side.

| Joint | Carrier and features | Mating part | Clearance | Motion |
|---|---|---|---|---|
| J1 hood-tub | hood: 4 cantilever hooks (L 10.5, t 1.6, w 8, tooth 0.65 = reach 0.40, land 1.0 (r2 fixer; tooth root 1.65; hk1/hk2 90 deg catch + pin release hole in the tub right wall, hk3/hk4 45 deg return catch), 45 deg lead-in, 0.8 x 45 deg root gussets; strain 0.87 % nominal, 1.31 % with Kt 1.5, `layout.snap_strains()`) at hk1 x -45 and hk2 x -125 (right wall), hk3 y 22 (front wall), hk4 y -20 (rear wall) | tub: catch ledges 0.8 proud, z 88.55..90.25 (r2 fixer: +0.4, 1.7 tall; hk3/hk4 underside sloped 45 deg), 45 deg top chamfer; 2 dia 1.6 release holes at z 87.7 (hk1, hk2) | beam to ledge 0.25; tooth play 0.1 | hood straight down -Z |
| J1 seat | hood band underside z 97.3 on the wall tops; plate inner face x -2.5 (0.2 off the front wall); housing front x -154.2 (0.2 off the rear face) | tub | contact / 0.2 | |
| J2 hood-panel | hood: rail block x -134.5..-11.5, y 25.5..32.0, z 90.15..97.3; groove open +Y, z 91.75..94.85, lower lip with a 45 deg outer face | panel: top tongue x -134..-12, y 26..32.2, z 92..94.6 | 0.25 (groove) | panel along -Y |
| J3 panel-tub | panel inner face on the tub wall ends at y 32.2; 2 locating ribs inside the front and rear walls | tub: 2 lip notches (x -91 and -105, +-4.3) let the panel bosses pass | LOCATE 0.15 | panel along -Y |
| J4 base-tub | tub: 2 T-tongues under the floor at x -18 and -79 (8 long; head 36 wide z -3.65..-1.85, neck 26 wide z -1.85..0; -Y ends 45 deg) | base: window 10 mm ahead, neck slot through 1.6 lips, head pocket z -3.9..-1.6 | 0.25 | base on 10 mm back, then +X 10; **r2 fixer: locked by s_j** (PT up through the base into a tub floor boss at (-111, -20), step 3), independent of the panel screws s_b1/s_b2 |
| J5 skirt-base | **eliminated in r2** (finding 3): no skirts, no grooves; the base side faces are plain and the 2 panel boss tabs fill the tub lip notches flush | - | - | - |
| J6 cap-grip | grip: 2 dovetail rails z -110..-107 on the side walls; rear stop lip | cap: grooves + detent 0.4 | 0.25 | cap -X to close (+X opens) |
| J7 camera (r5: **J7-R float**; r4's seat, pins and turret are deleted) | **lens_collar** (per lens): bore = support band + 0.3 diametral, a 45 deg cone that takes the rear edge of the lens's fixed band (Kowa: the dia 42 knurl at C + 2.2..7.6, seat x 2.8), front at least 2.0 behind the first moving ring, -Y slit 2.0 closed by s_c4 (M3 x 16, -Z from above, into an insert in the lower lug); 4 feet dia 7.6 through 4 dia 8.6 hood holes onto the tub front face: TL (11, 90.5), TR (-11, 90.5) and LL (28, 36) bolted by s_c1..s_c3 (M3 x 10 + washer, -X from the front, into heat-set inserts in 3 tub bosses x -7.6..-5.2), LR (-19, 44) compression only; the lens axis is 16.0 inside the anchor polygon (rule 10). **Catches, never seats:** tub lip dia 32.4 (land x -3.9..-2.7, 0.5 ahead of the BFAR face) and BFAR counterbore dia 37.5; hood roll fin + 2 webs beside the cover; panel keeper x -30.67..-27.34 (0.5 behind the cover at s 3.0); rib_l, rib_r | the lens (on the cone) carries the hanging camera unit: GS housing + BFAR + C-CS adapter + PCB + cover | collar bore 0.15 radial; catches (check `j7_float`, s 0 / 1.25 / 3.0): body axial >= 0.4, lateral >= 0.5; BFAR axial >= 0.4, radial >= 0.6; adapter radial >= 0.6 | step 7: camera -Y through the open left side 11.1 back and 2 high, down 2, then +X 11.1 past the lip; collar +X 30 onto the face. Step 8: lens +X 40 through the collar into the adapter |
| J8 EVF | tub: rear-wall bore dia 29.3 + -Y half-collar x -151.5..-149.6; OLED cell (front ledge x -148.0, open +Y); board slot (2 grooves 2.1 wide, the bottom one gapped at y 3..18 for the HDMI plug: r2 fixer, 1.0 clear of the receptacle/plug, +X spine 0.6 off the plug envelope; top rail -X wall relieved 0.4 over the ZIF) | panel cap x -151.4..-145.0 (clamp r 14.4 = 0.1 crush; OLED finger to y 24.0); hood housing (1.25 radial round the barrel; +Y window x full, z 66..90) | 0.15 bore; cap 0.1 interference | eyepiece +X from the rear; OLED, board -Y |
| J9 Pi-tub | tub: 4 bosses OD 9.0 to z 6.0 with head pockets dia 5.6 x 2.4 (positive location in X/Y/Z; nothing else positions the stack); **r2: no floor hooks**. r2 fixer: a hood post (x -10.7..-6.5, y -31.3..-27.6, z 22.0 up to a fin under the roof) stands 0.15 over the far kit screw head (-9.5, -28.8) as a lift stop (no positioning load). Removable `pi_keeper` (printed, rigid) on 2 tub bosses (s_k1 (-99.5, 16.0), s_k2 (-64.0, 28.25) r 3.6 (r2 fixer: was 28.9 / r 3.5, +Y wall 1.75 over the top 2 mm), top z 9.8): 4 fingers at the r1 stations (USB edge y -20, 12; port edge x -80, -45), 0.65 over the X1203 edge, tip 1.6, underside z 7.7 = 0.1 above the X1203 | X1203 + Pi stack | keeper 0.1 (z) / 0.25 (xy) | stack on the L path, then keeper -Y, +X 1.2, down 0.5 |
| J10 plunger | hood: pocket 14.2 x 8.4 x 1.2 (x -2.5..-1.3) + opening 11.6 x 6.6 (guard lip 1.3); tub: hole 11.6 x 6.6 | plunger: stem 11 x 6, flange 13.6 x 7.8 x 0.8, nib dia 2.5 on the button (y 5.3, z 21.0) | 0.3; nib 0.25 to the button; travel 0.6 (press 0.35 of 0.45) | in from the front before the hood |
| J11 stick | tub: rear scoop 29 x 20 x 10 deep; guide x -148.6..-94.5 (sleeve section to x -138) | sleeve: 0.8 wall, end flush x -154 | 0.25 | stick +X |
| J12 controls | panel: encoder cradle (2 hooks on the PCB back y 24.1), hole dia 7.5; switch hole dia 10.0 + anti-rotation slot 1.7 x 3.0 x 2.0 at 12 o'clock r 7.9; engraving 0.4 deep | encoder, switch (nut outside), knobs (D bores) | 0.25 | bench (step 2) |
| J13 grip | base_grip: run-button cradle behind the front wall (hole dia 13.6 in a 12 x 28 pad 1.5 deep); base opening x -45..-25.5, y -13..9; nut pocket AF 11.4 from the top (bearing wall 2.3); strap slots (2 in the base x -76.5/-82.0, 2 in the grip heel z -104/-97) | run button, nut, strap | 0.15-0.25 | bench (step 3) |
| J14 vents | hood: roof inlet x -71..-45, y -24..4 (7 slots); plate band y -26.5..17.5, z 25.9..29.7 (13 slots); corner field. tub: matching front-wall windows; right-wall slots (exhaust x -19..-5, X1203 x -65..-49); baffle | | slot 2.0, web >= 1.4 | |

**Screw stations** (layout `SCREWS`; `head_point` is the head bearing face; `axis` is the advance direction). r5: every
entry has a `kind`: **PT** (the 7 body screws, the first 7 rows; PT checks and counts apply to them only) or **M3** (the 4
lens-collar screws s_c1..s_c4, machine thread into brass heat-set inserts, checked by `check_inserts`). The
straight-driver audit applies to every kind.

| id | head point | axis | through / into | engagement | step |
|---|---|---|---|---|---|
| s_b1 | (-91, 27.85, -2.0) | +Z | base counterbore dia 7 x 6 deep, base 2.0, floor 2.5, then panel boss_b1 (z 2.6..12) | 7.4 | 8 |
| s_b2 | (-105, 27.85, -2.0) | +Z | as s_b1, into boss_b2 | 7.4 | 8 |
| s_j | (-111.0, -20.0, -2.0) | +Z | base counterbore dia 7 x 6, then the tub floor + J4 lock boss (OD 8, z 0..12.6), r2 fixer | 10.0 | 3 |
| s_r1 | (-31.5, -32.4, 85.5) | +Y | right wall + 2.0 pad, counterbore dia 7 x 2.6, then panel post_f (8 x 8) | 10.0 | 8 |
| s_r2 | (-143.5, -32.4, 47.5) | +Y | as s_r1, into post_r | 10.0 | 8 |
| s_k1 | (-99.5, 16.0, 14.3) | -Z | keeper counterbore dia 7, then tub keeper boss (top z 9.8), r2 | 7.5 | 4 |
| s_k2 | (-64.0, 28.25, 14.3) | -Z | keeper spot-face notch 7.0 wide, then tub keeper boss (marginal M3-insert site, FASTENER-POLICY E), r2 | 7.5 | 4 |
| s_c1 (M3, r5) | (3.3, 11.0, 90.5) | -X | M3 x 10 + washer: collar counterbore dia 7.5 (x 2.8..8.6), the TL foot, then the short insert in the tub TL boss (x -2.8..-6.8) | 3.9 | 7 |
| s_c2 (M3, r5) | (3.3, -11.0, 90.5) | -X | as s_c1, TR foot and boss | 3.9 | 7 |
| s_c3 (M3, r5) | (3.3, 28.0, 36.0) | -X | as s_c1, LL foot and boss | 3.9 | 7 |
| s_c4 (M3, r5) | (4.7, -31.3, 66.5) | -Z | M3 x 16 + washer on the upper-lug top (spot face), clearance 3.4 through the upper lug, across the slit, into the L 5.7 insert in the lower lug (z 50.1..55.8); the pinch; the last operation on the lens | 5.3 | 8 |

## 4. Print rules per part (all parts: the FDM rules in `layout.FDM` / `d2_common`)

- **tub (-Y, right wall on the bed).** Print-up is +Y.
  - Every internal feature grows from the right wall, or has its -Y faces at 45 deg or steeper: ribs, bosses, hooks,
    ledges, the saddle, the cell, the board rails, the guide and the baffle.
  - The tongues' -Y ends are already 45 deg in `keyhole_tongue`.
  - Horizontal holes over 8 mm in the walls need a teardrop roof toward +Y; the dia 29.3 bore and (r5) the dia 32.4
    lip and dia 37.5 counterbore are in X-normal walls, so the roof points +Y. The 3 r5 insert bosses are teardrop
    prisms (apex -Y) growing from the front wall; the LL boss has a flat chin at y 24.0.
  - No supports.
- **hood (+Z, roof on the bed).** The hooks and the rail block print upward. Supports only at the housing's interior
  ceiling (39 mm span). r5: the turret and its support are gone; the 4 collar foot holes (dia 8.6) are teardrops with
  the apex -Z, and the roll fin and its 2 webs grow from the roof. A 45 deg form that needs no support is also
  allowed. Roof slots are vertical holes.
- **lens_collar (+X, front face on the bed; r5).** No supports: the ears, lugs and feet grow -X, the cone prints as a
  45 deg inward step, and a 0.6 bed chamfer runs round the outer edge of the front face. The only downward faces are
  the 3 washer-seat bridges and the s_c4 holes (test_collar). Production/coupon STLs include print-only 0.2 mm membranes across the anchor holes; clear them to 3.4 mm before assembly. The STEP model and assembly checks use the cleared finished geometry. ASA; PC if G-W11 finds the camera zone above 50 C.
- **panel (+Y, face on the bed).**
  - The engraving is cut 0.4 deep into the bed face; text at least 3.0 high, strokes at least 0.6.
  - The posts, bosses, tongue, cradle, cap and keeper all grow upward.
- **base_grip (+Z, base top on the bed; the part prints upside down).**
  - The lips are the first 1.6 mm of the print. The head pocket ceiling bridges 18.5 mm the short way.
  - The nut pocket opens on the bed.
  - The grip column rises 102 mm, with the cap rails at its top.
  - Bay bridges stay at 30 mm or less.
- **pi_keeper** prints on its top face, no supports (finger backs 45 deg); **cap** prints on its bottom face; **plunger** prints on its front face.
- **Knobs** print on their top faces, with the knurl vertical.
- **eyecup** (TPU) prints on its base ring. The flare is 15 deg, so it needs no support.
- **sleeve** prints on its end face.
- **Beds.** Every envelope fits both beds (`layout.self_check`). The STLs are checked again by `build_d2.py`.
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

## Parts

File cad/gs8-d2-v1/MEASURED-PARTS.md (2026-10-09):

# GS8 D2: measured-parts record (`cad/gs8-d2-v1`)

Written 2026-10-05 (r2, R4) in response to audit finding 5 (`audit/d2-readiness-2026-10-04/REVIEW.md`). **Status of
every record: not measured.** Nothing has been bought. Every value in the "CAD value" column is a proxy from
`layout.py`, a listing or an estimate. No gate here is closed in CAD, and none can be.

How to use it:
- One record per purchased part whose real dimensions or behaviour decide printed geometry or the assembly.
- On receipt, fill in the "Measured" column (calipers 0.01 mm, three readings, report the largest for envelopes and
  the smallest for holes/bores), take the photographs, and file both under `measured/<record id>/` next to this file.
- If a measured value falls outside the pass criterion, change only the listed `layout.py` names, rebuild, and re-run
  the listed checks. Do not touch parts that the measurement does not affect.
- **Order:** MP-PACK, MP-X1203, MP-CAM, MP-HDMI and **MP-EVF (bench assembly)** come before the full print set.
  MP-EVF in particular must pass **before the EVF carrier is frozen** (tub collar and board slot, panel cap, hood
  eyepiece housing). The coupons of PRINT-GUIDE s6 can be printed in parallel.
- **r6 (audit 2026-10-06 M2): the order is now one table and the build enforces it.** `layout.PRINT_PREREQS` lists,
  per printed part, the gates of the "Blocks" column below plus G-COMB-1 (and G-KNOB-1, G-COL-1 where they apply).
  PRINT-GUIDE s7 is generated from it. A slicer record filed before those gates have a current recorded pass is
  rejected, and the receipt's `print_release` names what still blocks each part. Record the camera and its lens
  together at B0 (G-CAM-1 and G-LENS): the tub, hood, panel and collar wait for both.

Gate ids: `G-W*` are in `electronics/gs8-d2-v1/WIRING.md` s9, `G-*` in `SPEC.md` s10 and DESIGN s9. The EVF gates of
`electronics/gs8-evf-v1/EVF-SELECTION.md` s3 (its `G1`-`G9`, `G4b`) are written **`EVF-G1` ... `EVF-G9`** here and in
the build receipt (r2 fixer, verifier E-V-E5: the receipt's `hardware_gates` now lists them, source EVF-SELECTION.md
hashed). `G-MP-*` ids are new here (r2).

**Status (r3, 2026-10-05).** Done on this machine: the CAD proxies in `layout.py`, the computed CAD checks, this
record and its pass criteria. **Not done:** procurement (no part ordered or received), printing or slicing, any
measurement or photograph, any bench assembly or power-up. Every "Measured" field is empty and every gate here is
open.

**r5 (2026-10-06, heavy-lens support).** MP-CAM is rewritten for the real GS camera stack and gains the lens line
(G-LENS). It must pass **before the tub, hood, panel or lens collar is frozen or printed**: the collar's bore and cone come straight from the lens
band, and the tub lip, counterbore, hood roll fin (superseded r7: hood tab catch) and panel keeper from `CAM`. The camera and lens are measured
together at bench step B0 (ASSEMBLY s2: tripod block off, back focus s set with the Kowa at infinity). The new
collar coupon gate G-COL-1 and the assembled sag acceptance G-CAM-2 are in SPEC s10.

**Exact variants (r2 fixer, verifier E-V-E7).** Where a record names only a class, the field now says
**"variant NOT chosen: procurement decision (user)"**: MP-PACK, MP-HDMI, MP-RUN, MP-SW and MP-FPC (length). These are
open user decisions (HANDOFF s5). The class text stays as the specification the order must meet.

## Summary

**Record count (r3): 10.** One record = one `## MP-<ID>:` section below, and every summary row starts with that
record's id: MP-PACK, MP-X1203, MP-CAM, MP-HDMI, MP-RUN, MP-EVF, MP-ENC, MP-SW, MP-STICK, MP-FPC. The Active Cooler
line is a second row of **MP-X1203** (measured in that record), not an eleventh record; likewise (r5) the lens line
is a second part of **MP-CAM** (the camera hangs on the lens, and both are measured together at bench step B0). Count rule for tools: the
number of distinct `^## MP-[A-Z0-9]+:` headings.

| Record | Part (BOM line) | Gate(s) | Drives (layout.py) | Blocks |
|---|---|---|---|---|
| MP-PACK | 1S2P 18650 pack (D2-13) | G-W1, G-MP-PACK | `COTS['pack']`, `CABLES` `pack_lead`, `COTS['xt30_pair']`, `KEEPOUTS['ko_xt30']`, `GRIP`, `CAP` | grip print |
| MP-X1203 | Geekworm X1203 + kit (D2-03) | G-W2, G-PI-1, G-MP-X1203 | `COTS['x1203']`, `X1203_KIT`, `PI`, `PI_BOSS`, the stack retention (r2: R1's `pi_keeper` and s_k1/s_k2, which replace `PI_HOOKS`), pigtail keep-outs, r7 `PIGTAIL` (pad, cut length) | tub print |
| MP-CAM | GS camera (D2-05); r5 lens line: the lens (D2-06) | G-CAM-1, G-LENS (r5: + G-COL-1 coupons, G-CAM-2 assembled) | `CAM` (+ `CAM['status']`), `cots.gs_camera_parts`, `COTS['gs_camera']`; lens line `LENSES[...]['support']`, `collar_spec` | tub, hood, panel and lens-collar print |
| MP-HDMI | micro-HDMI 90 deg lead (D2-21) | G-HDMI, G-W7, G-EVF-3 (r7) | `CABLES` `hdmi`, `ko_hdmi_*`, `EVF['board_slot']`; r7: `PLUGS` `p_hdmi_evf` (head, stroke), `ACCESS` `acc_hdmi_evf_*` | tub, panel print |
| MP-RUN | run button (D2-12) | G-RUN-1 | `RUN_BTN`, `COTS['run_button']`, `CABLES` `run_lead` | grip print |
| MP-EVF | Hicenda kit + 0PE039-16X (D2-07, D2-08) | EVF-G1, EVF-G4, EVF-G7, EVF-G8, G-W6 (EVF-G4b), G-W13 (option C), G-EVF-1, G-MP-EVF, G-EVF-3 (r7) | `EVF`, `EYECUP`, `COTS['hmx039']`, `COTS['evf_board']`, `COTS['eyepiece']`, `CABLES` `oled_flex`, `usb_5v` | **EVF carrier freeze** |
| MP-ENC | Adafruit 5880 (D2-10) | G-ENC-1, G-MP-ENC | `ENCODER`, `KNOBS['knob_exp']`, `COTS['encoder']` | panel print |
| MP-ENC (QT lead line, r7; same record; called MP-QT in SPEC-C2 and the layout comments) | QT lead (D2-24 + D2-24B, splice W-QT), 18/24 lead (D2-25 + D2-27), Pi header housings | G-QT-1, G-HDR-1 | `CABLES` `qt` / `fps_lead` (length_range, od, junction_mm3), `PLUG['jst_sh_4']`, `ENCODER['qt_socket']`, `PI['header_rows_y']`, `HDR_HOUSING`, `HEADER_HOUSINGS`, `KEEPOUTS` `ko_qt_tail` / `ko_qt_plug` / `ko_lead_stow`, `MATE_POSES` qt_enc / fps_ph | first assembly (steps 4 and 8); no print |
| MP-SW | 18/24 rotary switch (D2-11) | G-HDMI (switch part), G-MP-SW | `SWITCH_1824`, `KNOBS['knob_fps']`, `COTS['switch_1824']`, `ko_fps_up` | panel print |
| MP-STICK | SanDisk SDCZ880 (D2-09) | G-W10, G-MP-STICK | `STICK`, `STICK_SLEEVE`, `STICK_GUIDE`, `SCOOP`, `COTS['usb_stick']` | tub, sleeve print |
| MP-FPC (r2 fixer) | Pi 5 22-to-15 camera FPC, 200 mm (D2-20) | G-MP-FPC | `CABLES['fpc']` (length 200), `KEEPOUTS` `ko_fpc_up`, `ko_fpc_run`, `ko_fpc_loop` (x -42.5..-29.7, y 2..19.5, z 36.6..56: the 9-layer S-fold), `ko_fpc_cam` | step 7; tub, hood print |
| MP-X1203 (cooler line, r2 fixer; same record) | Raspberry Pi Active Cooler SC1148 (D2-02) | G-MP-X1203 (cooler line) | `COTS['cooler']` (top z 36.3), `PI['cooler_top']`; hood and FPC clearances above it | tub, hood print |

## MP-PACK: 1S2P 18650 pack

| Field | Content |
|---|---|
| Exact variant | **Variant NOT chosen: procurement decision (user).** The order must meet: 1S2P, 2 x 18650 high-drain cells (Molicel P28A or Samsung 35E class, >= 10 A continuous each), BMS >= 10 A continuous, UVP 2.5-3.0 V, 18 AWG silicone lead 60 mm, XT30U male, pull ribbon. Record on receipt: builder/vendor, cell make and model as printed on the cells, BMS part number |
| Photos | all 6 faces with a scale; the BMS (both sides if visible); the lead exit; the XT30 face showing polarity marks; the cell wrap print |
| Measure | outer L x W x H including wrap, BMS and tape (CAD box 38.0 x 20.0 x 72.0); lead exit position (end and corner); lead length to the XT30 body (CAD 60); XT30 body L x W x H; mass (CAD 105 g); open-circuit voltage; polarity. r7 (BX-3): the pigtail wire OD (18 AWG silicone, design range 1.9-2.4: `PIGTAIL['od_range']`); the pack lead length and OD (design 60 mm, `CABLES['pack_lead']`; it is counted in the `ko_xt30` store); the XT30U female body length (recorded, not credited in the reach) |
| Drives | `COTS['pack']` box (-64.5..-26.5, -10..10, -108.8..-36.8); `CABLES` `pack_lead` length; `COTS['xt30_pair']` box; `KEEPOUTS['ko_xt30']`; the grip bay (`GRIP`) and `CAP`/`CAP_JOINT` |
| Gate and pass | **G-W1**: + on the marked contact; 3.5-3.9 V; BMS label >= 10 A. **G-MP-PACK** (new): measured envelope <= 38.0 x 20.0 x 72.0 in every axis; lead exits at the top end (toward z -36.8) and the XT30 pair lies flat on the pack top under the run button (`COTS['xt30_pair']`, r7 fix-up re-pose; the pigtail and pack-lead slack in `ko_xt30` above it) when the pack is home; the cap slides shut with the pack in a printed grip (or a grip-bay coupon) without pressing the pack. r7 (BX-3): with the pigtail folded above it (about 140 mm) plus the pack lead, the pack goes home and the cap shuts 10 times without pinching either lead, and no loop lies in the gaps beside the pack (look up the mouth before the cap). r7 fix-up (VERIFY-C3): the junction is re-posed flat on the pack top under the run button (`COTS['xt30_pair']` x -61..-35, z -36.4..-30.0, female end -X, fuse sleeve beside it on +Y); the computed `pigtail_store` exits row needs at least 7.2 mm (2 x OD + OD) beyond each end plus the rigid solder-cup / heat-shrink length: record that junction length (computed room 8.0 mm at each end, so the rigid length may be 0.8 mm at most at OD 2.4; longer: re-pose again, never bend at the cups); the 10-cycle fold is done with the run button fitted, and the pigtail leaves the XT30 female straight (no bend at the solder cups) |
| If it fails | a larger pack changes `COTS['pack']` and `GRIP`/`CAP`: grip and cap reprint. Never shave the pack wrap. r7: a rigid XT30 exit longer than 0.8 mm re-poses the junction (`PIGTAIL` store, `COTS['xt30_pair']`) and re-runs `lead_access` |

## MP-X1203: Geekworm X1203 UPS board and its kit

| Field | Content |
|---|---|
| Exact variant | Geekworm X1203 (record the board revision silk-screen and the date code); its M2.5 kit (4 F-F standoffs, 8 M2.5 x 5 screws) |
| Photos | both PCB faces square-on with a scale; the battery pads close-up; the pogo pins side-on (free length); the USB-C; the edge components on all 4 edges; the kit parts |
| Measure | **Active Cooler (r2 fixer):** height of the fitted cooler top above the Pi PCB top and its footprint (CAD box x -72.8..-9.5, y -25.55..16.95, top z 36.3 = 16.2 above the PCB top z 20.1: `COTS['cooler']`, `PI['cooler_top']`; it sets the z clearance to the FPC fold and the hood); PCB outline and thickness (CAD 85 x 56, 1.6: `PI['x1203_z']` 6.0..7.6); mounting holes against the Pi pattern (58 x 49); standoff length (CAD **10.9**: `X1203_KIT['standoff']`, `X1203_KIT['standoff_z']`); pogo pin free and compressed height; battery pad positions (x, y from the Pi hole nearest the USB-C) and pad size; tallest part on each face (underside vs the floor bosses `PI_BOSS` top z 6.0); the parts within 2 mm of each edge; USB-C position (unused); kit screw head dia x height (CAD 4.5 x 1.75; SPEC limit 5.0 x 2.0). r7 (BX-3): the pads-to-W string length on the board (d_board, `PIGTAIL['pad']`; W = the port edge, 31.5 mm from the button-end edge); a free solder-mask area of about 10 x 5 mm next to the pads for the RTV bead; the underside parts under the pigtail lane x -40.0..-35.0, y -5..23.7 (the taped leg; lane height 3.1); for underside pads, the joint + bead height (must stay <= 3.1) and whether the pads lie inside the run lane footprint x -34..-22, y 1.5..31 (then a new pigtail lane is needed: 2.4 + 1.6 stacked > the 3.5 gap) |
| Drives | `COTS['x1203']` (box, `features.pcb`, `features.pads`), `X1203_KIT`, `PI['x1203_z']`, `PI['pcb_z']` (and so every z above the Pi: cooler, FPC/HDMI keep-outs), `PI_BOSS`, the stack retention (r2: R1's `pi_keeper` fingers at the 4 former hook stations, 0.1 above the X1203 top), `KEEPOUTS` `ko_pig_wrap`/`ko_pig_under`/`ko_pig_in` |
| Gate and pass | **G-W2**: pads, reserved GPIO lines and the gauge address recorded; r7 (BX-3): d_board measured, the U formed on the real board edge with a wire offcut (WIRING G-W2), L_cut = 200 + d_board rounded up to 5 mm (`lead_access` `pigtail_range`). r7 fix-up (VERIFY-C3): **stop branch**: if d_board > 25 mm, do not cut (`lead_access` `pigtail_drop`: the WIRING s4 / G-W5 drop estimate passes 0.15 V above L_cut 225 mm; the xh-estimate pad gives L_cut 295, about 0.176 V); options: underside routing straight to the hole, moving W, or 16 AWG with a re-checked lane width; the 0.15 V limit is not relaxed. **G-PI-1**: no X1203 edge part inside the reach of the 4 keeper fingers (the former hook stations: USB edge y -20 / 12, port edge x -80 / -45); standoff 10.9 +-0.2; kit screw head <= 5.0 x 2.0 (ISO 7045 allows k 2.1: measure, FASTENER-POLICY F). **G-MP-X1203** (new): cooler top <= z 36.3 (16.2 above the Pi PCB top) with the FPC and HDMI keep-outs above it clear; PCB 1.6 +-0.1 (the keeper fingers sit 0.1 above the X1203 top face at z 7.6; a thicker board takes that clearance); every underside part clears the floor (z 2.5) by >= 0.3, misses the 4 boss pockets and, in plan, the lead keep-outs under the board (`ko_run_floor`, `ko_pig_under`, `ko_pig_in`, z 2.7..5.8); the pads reachable from the port edge so the pigtail stays in `ko_pig_wrap` |
| If it fails | standoff != 10.9 +-0.2: re-derive `PI['pcb_z']` and re-run every keep-out and sweep above the Pi before printing the tub. Pads elsewhere (r7): enter them in `PIGTAIL['pad']` and cut to the reported L_cut; re-route only if they are on the underside under the lane |

## MP-CAM: Raspberry Pi Global Shutter Camera stack and the lens line (r5 rewrite)

r5 (`R5-BRIEF.md`, J7-R float): the r4 record measured the mounting holes for 2 printed pins and a dia 36.5 ring
bore. Both belonged to a camera model that does not match the official GS drawing; the pins are deleted. The camera
now hangs on the lens and touches no printed part, so this record checks the real stack against `CAM` (every value
is from the drawing at 10.05 px/mm, an estimate or unconfirmed: `CAM['status']`) and, in its **lens line** (judge 3's
"MP-LENS"), the lens's fixed band that the collar clamps. The lens line is a second part of this record, like the
cooler line of MP-X1203, not an eleventh record.

| Field | Content |
|---|---|
| Exact variant | Raspberry Pi Global Shutter Camera (SC0926 class); record the PCB revision silk-screen. Lens line: Kowa LM6HC (default) and/or Fujinon HF6XA-5M, serial and marking as on the barrel |
| Photos | camera side view square-on with a scale (as `research/m12-drawings/gs_side.png`); the tripod block and its 2 screws before and after B0; the lock tab and its screw from both sides; front (adapter, BFAR) and rear (cover, 15-pin connector). Lens line: side view with a scale, both thumb screws, the knurl marked |
| Measure (camera; `CAM['status']` value in brackets) | direct C-flange-to-cover-rear distance at s = 0 and at the set s (record both in CAM.optics; component dimensions alone cannot reveal a hidden flange offset); adapter OD (CAD 30.75) and face to face (5.00 +-0.05) [drawing]; BFAR head OD and thickness (CAD 36.0 x 1.2) and the exposed BFAR face annulus outside the adapter (>= 0.8 radial for the lip catch) [drawing]; BFAR thread OD (CAD about 28.8) [drawing]; r6 (audit X4): the BFAR's full travel, s at both of its stops, and the set s for infinity, which must lie in `CAM['s_range']` 0..3.0 [unconfirmed]; if it does not, update `s_range` (the keeper follows s_max) and rebuild; housing OD and depth (CAD 35.5 x 10.35) [drawing]; throat dia and depth (CAD 25.5 x 3.0) [unconfirmed]; lock tab width, top radius, depth and slot (CAD 10.16, r 22.1, 5.02, 0.8) and which side the lock-screw head is on and its size (CAD envelope dia 4.0 x 2.0 on both sides) [drawing; head side unconfirmed]; PCB (CAD 38 sq x 1.4) and cover (CAD 39.5 sq x 6.49) size and centring on the axis (+-0.2) [drawing]; 4 hole positions (30 square, dia 2.5) [drawing]; FPC socket position on the cover [estimate]; r7 (BX-1 class rule): how far the mated FPC stiffener stands proud of the cover rear, <= 3 mm (`ko_fpc_stiff`, estimate: it rides with the camera as a carried plug box in `camera_in` / `camera_out`); the tripod block (CAD 13.97 wide, 12.04 deep, 2 screws): it comes off and leaves nothing below r 18 [drawing; removability unconfirmed]; **s** = BFAR screw-out at Kowa infinity (bench step B0; CAD nominal 1.25) [unconfirmed geometric sample (B0)]; independently sourced sensor height above PCB and filter focus shift, if available (leave None if not, never back-fit assumed values); the total travel (CAD 0..3.0) [unconfirmed] |
| Measure (lens line, G-LENS) | mark the knurl, then turn focus and iris end to end: the knurl must not rotate; a dial indicator on its rear face reads <= 0.02 axial. Knurl OD (+-0.02; Kowa CAD 42.0), its rear-face position from the C flange (+-0.05; CAD +2.2, front +7.6) and its edge chamfer (CAD 0.3); the thumb-screw envelope (CAD focus at +14.4, iris at +33.0, r <= 24, width 3.8); the CoM (knife edge; Kowa CAD x 28.9 in the assembly frame, 28.3 ahead of the C flange); the rear protrusion (CAD C - 6.7) clears the camera filter at the recorded s. Fujinon: band dia 39 at +2.0..+7.8, all `'assumed'`. Any zoom: a fixed band of at least 15 mm |
| Drives | `CAM` (every key; `CAM['status']`), `cots.gs_camera_parts`, `COTS['gs_camera']`, `COTS['c_cs_adapter']`, `CAM['keeper']`, `HOOD['tab_catch']` (r7; `roll_fin` deleted), the tub lip and counterbore (`CAM['lip_d']`, `CAM['cb_d']`), `KEEPOUTS['ko_fpc_cam']`. Lens line: `LENSES[...]['support']` (and its `status`), `LENSES[...]['segments']`, `thumb_screws`, `layout.collar_spec`, `COLLAR`, `KEEPOUTS['ko_lens_thumb_*']` |
| Gate and pass | **G-CAM-1** (before the CAD is frozen): every camera value inside the `CAM` value, or `CAM` updated and rebuilt (then `j7_float` must pass again: body >= 0.5 lateral / 0.4 axial, BFAR >= 0.6 / 0.4, adapter >= 0.6). r7 (BX-4): also record the lock-screw head side, head dia and height, the tip protrusion on the other side, and the tab width and top radius. Set `HOOD['tab_catch']` head_side / bare_y (and `CAM['tab']`), rebuild; `roll_catch` and `j7_float` must pass again before the hood is printed. **G-LENS** (before tub/hood/panel/collar printing): the knurl does not move (<= 0.02) and the band values are inside `LENSES` (or updated and rebuilt); write the measured x0/x1, OD, edge chamfer, ring/thumbnail envelopes and CoM into LENSES, set its band status to 'measured', and rebuild. Rerun j7_float at both travel endpoints and the set s, lens_support, inserts, lens_clamp and the insertion/service sweeps on both selected lens variants. Regenerate affected tub, hood, panel and collar outputs before print; a changed band position is not a collar-only change. Then **G-COL-1** (coupons) and, on the assembled camera, **G-CAM-2** (SPEC s10). r7 (BX-4) G-CAM-2 adds: lens off, panel off, roll the camera by hand both ways: the tab meets a tine at about 3 deg and the cover touches nothing. Lens on and seated, s_c4 loose: turn lens and camera gently both ways: a soft stop each way at about 3 deg means the tab is free between the tines (r7 fix-up: a feeler cannot reach the tines under the hood roof); leave it mid-way, then snug s_c4. Record the roll at the catch under fingertip torque: it must stay below the PCB/cover first-contact angle minus `ROLL_CATCH` margin_deg (the roll_catch tine row does not model the roof compliance at the tine root). After 5 swaps: no whitening at the tine roots, both paint marks unmoved |
| If it fails | camera values or direct stack off: update CAM and its datum chain, then rebuild (do not fudge an unknown sensor height to close the chain) (the tub lip / counterbore, hood tab catch (r7) and panel keeper follow `CAM`); the tripod block will not come off cleanly: stop (it collides with the Pi envelope as D2 places the camera). Lens band moves (G-LENS fail): no collar for that lens; a collar on the locked focus ring (refocus by unpinching) or Plan B (SPEC s10: housing clamp) |

## MP-HDMI: micro-HDMI 90 deg lead

| Field | Content |
|---|---|
| Exact variant | **Variant NOT chosen: procurement decision (user).** The order must meet: micro-HDMI D to micro-HDMI D, 200 mm (+10/-0), thin shielded coax OD <= 3.0; Pi end 90 deg plug with the cable leaving upward; board end right-angle with the cable leaving -Y (EVF-SELECTION A3). Record the vendor listing and the plug moulding marks |
| Photos | each plug from 3 sides with a scale; the cable minimum bend held by hand |
| Measure | Pi-end plug height above the board when mated (CAD <= **8.5**, Q2); Pi-end plug body width and depth; cable OD; total length; board-end plug body L x W x H and its mated position on the Rev I board (the slot gap y 4..17); r7 (BX-1): the board-end plug's **mating stroke** (shell and tongue length above the overmold; design value 6.0, estimate: `PLUGS` `p_hdmi_evf` `stroke`) and the overmold width. The room for the pushing fingertip (`acc_hdmi_evf_push`) is 52 - stroke - 36.0 (10.0 at the design value; fingertip needs >= 9.0, `FINGERTIP_MM`, estimate) |
| Drives | `CABLES` `hdmi` length; `KEEPOUTS` `ko_hdmi_pi` (x -36.6..-27, y 24..32, z 17..41), `ko_hdmi_run` (z 39.6..44), `ko_hdmi_coil`, `ko_hdmi_evf`; `EVF['board_slot']['bottom_rail_gaps']` |
| Gate and pass | **G-HDMI**: Pi-end plug <= 8.5 off the board and inside `ko_hdmi_pi`; OD <= 3.0 along `ko_hdmi_run`; r7 (BX-1): the board-end plug overmold fits `ko_hdmi_evf` (x -144.8..-136.8, y 4..17, z 52..63.8) and its -Y boot stays below z 61 for y < 4; the plug is mated in situ, after the EVF pair is home (step 6; physical gate G-EVF-3, MP-EVF). **G-W7** (HDMI pin 19) before it meets the Pi |
| If it fails | taller plug: raise or widen `ko_hdmi_pi` and re-run the hood/panel sweeps; thicker cable: `ko_hdmi_run`. r7: a longer stroke leaves less than 9.0 over the stick-guide top: push straight up from the open well instead (`acc_hdmi_evf_push_well`, 43 mm of room; fingertip or tool 10 upright as a push stick; the guide-top push row then reads `push_stick`); a wider or taller board-end overmold: update `ko_hdmi_evf` and the `p_hdmi_evf` head and re-run `mate_paths` and the sweeps |

## MP-RUN: run button and its cap

| Field | Content |
|---|---|
| Exact variant | **Variant NOT chosen: procurement decision (user).** Candidate named in the BOM: The Pi Hut Squid Button (the colour and listing are the user's order). The order must meet: pre-wired momentary push button, non-latching, red cap, female-socket leads, cap removable from its stem. Record the listing and the switch body markings |
| Photos | the button with the cap on and off; the stem; the lead and its sockets |
| Measure | cap OD (hole 13.6: `RUN_BTN['wall_hole_d']`) and height; body L x W x H (CAD 8.5 x 12.0 x 13.0: `RUN_BTN['body']`); stem section; travel; lead length (CAD 250); r7 (BX-16): lead core OD (design 1.6, `CABLES['run_lead']['od']`) |
| Drives | `RUN_BTN` (body, cap, wall_hole_d, pad), `COTS['run_button']`, `CABLES` `run_lead` and its keep-outs |
| Gate and pass | **G-RUN-1**: the cap comes off its stem by hand and presses back on through the dia 13.6 hole, 5 cycles, with no damage to stem or cap and the switch still clicking; cap OD <= 13.2 (0.2 radial clearance); body inside the `RUN_BTN['body']` box |
| If it fails | a bonded cap: a different button class, or the cradle must take the button from the outside (grip revision). CAD cannot show that a cap detaches |

## MP-EVF: EVF-A bench assembly (panel release, board revision, optics, rail)

This is the most consequential record: the panel comes out of a kit prism, the board revision is unknown until
receipt, and the eyepiece is a separate part. **Build it on the bench, outside the camera, before the EVF carrier is
frozen.** The bench jig is a print of the tub rear segment (collar, OLED cell, board slot) plus the panel cap, or the
EVF coupons of PRINT-GUIDE s6 if they carry those features.

**Bench order** (each step only after the previous one passed; record results under `measured/MP-EVF/`):
1. EVF-G1 identity: photograph the kit as received (board both faces, flex marking, prism holder).
2. EVF-G7 panel release, then EVF-G8 flex measurement. Bonded panel: stop here (EVF-B or a bare-panel source).
3. EVF-G4 power range: board alone on a bench supply at 4.25 / 4.55 / 4.90 V.
4. G-W7 HDMI pin 19 isolation, then EVF-G2 timing on the Pi with the section 8 settings (stable 1024 x 768 at 60 Hz).
5. Bench jig: panel in the printed OLED cell with the foam pad, board in the printed slot against its stop with the
   real micro-HDMI plug and 5 V lead, eyepiece in the printed collar under the cap clamp. r7: as in step 6, slide the
   OLED and board in first (pad stuck to the OLED), then plug the HDMI from below through the rail gap.
6. G-MP-EVF focus, centring and restraint on the jig; G-EVF-1 pull-out and diopter.
7. G-W6 (EVF-G4b) rail on the real lead, on the X1203 bench feed of G-W4 (source max 5.355 V by default; r2 fixer:
   no longer "after G-W12", which needs the closed body and so the full print set). Expect the diode feed to fail
   the upper bound (WIRING s9). r3: the fail action **replaces** the diode by the 4.55 V LDO feed of WIRING s4.8
   (requirement R-EVF-REG, option C: r4 +5 parts, about +15 joints with the TLV75801P candidate, +3 / +11 with the fixed XC6220B45; recommended as the primary feed, user decision);
   then G-W13 (regulator on the bench), G-W6 on the regulated lead and a G-W7 re-run, all before the freeze.
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

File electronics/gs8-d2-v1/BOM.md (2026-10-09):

# GS8 D2 release v1: bill of materials (`electronics/gs8-d2-v1`)

Generated by `make_bom.py` from `cad/gs8-d2-v1/layout.py` and `outputs/bom-release-2026-09-25/prices.json`. **Do not edit by hand**: change `LINES` in the script (or the layout, or prices.json) and re-run `python electronics/gs8-d2-v1/make_bom.py`.

**Status:** planning only. Nothing was bought, no cart was used, no supplier was contacted. Currency **SGD**, including a 9 % GST allowance; shipping excluded. Lines priced from prices.json carry its id, date and confidence (see its legend; USD list prices x 1.2799 x 1.09). Every other figure is marked **estimate**: a USD planning figure written in the script, not looked up and not a quote. "unpriced" lines have no figure.

**Done on this machine vs not done (r3).** Done: this generated list, the CAD and its computed checks, the planning calculations (WIRING s4). Not done: procurement, printing or slicing, measurement, soldering, power-up and every bench gate (WIRING s9, MEASURED-PARTS). Candidate lines (quantity 0) are not adopted.

## Totals (SGD)

| Scope | From prices.json | Estimates | Lines unpriced |
|---|---|---|---|
| Camera build (sections A-C, E) | 775.74 | 323.93 | 1 |
| Tools and accessories (F) | 81.00 | 85.10 | 8 |

The lens (D2-06) is unpriced on purpose: the user reviews the lens choice later. Kowa LM6HC and Fujinon HF6XA-5M are both C-mount; `layout.LENS` selects the CAD proxy.

## Build counts (r2)

Read from `layout.py` at generation time (solder joints from `SOLDER_JOINTS` in this script). Optional reductions are quantified in `cad/gs8-d2-v1/OPTIONS.md`; the full toolset is ASSEMBLY s1.1. The authoritative count block for the whole release is `cad/gs8-d2-v1/DESIGN.md` s1.1 (`counts`, generated by make_tables.py).

| Count | Value |
|---|---|
| Printed parts | 12 (tub, hood, panel, base_grip, cap, plunger, knob_exp, knob_fps, eyecup, stick_sleeve, pi_keeper, lens_collar) |
| PT 3.0 x 12 PH1 screws used | 7 (s_b1, s_b2, s_r1, s_r2, s_k1, s_k2, s_j) |
| Harnesses (`layout.CABLES`) | 10 |
| Keep-outs (`layout.KEEPOUTS`) | 39 |
| Solder joints | 12 (pigtail to X1203 pads 2, pigtail fuse splice (r4, W-10) 2, EVF 5 V lead (diode splice + PH plug) 3, encoder A0 blob 1, 18/24 switch lugs 2, EVF board pigtail (Rev I) 2); +2 if the pack lacks an XT30 |
| X1203 kit fasteners (with D2-03; not PT body screws) | 8 x M2.5 screws + 4 standoffs (`layout.X1203_KIT`) |
| Candidate: regulated EVF feed (option C, WIRING s4.8; user decision) | a 4.55 V LDO on a carrier with 2 MLCC replaces the 1N5817: net +3 parts, +15 solder joints; gates G-W13, G-W6 (regulated run), G-W7 re-run. The r2 "5 V regulator module" contingency is withdrawn (a 5.0 V output breaks the 4.90 V maximum) |

## A. Electronics, optics, power

| Line | Item | Qty | SKU or class | Supplier | Layout id | Unit (SGD) | Line (SGD) | Price basis | Note |
|---|---|---|---|---|---|---|---|---|---|
| D2-01 | Raspberry Pi 5, 8 GB (4 GB is enough; the 8 GB line is the priced one) | 1 ea | SC1432 (8 GB, prices.json); layout pn SC1111/SC1112 | Cytron SG | `pi5` | 279.18 | 279.18 | prices.json CMP-01 (2026-09-21, carried_quote, included) |  |
| D2-02 | Raspberry Pi Active Cooler | 1 ea | SC1148 | MakerSupplies SG | `cooler` | 15.00 | 15.00 | prices.json CMP-02 (2026-09-21, carried_quote, included) | fan lead plugs into the Pi FAN header |
| D2-03 | Geekworm X1203 UPS board (pogo pins, 1S input, 5.1 V 5 A) with its M2.5 standoff kit | 1 ea | X1203 | Geekworm | `x1203` | 41.85 | 41.85 | estimate: USD 30.0 planning figure, not a quote | kit: 4 standoffs + 8 M2.5 screws (layout X1203_KIT; not PT body screws); bench gate G-W2 |
| D2-04 | microSD card, A2 class, 32-64 GB (OS only, front slot) | 1 ea | A2 class | any | `microsd` | 13.95 | 13.95 | estimate: USD 10.0 planning figure, not a quote | boot medium; out of the Pi for steps 3-4, pushed home at step 5 |
| D2-05 | Raspberry Pi Global Shutter Camera (IMX296) with its C-CS adapter | 1 ea | SC0926 | Cytron SG | `gs_camera` | 83.21 | 83.21 | prices.json CMP-04 (2026-09-25, estimate, as_displayed) | the 5 mm C-CS adapter ships with it (c_cs_adapter); r5: so do the tripod block and its 2 screws, removed at bench B0 and bagged (not in the body) |
| D2-06 | C-mount lens: Kowa LM6HC 6 mm f/1.8 1 in (default, 215 g) | 1 ea | LM6HC | Kowa distributor | `lens` |  |  | unpriced | LENS decision pending (user review); alternative D2-06b |
| D2-06b | Alternative lens: Fujinon HF6XA-5M 6 mm (100 g); order instead of D2-06 | 0 ea | HF6XA-5M | Fujifilm distributor |  |  |  | unpriced | balance: CoM moves about 10 mm rearward (concept table) |
| D2-07 | EVF-A display kit: Hicenda HMX039 0.39 in 1024x768 micro-OLED + HDMI board (option "Display+HDMI Board+Prism") | 1 kit | Hicenda Tindie kit | Hicenda (Tindie) | `hmx039` | 194.62 | 194.62 | prices.json EVF-01 (2026-09-25, seen_on_page, usd_list) | covers hmx039, evf_board and oled_flex |
| D2-08 | EVF-A eyepiece: Display Components 0PE039-16X glass eyepiece | 1 ea | 0PE039-16X | Display Components (Tindie) | `eyepiece` | 110.21 | 110.21 | prices.json EVF-02 (2026-09-25, seen_on_page, usd_list) |  |
| D2-09 | SanDisk Extreme PRO USB 3.2 solid state flash drive, 256 GB | 1 ea | SDCZ880-256G | any | `usb_stick` | 55.80 | 55.80 | estimate: USD 40.0 planning figure, not a quote | gate G-W10 (100 MB/s sustained, warm) |
| D2-10 | Adafruit 5880 I2C STEMMA QT rotary encoder (encoder pre-soldered) | 1 ea | Adafruit 5880 | Adafruit / DigiKey | `encoder` | 11.16 | 11.16 | estimate: USD 8.0 planning figure, not a quote | bridge A0 -> 0x37 |
| D2-11 | 18/24 selector: mini rotary switch with adjustable stop, 6.35 mm shaft, nut + washer | 1 ea | Lorlin CK1049 class | any | `switch_1824` | 8.37 | 8.37 | estimate: USD 6.0 planning figure, not a quote | set the stop to 2 positions; dims are estimates (G-HDMI note) |
| D2-12 | Run button: pre-wired momentary, red cap, female-socket leads | 1 ea | Squid Button (non-latching) class | The Pi Hut | `run_button` | 5.58 | 5.58 | estimate: USD 4.0 planning figure, not a quote | lead about 250 mm |
| D2-13 | 1S2P 18650 pack: 2 high-drain cells (>= 10 A class), BMS >= 10 A, 18 AWG lead, XT30U male, pull ribbon | 1 ea | 1S2P custom (Molicel P28A / Samsung 35E class) | pack builder | `pack` | 41.85 | 41.85 | estimate: USD 30.0 planning figure, not a quote | gate G-W1; the order states R-PACK-BMS (WIRING s4.7) in numbers; +2 joints if the XT30 is not fitted |
| D2-14 | XT30U connector pair (female for the pigtail; male if the pack lacks one) | 2 pair | Amass XT30U | any | `xt30_pair` | 1.40 | 2.79 | estimate: USD 1.0 planning figure, not a quote | 1 spare pair |
| D2-14F | Inline fuse 15 A, very fast, axial PICO II, 32 V (pigtail + conductor near the XT30 female; W-10, r4) | 2 ea | Littelfuse 0251015.MXL (DigiKey F2352-ND) | DigiKey |  | 2.02 | 4.05 | estimate: USD 1.45 planning figure, not a quote | 1 spare; USD 1.45 is the DigiKey listing seen 2026-10-05 (8,035 in stock), not a quote; gates G-W1, G-W5 |
| D2-15 | Hand strap, 12 mm webbing with buckle | 1 ea | class | any | `strap` | 11.16 | 11.16 | estimate: USD 8.0 planning figure, not a quote | through the 2 base and 2 heel slots |
| D2-16 | Schottky diode 1N5817 (EVF 5 V lead, W-3; baseline feed) | 2 ea | MCC 1N5817-TP | DigiKey SG |  | 0.44 | 0.87 | prices.json PRT-05 (2026-09-25, seen_on_page, excluded) | 1 spare; deleted under option C (WIRING s4.8) |
| D2-16R | Candidate (option C, WIRING s4.8; qty 0 until the user adopts it or G-W6 fails): LDO, adjustable 500 mA, set to 4.553 V by D2-16D (R-EVF-REG band 4.459-4.638 V from datasheet limits) | 0 ea | TI TLV75801PDBVJ (SOT-23-5) or TLV75801PDRVR (WSON-6, reflow) | DigiKey |  | 0.46 | 0.00 | estimate: USD 0.33 planning figure, not a quote | replaces D2-16; order 2 (1 spare); r4 desk research, listing USD 0.33 seen 2026-10-05; fixed alternative Torex XC6220B45BPR-G (0 stock, long lead); NOT XC6210 and NOT a generic 5 V regulator; gate G-W13 |
| D2-16D | Candidate (option C): divider resistors for D2-16R, R1 11.5 kohm + R2 1.58 kohm, 0.1 %, 0603 | 0 ea | thin film 0.1 % class | any |  | 0.42 | 0.00 | estimate: USD 0.3 planning figure, not a quote | order 4 (1 set spare); not needed with the fixed XC6220B45 |
| D2-16C | Candidate (option C): MLCC CIN 2.2-4.7 uF + COUT 4.7 uF, X7R, 16 V, 0805 (TLV75801P; the XC6220 would need 10 uF + 10 uF, 1206 25 V) | 0 ea | class | any |  | 0.14 | 0.00 | estimate: USD 0.1 planning figure, not a quote | order 4 (2 spare) |
| D2-16P | Candidate (option C): small SOT-89 carrier PCB with copper (est. 16 x 7.5 x 4.5 sleeved envelope inside ko_5v_up by box arithmetic; carrier not measured) | 0 ea | SOT-23-5 / WSON-6 carrier with copper pour (custom; no 4.5 V module found) | any |  | 1.40 | 0.00 | estimate: USD 1.0 planning figure, not a quote | order 2 (1 spare); copper-rich (row 7: SOT-23-5 is 177 C/W on the TI board); thin-wall sleeve, no adhesive heat-shrink over the LDO |

## B. Cables and leads

| Line | Item | Qty | SKU or class | Supplier | Layout id | Unit (SGD) | Line (SGD) | Price basis | Note |
|---|---|---|---|---|---|---|---|---|---|
| D2-20 | Pi 5 camera cable Standard-Mini 22-to-15 pin, 200 mm | 1 ea | official 200 mm | MakerSupplies SG | `fpc` | 5.50 | 5.50 | prices.json HAR-07 (2026-09-25, seen_on_page, as_displayed) | priced from the 300 mm SC1129 listing (same family); order 200 mm |
| D2-21 | micro-HDMI D-D 200 mm (+10/-0), OD 3.0, Pi end 90 deg up, board end right-angle (-Y exit) | 1 ea | EVF-SELECTION A3 class | any | `hdmi` | 16.74 | 16.74 | estimate: USD 12.0 planning figure, not a quote (prices.json HAR-08 has no price) | gates G-HDMI (plug <= 8.5 mm), G-W7 |
| D2-22 | USB-A male to 2-wire lead, 24-26 AWG, about 200 mm | 1 ea | class | any | `usb_5v` | 4.19 | 4.19 | estimate: USD 3.0 planning figure, not a quote | + D2-16 diode + D2-23 junction |
| D2-23 | JST PH 2-pin wire-to-wire pigtail pair, pre-crimped 24-26 AWG | 2 pair | PHR-2 class | any |  | 1.40 | 2.79 | estimate: USD 1.0 planning figure, not a quote (prices.json HAR-04 has no price) | EVF 5 V junction (W-4); 1 spare |
| D2-24 | QT lead part 1: Adafruit 4397 STEMMA QT to female sockets, 150 mm (cut so the socket end is about 93-117 mm, WIRING W-QT) | 1 ea | Adafruit 4397 | Adafruit / DigiKey | `qt` | 1.40 | 1.40 | estimate: USD 1.0 planning figure, not a quote | socket end on pins 1/3/5/6 (step 4); a one-piece 240-270 mm lead of the same ends may replace D2-24 + D2-24B (buy-check MP-QT) |
| D2-24B | QT lead part 2: Pololu #5521 JST SH-style 4-pin cable, single-ended female, 30 cm, 28 AWG (SH end kept; cut so the finished lead is 250 +/- 10 mm) | 1 ea | Pololu 5521 | Pololu | `qt` | 2.85 | 2.85 | estimate: USD 2.04 planning figure, not a quote | splice W-QT; or the one-piece class lead (SPEC-C2 s8); USD 2.04 is the listing seen 2026-10-08, not a quote; stock not confirmed; fallback Pololu #5522 (75 cm) |
| D2-25 | 2-way Dupont female to JST PH 2-pin lead, 200 mm (header side of the 18/24 lead) | 1 ea | class | any | `fps_lead` | 2.09 | 2.09 | estimate: USD 1.5 planning figure, not a quote | concept tally 200 mm; plugged on pins 33/34 at step 4; spare and PH junction fold into ko_lead_stow at step 8 (cable_stow) |
| D2-27 | JST PH 2-pin wire-to-wire pigtail pair, 50 mm (18/24 inline junction, switch side soldered) | 1 pair | PHR-2 class | any |  | 1.40 | 1.40 | estimate: USD 1.0 planning figure, not a quote (prices.json HAR-04 has no price) | the step-8 joint of the 18/24 lead (FIXER A-F1) |
| D2-26 | Silicone wire 18 AWG, red + black, 1 m each | 1 set | class | any | `pigtail` | 5.58 | 5.58 | estimate: USD 4.0 planning figure, not a quote (prices.json HAR-W18 has no price) | r7 C3 (BX-3): pigtail cut length 200-225 mm per colour (L_cut = 200 + d_board, G-W2; d_board over 25 mm: stop, G-W5 drop) + spare |

## C. Fasteners

| Line | Item | Qty | SKU or class | Supplier | Layout id | Unit (SGD) | Line (SGD) | Price basis | Note |
|---|---|---|---|---|---|---|---|---|---|
| D2-30 | PT 3.0 x 12 thread-forming screw for plastics, pan head, PH1 (EJOT PT K30x12 WN 1411 / Delta PT 30x12 class) | 11 ea | WN 1411 class | any | `pt_screws` | 0.21 | 2.30 | estimate: USD 0.15 planning figure, not a quote | 7 used (s_b1, s_b2, s_r1, s_r2, s_k1, s_k2, s_j) + 4 spare; count from layout.SCREWS (FASTENER-POLICY A) |
| D2-31 | 1/4-20 UNC hex nut, steel (tripod socket) | 1 ea | ISO 4032 class | any | `tripod_nut` | 0.42 | 0.42 | estimate: USD 0.3 planning figure, not a quote | pressed into the base pocket |
| D2-32 | Insert fallback: M3 x 5.7 brass heat-set insert (pack) | 1 pack | CNC Kitchen M3 standard | Printed Solid (US) |  | 15.35 | 15.35 | prices.json INS-M3 (2026-09-25, seen_on_page, usd_list) | only for a stripped boss (FASTENER-POLICY E) |
| D2-33 | Insert fallback: M3 x 10 pan head A2, ISO 7045 cross recess PH1 (no hex: straight-driver rule) | 7 ea | ISO 7045 class | any |  | 0.14 | 0.98 | estimate: USD 0.1 planning figure, not a quote | with D2-32 only; 1 per PT boss |
| D2-35 | M3 heat-set insert, brass, short (L 4.0, OD 4.6 class), lens-collar anchors in the tub bosses | 5 ea | heat-set insert class (procure; G-COL-1) | any | `m3_hw` | 0.28 | 1.40 | estimate: USD 0.2 planning figure, not a quote | 3 used (tub TL / TR / LL, set at the bench before step 3) + 2 spare |
| D2-36 | M3 heat-set insert, brass, L 5.7 (OD 4.6 class), lens-collar pinch lug | 1 ea | CNC Kitchen M3 standard class | any |  | 0.28 | 0.28 | estimate: USD 0.2 planning figure, not a quote | 1 used (s_c4, pressed into the lower lug from below); spare: the D2-32 pack |
| D2-37 | M3 x 10 pan head A2, ISO 7045 cross recess PH1 (lens-collar anchors) | 4 ea | ISO 7045 class | any |  | 0.14 | 0.56 | estimate: USD 0.1 planning figure, not a quote | 3 used (s_c1..s_c3, 0.15 N m provisional cap) + 1 spare; separate from the D2-33 fallback screws |
| D2-38 | M3 x 16 pan head A2, ISO 7045 cross recess PH1 (lens-collar pinch) | 2 ea | ISO 7045 class | any |  | 0.14 | 0.28 | estimate: USD 0.1 planning figure, not a quote | 1 used (s_c4, 0.2 N m, the last operation on the lens) + 1 spare |
| D2-39 | M3 washer, ISO 7089 A2 (3.2 x 7.0 x 0.5) | 6 ea | ISO 7089 class | any |  | 0.07 | 0.42 | estimate: USD 0.05 planning figure, not a quote | 4 used (one under each lens-collar screw: s_c1, s_c2, s_c3, s_c4) + 2 spare |
| D2-34 | Contingency: M2.5 x 5 pan head A2, ISO 7045 cross recess PH1 | 0 ea | ISO 7045 class | any |  | 0.14 | 0.00 | estimate: USD 0.1 planning figure, not a quote | order 8 only if the X1203 kit screws are hex-socket (FASTENER-POLICY F, G-W2) |

Not separately bought: the X1203 kit (4 M2.5 F-F standoffs, 8 M2.5 x 5 screws, with D2-03; counted apart from the 7 PT body screws), the 18/24 switch nut and washer (with D2-11), the C-CS adapter (with D2-05) and the OLED flex (with D2-07).

## D. Printed parts (12 parts, manifest (out/print-manifest.json))

| # | Part | Material, colour | Face down | Volume (cm3) | Mass at 100 % (g) | Mass as printed (g) | Filament [est] (g) | Basis |
|---|---|---|---|---|---|---|---|---|
| P-01 | `tub` | ASA, satin silver | -Y | 106.1 | 113.5 | 96.5 | 101.3 | manifest (out/print-manifest.json) |
| P-02 | `hood` | ASA, black | +Z | 57.6 | 61.6 | 52.4 | 55.0 | manifest (out/print-manifest.json) |
| P-03 | `panel` | ASA, satin silver | +Y | 51.2 | 54.8 | 46.5 | 48.9 | manifest (out/print-manifest.json) |
| P-04 | `base_grip` | ASA, black | +Z | 91.0 | 97.4 | 58.4 | 61.4 | manifest (out/print-manifest.json) |
| P-05 | `cap` | ASA, black | -Z | 6.7 | 7.2 | 7.2 | 7.6 | manifest (out/print-manifest.json) |
| P-06 | `plunger` | ASA, black | +X | 0.3 | 0.3 | 0.3 | 0.3 | manifest (out/print-manifest.json) |
| P-07 | `knob_exp` | ASA, black | +Y | 4.8 | 5.1 | 5.1 | 5.4 | manifest (out/print-manifest.json) |
| P-08 | `knob_fps` | ASA, black | +Y | 1.3 | 1.3 | 1.3 | 1.4 | manifest (out/print-manifest.json) |
| P-09 | `eyecup` | TPU 95A, black | +X | 4.4 | 5.3 | 5.3 | 5.6 | manifest (out/print-manifest.json) |
| P-10 | `stick_sleeve` | ASA, satin silver | -X | 1.1 | 1.2 | 1.2 | 1.2 | manifest (out/print-manifest.json) |
| P-11 | `pi_keeper` | ASA, black | +Z | 6.2 | 6.6 | 6.6 | 7.0 | manifest (out/print-manifest.json) |
| P-12 | `lens_collar` | ASA (PC if G-W11 shows > 50 C at the camera), black | +X | 16.1 | 17.3 | 17.3 | 18.1 | manifest (out/print-manifest.json) |

Filament by material and colour (estimate, before purges and failed prints): ASA, black 156.2 g; ASA, satin silver 151.4 g; TPU 95A, black 5.6 g.

"Mass as printed" = volume x density x the layout infill factor (shell 0.85, base_grip 0.6, small 1.0, tpu 1.0, thin 1.0). Replace the layout estimates by re-running this script after `build_d2.py` has written its print manifest.

## E. Consumables

| Line | Item | Qty | SKU or class | Supplier | Layout id | Unit (SGD) | Line (SGD) | Price basis | Note |
|---|---|---|---|---|---|---|---|---|---|
| D2-40 | ASA filament 1.75 mm, 1 kg, satin silver (tub, panel, sleeve) | 1 spool | Polymaker ASA class | MakerSupplies SG |  | 35.90 | 35.90 | prices.json CON-01 (2026-09-21, carried_quote, included) | price of the black spool line |
| D2-41 | ASA filament 1.75 mm, 1 kg, black (hood, base + grip, cap, knobs, pi_keeper, plunger) | 1 spool | Polymaker ASA class | MakerSupplies SG |  | 35.90 | 35.90 | prices.json CON-01 (2026-09-21, carried_quote, included) |  |
| D2-43 | TPU 95A filament, black (eyecup) | 1 spool | class | any |  | 34.88 | 34.88 | estimate: USD 25.0 planning figure, not a quote (prices.json CON-02 has no price) | about 5 g needed |
| D2-44 | Paint pen / enamel for the engraving fill: black (silver panel, concept tally) + white (plunger symbol) | 2 ea | class | any |  | 5.58 | 11.16 | estimate: USD 4.0 planning figure, not a quote (prices.json CON-10 has no price) | confirm the panel fill colour with the concept |
| D2-45 | Closed-cell foam sheet 1.0 mm, pressure-sensitive adhesive one side (OLED pad 16 x 14; stuck to the OLED back) | 1 sheet | class | any | `foam_pad` | 4.19 | 4.19 | estimate: USD 3.0 planning figure, not a quote (prices.json CON-20 has no price) | r7 C1 (BX-7): the pad rides with the EVF pair |
| D2-46 | Adhesive-lined heat-shrink 3:1 (pigtail, diode splice, r4 fuse splice: about 4.8 mm, 30 mm per fuse) + thin-wall 2:1 (switch lugs) | 1 set | class | any |  | 5.58 | 5.58 | estimate: USD 4.0 planning figure, not a quote (prices.json HAR-HSA has no price) | r7 QT splice (W-QT): 4 thin-wall sleeves about 1.5 mm x 10 mm + 1 adhesive 3:1 about 4.8 mm x 35 mm |
| D2-46R | Neutral-cure silicone RTV, small tube (pigtail strain relief at the X1203 battery pads) | 1 tube | class | any |  | 8.37 | 8.37 | estimate: USD 6.0 planning figure, not a quote | r7 C3 (BX-3): neutral cure, not acetoxy; USD 6 is an estimate, not a quote |
| D2-47 | Solder, flux, wick | 1 set | class | any |  | 8.37 | 8.37 | estimate: USD 6.0 planning figure, not a quote (prices.json CON-15 has no price) |  |
| D2-48 | Pull ribbon 10 mm (if the pack has none) + Kapton tape | 1 set | class | any |  | 2.79 | 2.79 | estimate: USD 2.0 planning figure, not a quote (prices.json CON-16 has no price) | r7 C3 (BX-11, BX-16): + Kapton for the pigtail leg and the run-lead lane |
| D2-49 | Isopropyl alcohol + glue stick (bed release) | 1 set | class | any |  | 5.58 | 5.58 | estimate: USD 4.0 planning figure, not a quote (prices.json CON-11 has no price) |  |
| D2-50 | Small cable ties 2.5 mm (lead bundles) | 1 pack | class | any |  | 2.79 | 2.79 | estimate: USD 2.0 planning figure, not a quote | step 1 |
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

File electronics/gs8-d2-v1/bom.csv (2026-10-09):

section | line | item | qty | unit | sku_or_class | supplier | layout_id | unit_sgd | line_sgd | price_basis | prices_json_id | note
A. Electronics, optics, power | D2-01 | Raspberry Pi 5, 8 GB (4 GB is enough; the 8 GB line is the priced one) | 1 | ea | SC1432 (8 GB, prices.json); layout pn SC1111/SC1112 | Cytron SG | pi5 | 279.18 | 279.18 | prices.json CMP-01 (2026-09-21, carried_quote, included) | CMP-01
A. Electronics, optics, power | D2-02 | Raspberry Pi Active Cooler | 1 | ea | SC1148 | MakerSupplies SG | cooler | 15.00 | 15.00 | prices.json CMP-02 (2026-09-21, carried_quote, included) | CMP-02 | fan lead plugs into the Pi FAN header
A. Electronics, optics, power | D2-03 | Geekworm X1203 UPS board (pogo pins, 1S input, 5.1 V 5 A) with its M2.5 standoff kit | 1 | ea | X1203 | Geekworm | x1203 | 41.85 | 41.85 | estimate: USD 30.0 planning figure, not a quote |  | kit: 4 standoffs + 8 M2.5 screws (layout X1203_KIT; not PT body screws); bench gate G-W2
A. Electronics, optics, power | D2-04 | microSD card, A2 class, 32-64 GB (OS only, front slot) | 1 | ea | A2 class | any | microsd | 13.95 | 13.95 | estimate: USD 10.0 planning figure, not a quote |  | boot medium; out of the Pi for steps 3-4, pushed home at step 5
A. Electronics, optics, power | D2-05 | Raspberry Pi Global Shutter Camera (IMX296) with its C-CS adapter | 1 | ea | SC0926 | Cytron SG | gs_camera | 83.21 | 83.21 | prices.json CMP-04 (2026-09-25, estimate, as_displayed) | CMP-04 | the 5 mm C-CS adapter ships with it (c_cs_adapter); r5: so do the tripod block and its 2 screws, removed at bench B0 and bagged (not in the body)
A. Electronics, optics, power | D2-06 | C-mount lens: Kowa LM6HC 6 mm f/1.8 1 in (default, 215 g) | 1 | ea | LM6HC | Kowa distributor | lens |  |  | unpriced |  | LENS decision pending (user review); alternative D2-06b
A. Electronics, optics, power | D2-06b | Alternative lens: Fujinon HF6XA-5M 6 mm (100 g); order instead of D2-06 | 0 | ea | HF6XA-5M | Fujifilm distributor |  |  |  | unpriced |  | balance: CoM moves about 10 mm rearward (concept table)
A. Electronics, optics, power | D2-07 | EVF-A display kit: Hicenda HMX039 0.39 in 1024x768 micro-OLED + HDMI board (option "Display+HDMI Board+Prism") | 1 | kit | Hicenda Tindie kit | Hicenda (Tindie) | hmx039 | 194.62 | 194.62 | prices.json EVF-01 (2026-09-25, seen_on_page, usd_list) | EVF-01 | covers hmx039, evf_board and oled_flex
A. Electronics, optics, power | D2-08 | EVF-A eyepiece: Display Components 0PE039-16X glass eyepiece | 1 | ea | 0PE039-16X | Display Components (Tindie) | eyepiece | 110.21 | 110.21 | prices.json EVF-02 (2026-09-25, seen_on_page, usd_list) | EVF-02
A. Electronics, optics, power | D2-09 | SanDisk Extreme PRO USB 3.2 solid state flash drive, 256 GB | 1 | ea | SDCZ880-256G | any | usb_stick | 55.80 | 55.80 | estimate: USD 40.0 planning figure, not a quote |  | gate G-W10 (100 MB/s sustained, warm)
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

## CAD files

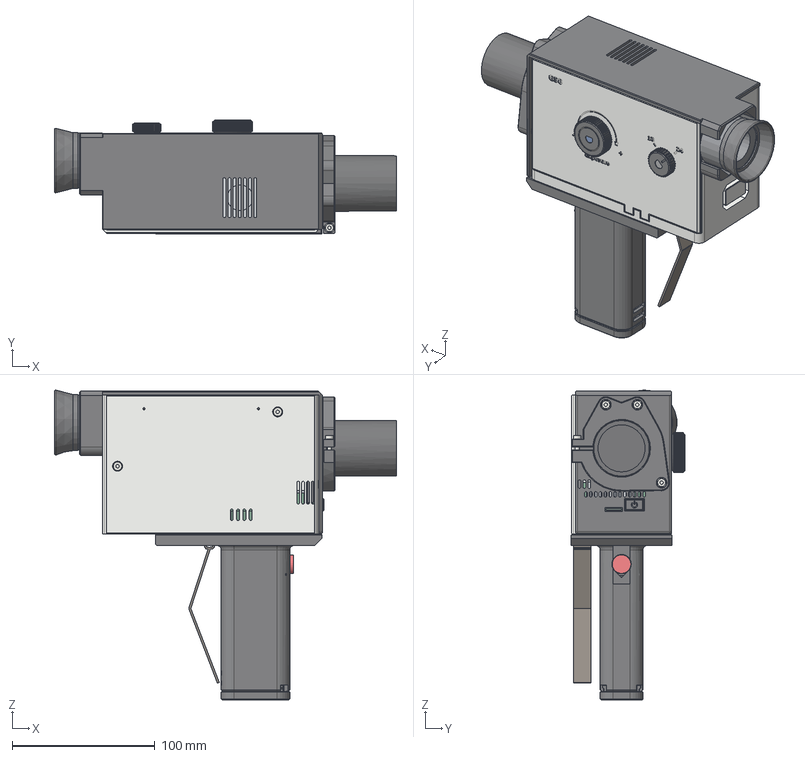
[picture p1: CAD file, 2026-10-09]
cad/gs8-d2-v1/out/_fujinon-cloud-polish-20261007/step/gs8-d2-assembly.step
239.2 x 79.4 x 216.8 mm
pi5
cooler
x1203
x1203_kit
gs_camera
c_cs_adapter
lens
eyepiece
hmx039
evf_board
usb_stick
encoder
switch_1824
run_button
pack
xt30_pair
tripod_nut
strap
microsd
foam_pad
s_b1
s_b2
s_r1
s_r2
s_k1
s_k2
s_j
s_c1
s_c2
s_c3
s_c4
tub
hood
panel
base_grip
cap
plunger
knob_exp
knob_fps
eyecup
stick_sleeve
pi_keeper
lens_collar

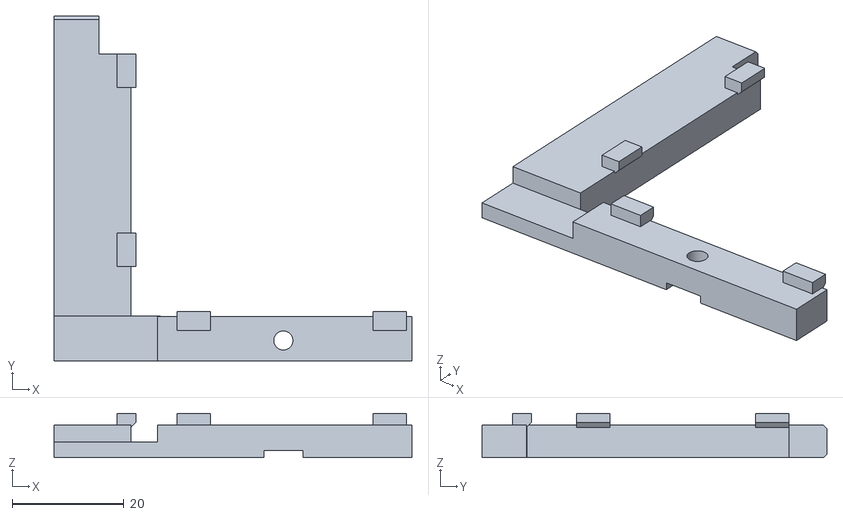
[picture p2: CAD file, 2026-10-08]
audit/d2-readiness-2026-10-05-r3/rebuild-fr1/stl/pi_keeper.stl
64.0 x 61.7 x 7.90

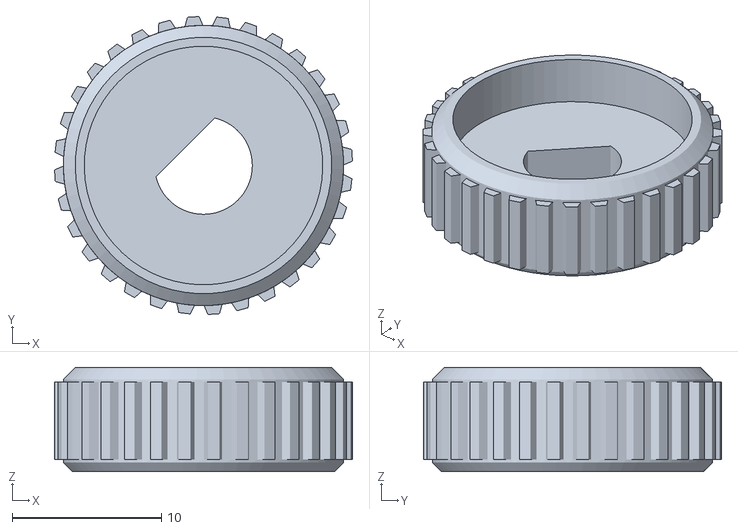
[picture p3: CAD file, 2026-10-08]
audit/d2-readiness-2026-10-05/rebuild-kowa/stl/knob_fps.stl
20.0 x 20.0 x 7.00

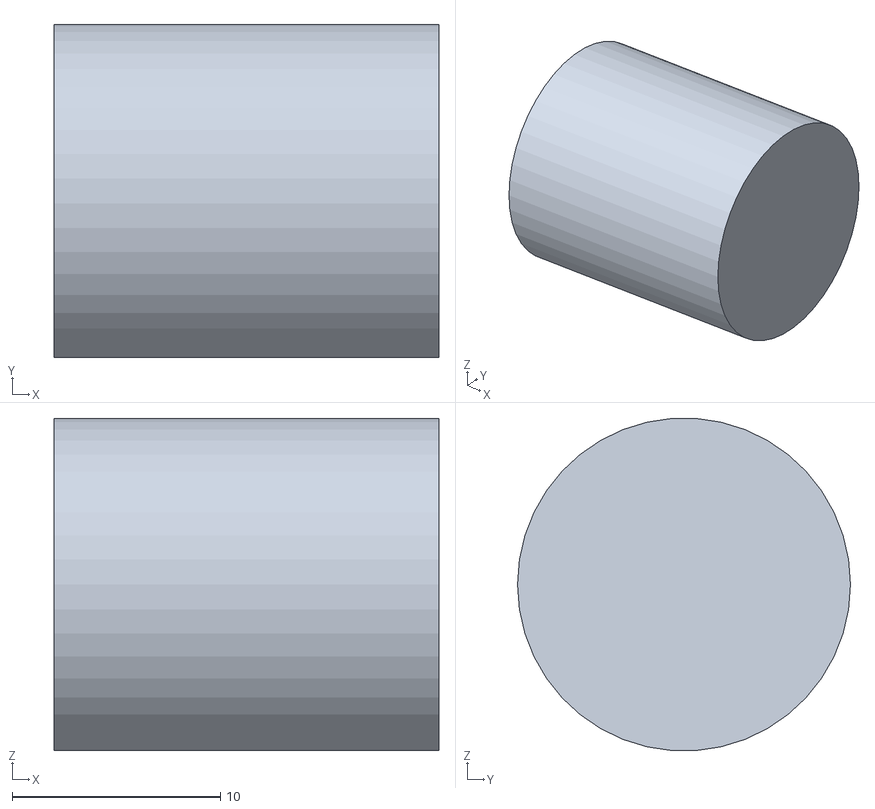
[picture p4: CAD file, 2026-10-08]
audit/d2-readiness-2026-10-06/rebuild-kowa/stl/modifiers/tub__mod_s_c3.stl
18.5 x 16.0 x 16.0

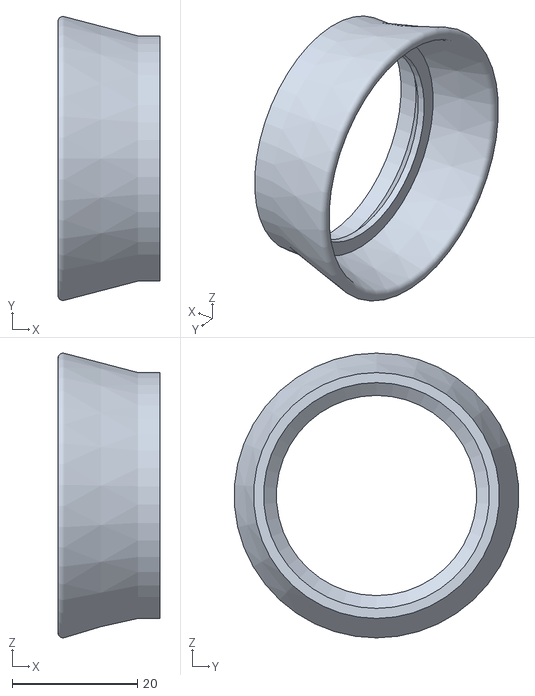
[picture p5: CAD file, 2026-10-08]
cad/gs8-d2-v1/airflow/out/meshes/eyecup.stl
16.3 x 45.4 x 45.5

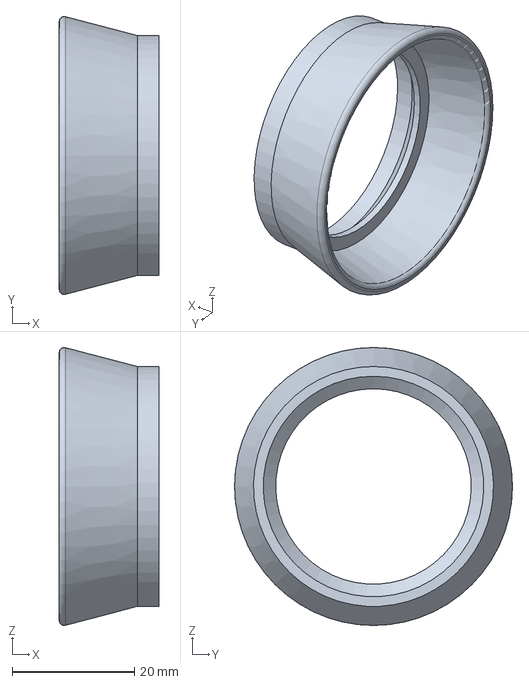
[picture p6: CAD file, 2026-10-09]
cad/gs8-d2-v1/out/_fujinon-cloud-polish-20261007/step/parts/eyecup.step
16.3 x 45.5 x 45.5 mm

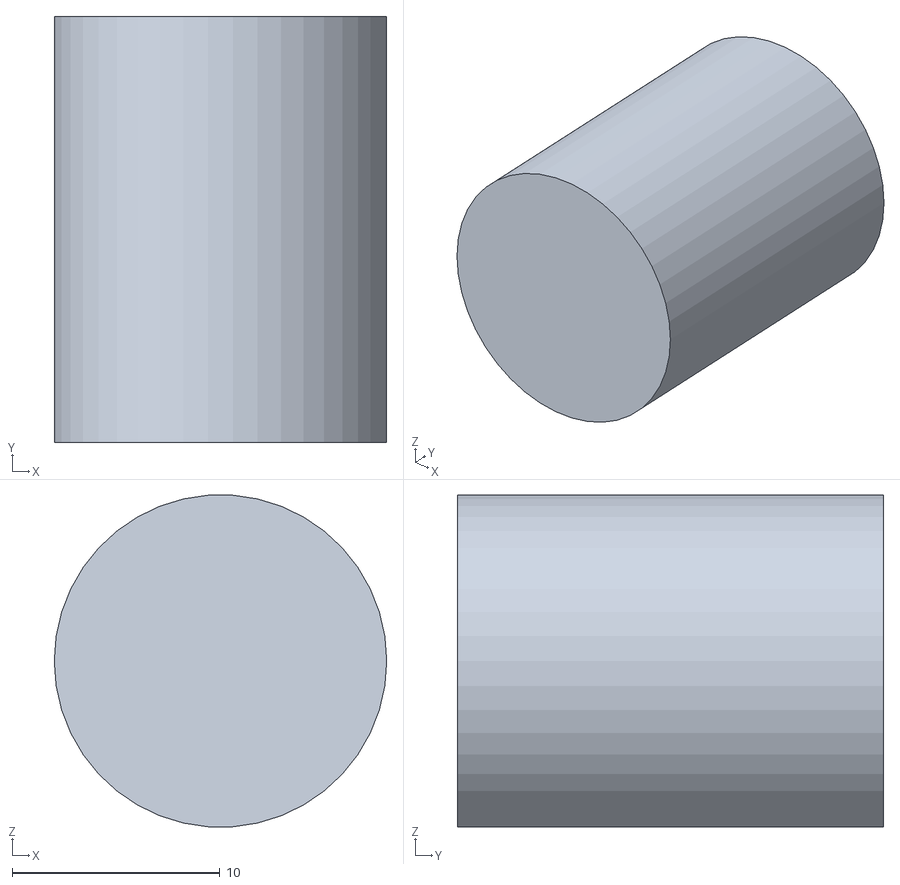
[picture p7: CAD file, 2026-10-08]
cad/gs8-d2-v1/out/_fujinon-cloud-polish-20261007/stl/modifiers/tub__mod_s_k2.stl
16.0 x 20.5 x 16.0

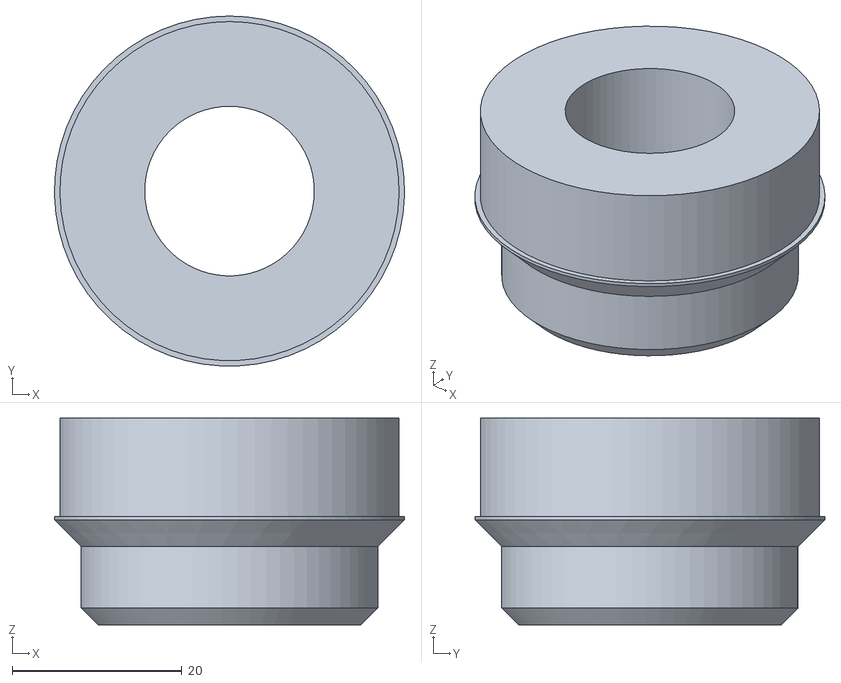
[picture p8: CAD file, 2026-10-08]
cad/gs8-d2-v1/out/_fujinon-cloud-polish-20261007/stl/tools/collar_gauge.stl
41.3 x 41.3 x 24.4

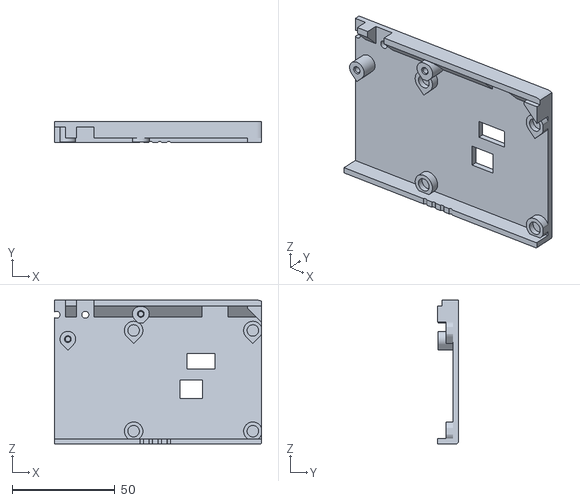
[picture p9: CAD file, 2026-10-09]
cad/gs8-d2-v1/out/stl/coupons/coupon-pi-keeper-tub.stl
100.7 x 10.0 x 70.0

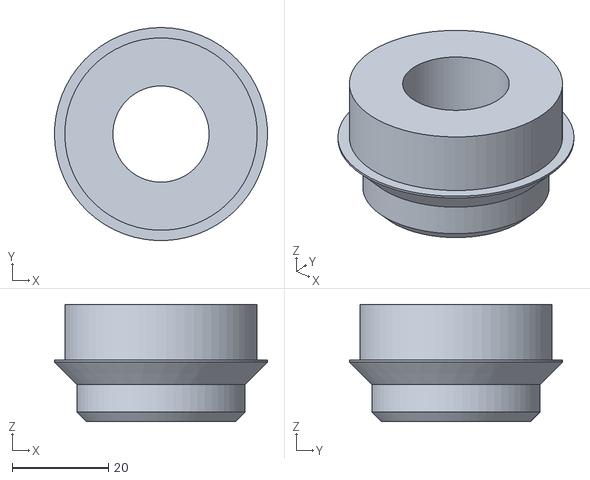
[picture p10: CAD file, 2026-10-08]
cad/gs8-d2-v1/out/stl/tools/collar_gauge.stl
44.3 x 44.3 x 24.4

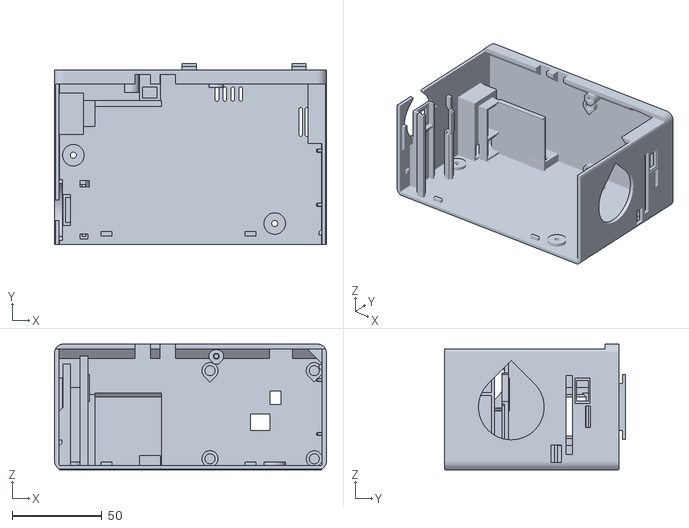
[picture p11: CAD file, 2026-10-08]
audit/d2-readiness-2026-10-05-r3/rebuild-fr1/stl/tub.stl
151.3 x 100.9 x 70.0

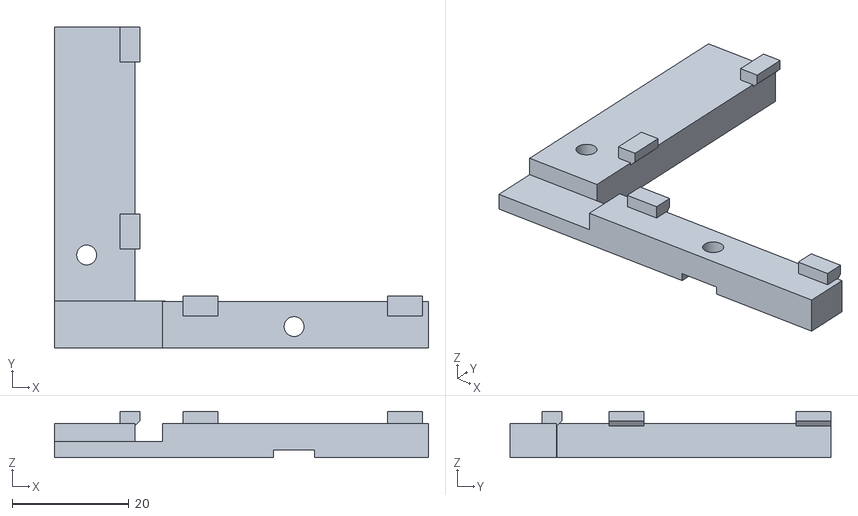
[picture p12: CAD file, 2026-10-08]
audit/d2-readiness-2026-10-06/rebuild-kowa/stl/pi_keeper.stl
64.0 x 54.9 x 7.90

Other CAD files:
cad/gs8-d2-v1/out/step/gs8-d2-assembly.step
cad/gs8-d2-v1/out/step/parts/knob_fps.step
cad/gs8-d2-v1/out/stl/modifiers/base_grip__mod_s_b2.stl
audit/d2-readiness-2026-10-05/rebuild-kowa/stl/eyecup.stl
audit/d2-readiness-2026-10-06/rebuild-kowa/stl/modifiers/tub__mod_s_k1.stl
audit/d2-readiness-2026-10-05-r3/rebuild-fr1/stl/base_grip.stl
audit/d2-readiness-2026-10-05-r3/rebuild-fr1/stl/cap.stl
audit/d2-readiness-2026-10-05-r3/rebuild-fr1/stl/eyecup.stl
audit/d2-readiness-2026-10-05-r3/rebuild-fr1/stl/hood.stl
audit/d2-readiness-2026-10-05-r3/rebuild-fr1/stl/knob_exp.stl
audit/d2-readiness-2026-10-05-r3/rebuild-fr1/stl/panel.stl
audit/d2-readiness-2026-10-05-r3/rebuild-fr1/stl/plunger.stl
audit/d2-readiness-2026-10-05-r3/rebuild-fr1/stl/stick_sleeve.stl
audit/d2-readiness-2026-10-05/rebuild-kowa/stl/base_grip.stl
audit/d2-readiness-2026-10-05/rebuild-kowa/stl/cap.stl
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

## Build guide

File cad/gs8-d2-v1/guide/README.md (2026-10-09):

# GS8 D2 assembly guide (`cad/gs8-d2-v1/guide`)

An IKEA-style assembly guide for the D2 fork. It has pictures, written instructions on every page, and the wiring steps.
It was built on 2026-10-08 from the r6 CAD (layout.py, 5bb2384). Nobody has assembled a D2 yet: the guide is a DRAFT
of the computed build sequence.

## What is in it

`out/GS8-D2-assembly-guide.pdf`, `out/index.html` and `out/pages/d2-NNN.png` (A4 landscape, 150 dpi):
- **Front pages.** Cover; 0.1 rules; 0.2 the 14 tools; 0.3 hardware bags; 0.4/0.5 parts inventory with pictures;
  0.6 gates before assembly; W wiring overview (every cable route and step); 0.7 contents.
- **Bench pages.** B0 camera and lens; B1 heat-set inserts.
- **Step 1 wiring.** 1a fuse splice, 1b pigtail to the X1203, 1c EVF 5 V lead with diode, 1d EVF board pigtail,
  1e 18/24 switch pigtail, 1f encoder address, then 1g the bench stack.
- **Steps 2-10.** These follow `layout.STEPS`, split into sub-steps a/b/c. The header leads (4d) and the EVF mating
  (6b) each have their own diagram page.
- **Last pages.** S service isolation (P1-P4), and ! the physical blocker check (`BLOCKERS-2026-10-08.md`).

Every rendered step shows at least three points of view:
- **A:** the motion, with arrows.
- **B:** the same motion seen across it.
- **C:** a close-up of the result.

New parts are highlighted. Installed parts are grey. A new part hidden behind an installed one has a dashed outline.
Open design issues from the blocker check appear in a red box on the page of the step concerned (`guide_steps.ISSUES`).

## Files

| File | Role |
|---|---|
| `guide_steps.py` | All page text: rules, tools, bags, gates, steps, open issues. It paraphrases ASSEMBLY.md (r6) and WIRING.md s5-s7; where they differ, those documents win |
| `build_guide.py` | Page composer: multi-view renders, right-hand text column, front pages, PDF, HTML |
| `lineart.py` | Line-art renderer: VTK offscreen ID, depth and normal passes plus image-space edges |
| `diagrams.py` | Wiring diagrams (PIL, schematic) |
| `BLOCKERS-2026-10-08.md` | Physical blocker review of the build sequence |
| `_cache/meshes.npz` | Part meshes in assembly pose (git-ignored; `--remesh` rebuilds them from build_d2) |

## Rebuild

Run from the repo root (about 3 minutes; add `--remesh` after any CAD change, about 2 more minutes):

    .venv-cad/Scripts/python.exe cad/gs8-d2-v1/run_locked.py -- cad/gs8-d2-v1/guide/build_guide.py

`--only 4a,7b` renders single pages to `out/pages/only-<id>.png` for checking. The guide reads layout.py and the
meshes and writes only under `guide/out/` and `guide/_cache/`. It changes no CAD source and no receipt input.

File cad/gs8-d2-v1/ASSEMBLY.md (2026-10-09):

# GS8 D2 release v1: assembly (`cad/gs8-d2-v1`)

DRAFT, 2026-10-04 (docs owner); r3 2026-10-05: every internal service starts with the pack physically
disconnected (s7 prerequisite P1-P4), and the pack is connected last in the build (step 10); **r5 2026-10-06: the
heavy-lens support (J7-R float)**: bench steps B0 (camera) and B1 (inserts) come first, the camera, adapter and lens
collar go in at step 7, the lens through the collar at step 8, and the lens never goes into an unsupported camera. The build order of D2: the 10 steps of `layout.STEPS`, in that order and with the
same numbers. Steps 1 and 2 are bench sub-assemblies; their parts join the body at steps 4 and 8. Each step lists the
parts added, the fasteners, the tool, the motion (from `layout.INSERTIONS`), and the cables made there. The step and
screw tables are generated by `make_tables.py` from `layout.py`; the harness detail (pins, colours, solder joints) is
in `electronics/gs8-d2-v1/WIRING.md`. Nothing has been assembled: these steps are checked only by the computed
insertion sweeps and the straight-driver audit of `build_d2.py`, never by hardware.

Frame: X forward (lens side), Y to the operator's left (panel side), Z up; x 0 is the front-plate face, z 0 the tub
floor underside. "Travels +Z" means the screw moves upward (driven from below).

## 1. Tools and rules

| Item | Requirement |
|---|---|
| Driver | **One PH1 screwdriver, straight**, shank dia 6.5 or less, blade 40 mm or longer, handle dia 28-30 (`layout.DRIVER`). It is the only tool for the **enclosure closure** (the PT screws) and (r5) for the 4 lens-collar M3 screws; the whole build needs the toolset of s1.1. No L-keys, hex keys, angled or ball-end drivers (user rule). The X1203 kit M2.5 screws take the same PH1 if they are cross-recess; if the kit ships hex screws, use M2.5 x 5 ISO 7045 PH1 instead (FASTENER-POLICY F) |
| PT torque | **0.35-0.5 N m, stop at head contact** (FASTENER-POLICY C, provisional until G-PT-1). r6 (audit B-6): set it on the torque screwdriver (tool 13, BOM D2-77); a firm hand on a plain PH1 already gives 0.4-0.6 N m. No threadlocker on ASA. Do not re-torque later |
| M3 torque (r5) | lens collar: s_c1, s_c2, s_c3 **0.15 N m provisional maximum**, the pinch s_c4 **0.2 N m**, stop at head contact (FASTENER-POLICY I). r6 (audit B-6, X5): **always with the torque screwdriver** (tool 13, BOM D2-77). By hand these become 2-3 times the value and can pull a short insert or crush the washer seat. Machine thread into brass heat-set inserts: no drive tally, no threadlocker |
| Lens rule (r5, r6) | **never thread the lens into an unsupported camera.** r6 (audit B-7): never react the thread torque through the cover or the PCB. Those are joined to the lens mount only by the compliant housing-to-PCB joint (2 M2 screws, nylon washers, gasket). r7 (BX-4): nobody holds the camera. Thread torque turns it about 3 deg until its metal lock tab meets the hood tab catch (two tines, one each side of the tab). The reaction goes housing -> tab -> hood, never through the cover or the PCB (computed: `roll_catch`). Panel off (step 8): one fingertip on the cover centre keeps the camera forward on its lip catch, push only. Panel on (lens swap): tip the body nose-down so the camera comes forward onto its lip catch. Turn the lens with fingertips only. **Check the adapter mark at every lens change** (B0, item 3). s_c4 is always the last operation on the lens |
| Re-assembly | 5 or fewer drives per boss; tally them on the build sheet. Then the M3 insert fallback (FASTENER-POLICY D-E) |
| Kit screws | X1203 kit M2.5: 0.2 N m, metal to PCB only, at the bench (step 1) |
| Switch nut | finger-tight + 1/8 turn (about 0.3 N m) on a 1/2 in socket; the anti-rotation tab carries the switching torque |
| Snaps | the hood (4 hooks) goes **straight down** until every hook clicks; never rock it in. The Pi stack has **no snap** (r2): it sets down on its 4 bosses and a printed keeper on 2 PT screws (s_k1, s_k2) holds it (step 4); r1's floor-hook strain below is the r1 record only. Strains are recorded once in `layout.snap_strains()`: hood hooks 0.87 % nominal (1.31 % with the root Kt), encoder cradle 1.12 % (1.68 %); r1 only: Pi floor hooks 2.61 % nominal, one-time class with no release access (G-SNAP-1, withdrawn with the hooks in r2) |
| Power last | **the pack is plugged in only at step 10, after the body is closed**: every internal lead of steps 1-9 is made with the pack out of the camera. Never mate or part any internal lead (EVF 5 V junction, HDMI, FPC, flex, QT, 18/24, header leads) with the pack connected. For service the same rule runs in reverse: section 7, prerequisite P1-P4 (shut down, cap off, pack out, XT30 parted) comes first on every route |
| ESD | grounded mat + wrist strap for steps 1, 4, 6 and 7 and bench step B0 (bare boards, OLED flex, camera) |
| Header leads | the QT (1/3/5/6), 18/24 (33/34) and run (37/39) leads go on the Pi header at **step 4**, while the top is open and the header is in sight. r7 (BX-10): single 1-pin housings (a 1x2 only on 33/34 or 37/39), each seated straight down with open tweezer tips straddling the wire (pressing both sides of the housing top) and tug-tested. Step 8 only makes the panel-side joints (QT JST-SH at the encoder, 18/24 JST PH junction); r7 (BX-2): with the panel propped 60 mm off on a block about 110 mm tall and a helper holding the body, PH junction first, on a 250 mm QT lead (WIRING W-QT) |
| microSD | out of the Pi from the bench flash (step 1) until step 5; pushed home through the front slot after the hood is on |
| Small tools | see s1.1 (the full toolset) |
| Gates before assembly | WIRING G-W1 to G-W7 (pack, X1203 identity, Pi on the bench PSU, the stack on the bench with a supply for the pack (G-W4) and under load (G-W5), the EVF feed before the EVF carrier is frozen (G-W6), HDMI pin 19 (G-W7)) and G-W13 on receipt of the regulator carrier if EVF-feed option C (WIRING s4.8) is adopted, SPEC G-CAM-1 and G-LENS (r5: MEASURED-PARTS MP-CAM with its lens line, before any lens collar is printed) and the collar coupons G-COL-1, the print coupons (PRINT-GUIDE s6) and the measured-part records of `MEASURED-PARTS.md` (MP-PACK, MP-X1203, MP-CAM, MP-HDMI and the MP-EVF bench assembly before the EVF carrier is frozen). Before any powered full-build claim: WIRING G-W12 (workload power). At the first assembly (r7): G-HDR-1 at step 4 and G-QT-1 at step 8 (MEASURED-PARTS MP-ENC, QT lead line) |

### 1.1 Full toolset (r2, audit finding 7)

"One PH1" is true of the enclosure closure only. Building the whole camera takes the 17 tools below (r6 added the torque
screwdriver and the collar centring gauge, audit 2026-10-06 B-6 and X2). r7 (blocker review 2026-10-08) adds tool 15
(pliers for the EVF HDMI unplug), tool 16 (2 paper strips: the knob stop shim) and the optional tool 17 (inspection
mirror), and tool 7 gains a caliper and a soft-jaw vise. Number 18 is kept for another r7 cluster, so the numbers stay
fixed (PLAN X-9). A folded cloth and a closed paperback (step 8), a block or book stack about 110 mm tall (the step-8
panel prop) and a helper's hands (step 8) are named in the step text, not as rows. The column
"Removed by" shows which optional simplification of `OPTIONS.md` would remove a tool: (a) 18/24 moved into the
encoder menu (declined by the user 2026-10-05: the 18/24 stays a switch, so tools 6 and 7 stay), (b) a 150 mm camera
FPC (open). Neither option is applied.

| # | Tool | Used for (step) | BOM | Removed by |
|---|---|---|---|---|
| 1 | PH1 screwdriver, straight, shank <= 6.5, blade >= 40 | enclosure PT screws (8, service); Pi keeper PT screws s_k1, s_k2 (4, service; R1); X1203 kit screws if cross-recess (1); r5: lens-collar M3 screws s_c1..s_c3 (7) and s_c4 (8, 10, lens swap) | D2-60 | - |
| 2 | Temperature-controlled soldering iron, with solder, flux and wick | 12 joints (incl. the encoder A0 blob and, r4, the 2 pigtail fuse-splice joints) (1); r5: with an M3 heat-set tip, the 4 lens-collar inserts (B1; BOM D2-74); +2 if the pack lacks an XT30; +15 joints, +5 parts under EVF-feed option C with the TLV75801P candidate (+11 / +3 with the fixed XC6220B45) (WIRING s4.8; not adopted) | D2-63, D2-47 | - (a) removes 2 of the joints, not the iron |
| 3 | Wire stripper + flush cutter | lead ends, heat-shrink and cable-tie tails (1, 4) | D2-68 | - |
| 4 | Heat gun | adhesive heat-shrink (1) | D2-68 | - |
| 5 | Multimeter | polarity and no-short checks before any power (1, 10); gates | D2-64 | - |
| 6 | 12.7 mm (1/2 in) socket or spanner | 18/24 switch nut, finger-tight + 1/8 turn (2) | D2-61 | **(a)** |
| 7 | Junior hacksaw + small flat file + caliper with depth rod + a vise with soft jaws (2 wood offcuts) (r7, BX-14) | measure the switch shaft in place (P), then cut it off the panel and deburr (2) | D2-69 | **(a)** |
| 8 | Fine tweezers, 120 mm | run-lead sockets up through the base passage and the floor hole before the tub goes down (3, r7); r7: header housings seated with open tips straddling the wire (4); microSD (5); OLED, flex and EVF leads (6); r7: PH junction tuck into `ko_5v_end` (6), PH junction lift (s7 item 7) | D2-62 | - ((b) keeps them: the loop is still laid by hand) |
| 9 | 2 hood release pins: dia 1.5 steel, 16 mm+ (ISO 8734 dowel class, or the shanks of 2 x 1.5 mm drills) (r2 fixer: replaces the 3 mm release blade) | hood removal: one pin per right-wall release hole holds hk1 / hk2 open (s7 item 9) | D2-71 | - |
| 10 | Flat bar (any steel rule) | press the tripod nut into its pocket (3); r7: held upright as a straight HDMI push stick up from the open well (6), only if a fingertip does not fit (no floor-edge lever: the tub top at z 36 is only the stick-guide block, y < 10.8) | - | - |
| 11 | Paint pen | engraving fill (2) | D2-44 | - |
| 12 | ESD mat + wrist strap | steps 1, 4, 6, 7; B0 | D2-70 | - |
| 13 | Adjustable torque screwdriver 0.1-0.6 N m, straight, PH1 bit (shank <= 6.5 over >= 40, handle dia <= 30: the driver audit envelope) (r6) | every M3 lens-collar screw (s_c1..s_c3 0.15, s_c4 0.2 N m) and every PT screw (0.35-0.5 N m) (3, 4, 7, 8, 10, service) | D2-77 | - |
| 14 | Collar centring gauge, printed, one per lens (`stl/tools/collar_gauge.stl`) (r6) | centre the collar on the tub lip while s_c1..s_c3 are tightened (7; every collar refit, s7 item 6c) | printed (PRINT-GUIDE s3) | - |
| 15 | Smooth-jaw long-nose pliers, jaws >= 35 long, tips <= 2.0 thick (r7, BX-1/C-16) | HDMI unplug at the EVF board: grip the plug body on its left and right faces at its deep half, pull straight down through the rail gap (s7 item 7); the pliers come up from the open well below the slot, inclined, so the shank stays below z 51 at y > 20 (clear of the slab-backing fingertip); optional at step 6 to carry the plug by its +Y half | - | - |
| 16 | Printer paper, 2 strips (about 0.2 mm together) (r7, BX-5) | knob stop shim: each knob is pressed on until it stops on the paper (2; knob change, s7 item 4a) | - | - |
| 17 | Inspection mirror, head <= 15 mm (optional) (r7, BX-1) | see that the EVF HDMI plug is fully home in the board (6) | - | - |

Not counted above:
- **Bench and gate equipment**: bench DC supply with current limit (>= 10 A), official 27 W PSU, inline USB-C power
  meter and an oscilloscope (G-W12), thermocouple, a DC electronic load >= 10 A, constant-current mode (G-W5 (b), G-W13;
  BOM D2-75), digital calipers (MEASURED-PARTS), 1S charger with an XT30 lead (out-of-body charging). Option C only:
  the G-W13 (c) stand-ins, a 100 uF capacitor and a load resistor (BOM D2-76).
- **Insert fallback only** (FASTENER-POLICY E): a hand drill or pin vise with 3.2 and 4.0 mm drills, then the same
  PH1 driver. (r5: the M3 heat-set tip for the iron is now used in every build, B1, so it moved to tool 2.)
- **Camera tripod block (r5, B0, once, off the body):** whatever driver the camera's own 2 block screws need (drive
  unconfirmed: MP-CAM). If it is a hex key, it is the one bench exception to the straight-driver toolset
  (FASTENER-POLICY F).
- **Consumables**: cable ties, heat-shrink, Kapton tape, IPA; r7 (BX-3): neutral-cure silicone RTV (not acetoxy, BOM D2-46R) for the pigtail strain relief at the X1203 pads.

## 2. Steps

**Bench steps before step 1 (r5, heavy-lens support; not in `layout.STEPS`, nothing joins the body):**

- **B0. Camera and lens on the bench (MP-CAM, G-CAM-1, G-LENS; ESD strap).**
  1. Measure and photograph the camera and lens as MP-CAM asks, before freezing or printing the tub, hood, panel or
     lens collar. Record the direct C-flange-to-cover-rear distance at s = 0 and at the final set s, as well as the
     component dimensions. A nominal 1.25 mm CAD pose is a geometry sample, not a measured infinity setting.
  2. Keep the tripod block fitted and secure it to a bench tripod/clamp; independently support the lens barrel in
     a padded V-block if needed. Never thread the heavy lens into an unsupported camera or hold it by the PCB/cover.
  3. r6 (audit B-2): seat the C-CS adapter firmly in the BFAR and draw one paint-pen line across adapter and BFAR.
     The adapter and the lens use the same 1"-32 thread, both hand-tight, so either joint can break loose first at a
     lens change. If the adapter ever comes out with the lens, the next C lens screws 5 mm deeper into the CS thread
     and its rear (C - 6.7) can reach the camera's filter. **At every lens change the mark must still line up.** If it
     does not, unscrew the adapter from the lens, take the camera out (s7 item 6b) and refit the adapter here before
     any lens goes in. Then fit the selected lens.
     r7 (BX-4): paint a second mark across BFAR and housing (the first is across adapter and BFAR). Check both marks
     at every lens change: the tab catch reacts the thread through the BFAR thread, like any hold on the housing would.
  4. For live view use the bench Pi/camera setup: connect the correct FPC to CAM1 only while power is off; use the
     official Pi supply and the already-verified preview route (an external monitor is sufficient). The pack and
     X1203 are not needed for this optical measurement. Shut down and remove bench power before moving the FPC.
  5. Set back focus with the selected lens at infinity (or a target more than 50 m away), lock the BFAR split-tab
     screw, and record s, lock-screw side and the direct C-flange-to-cover-rear distance. Do not infer sensor die
     height or filter shift from an illustrative CAD value. Record the lens thread length and verify rear-cell/filter
     clearance. r6 (audit X4): s must lie inside the CAD travel `CAM['s_range']` (0..3.0), the range the float
     check sweeps every 0.25 mm. The panel keeper sits 0.5 behind the cover at s 3.0, so **never screw the BFAR
     out past 3.0** in service (no macro by back focus). If infinity needs more, stop: record the BFAR's full
     travel at both stops for MP-CAM, then update `CAM` and rebuild. Remove the lens while the camera remains
     supported.
  6. Only now remove the tripod block and bag its two screws (drive unconfirmed until MP-CAM). Confirm that it comes
     off without disturbing the camera body and leaves nothing below r 18. Otherwise stop. Update CAM and the
     selected LENSES band/segment/CoM values, rebuild every affected part and rerun the full checks before printing.
     G-LENS and G-COL-1 precede the production print set; G-CAM-2 follows final assembly.
- **B1. Heat-set inserts (FASTENER-POLICY I; iron with an M3 heat-set tip for that iron's tip system, BOM D2-74).**
  Before step 3, with the tub empty: 3 short inserts (D2-35) into the 3 front-wall bosses TL, TR, LL from the front,
  square to the face, 0.1 below it. r6 (audit B-14): the bosses hang behind a 2.5 mm wall, so back each one with a
  block through the open left side, go slowly and check that the insert goes in square. A crooked insert is the
  usual failure in a small ASA boss. (The 3.4 clearance runs on through each boss end, so a screw at the long end of
  its length tolerance cannot bottom; audit B-3.) Any time before step 7: 1 insert L 5.7 (D2-36) into the lens collar's lower lug from below. Let them cool; check
  that an M3 screw turns in by hand. Record the actual insert maker/part, OD and length; update M3 and rerun the insert checks if they differ. Clear the collar STL's three sacrificial 0.2 mm membranes with a 3.4 mm hand tool; remove debris and verify flat washers without changing the seat, cone or foot datums.

<!-- BEGIN:steps -->
### Step 1. Bench: power stack (bench)

Make the pigtail to L_cut = 200 mm + the G-W2 pads-to-W length (round up to 5 mm; 200 mm if the pads are at W). If the pads-to-W length is more than 25 mm, stop: do not cut (computed `lead_access` pigtail_drop: the G-W5 drop estimate passes 0.15 V above L_cut 225 mm); route the pair under the board straight to the hole, move W, or change to 16 AWG with a re-checked lane width, and re-run the checks first. L_cut is the finished length from the pad joint to the XT30 rear, with the fuse splice included. Solder it to the X1203 battery pads (2 joints) and heat-shrink them. On the bare X1203, lead the pair on the top face to W (dry-fit the Pi on the standoffs to find the X1203 edge under its USB/Ethernet ports; pen-mark W on that edge 31.5 mm from the end whose mounting holes are 3.5 mm from the edge), coming straight in from inside the board, not along the edge. Put one strip of Kapton over the board edge at W, fold the pair round the edge, and tape the leg flat under the board with 2 strips of Kapton, straight in from W for about 32 mm, to above the pigtail hole. Keep the pair within 1 mm of the mark. The rest hangs free. (Pads on the underside: run the pair straight under the board to that point and tape it, with no U.) Strain relief: a neutral-cure silicone RTV bead over both joints and the first 8-10 mm of the pair, bonded to the board (not acetoxy; keep it off the pogo pads and connectors; keep it at least 1 mm inside the board edge and no more than 3.5 mm from W toward the USB end, where the keeper finger lands). Stack only when the bead is tack-free, and do not pull on the pigtail before the full cure the tube states. Solder the EVF 5 V lead (1N5817 in the + conductor + PH junction, 3 joints) and check it with a multimeter. Stack X1203 + Pi 5 with the kit (4 standoffs, 8 M2.5 screws, 0.2 N m), fit the Active Cooler. Bridge encoder A0 (1). Solder the 50 mm JST PH pigtail to the 18/24 switch (2). Flash the microSD (G-W3), then take it OUT of the Pi for steps 3-4.

| Item | Detail |
|---|---|
| Bench sub-assembly | `x1203` (Geekworm X1203 UPS (pogo pins, XH lead to any 1S pack)); `x1203_kit` (X1203 kit standoffs + screws); `pi5` (Raspberry Pi 5 (4/8 GB)); `cooler` (Raspberry Pi Active Cooler) |
| Parts added to the body | none (bench step) |
| Fasteners | none |
| Tool | soldering iron; multimeter; kit driver (PH1 or as supplied) |
| Harness (WIRING s7) | pigtail fuse (r4): splice the 15 A fuse (Littelfuse 0251015.MXL) into the red conductor about 20-25 mm from the XT30 female: trim each fuse lead to 6.5 mm (a 1.5 mm stub at the body + a 5 mm lap joint on the stripped conductor), adhesive 3:1 heat-shrink over the whole splice (about 28 mm) (**hand-solder at 350 C for 5 s max per lead (datasheet); never re-solder the XT30 female with the fuse fitted; meter the red path end to end (< 0.1 ohm)**); pigtail -> X1203 battery pads: cut to L_cut (`PIGTAIL`); solder red to +, black to -; adhesive heat-shrink over both joints; on the bare X1203 lead the pair to the W mark, Kapton over the edge, form the U and tape the leg flat under the X1203 to the hole point; then RTV strain relief at the pads (neutral cure) over the joints and 8-10 mm of the pair (before the Pi covers top-face pads); stack when tack-free, full cure before step 4 (**pack never connected at the bench; meter + to - for no short before anything else; r7 (BX-3): no tie to a standoff**); Active Cooler lead -> Pi FAN: plug the JST-SH 4 (**route it as the cooler ships**); encoder A0: 1 solder blob on the A0 jumper (**address 0x37**); QT lead splice (W-QT, r7): join Adafruit 4397 to Pololu 5521 by SH pin number: joints 91-115 mm from the socket tip, 8 mm apart, one thin sleeve each, one adhesive 3:1 sleeve about 35 mm over all; finished 250 +/- 10 mm (**map continuity first; never join by colour alone; meter end to end, no short**); 18/24 switch pigtail: solder the 50 mm JST PH 2-pin pigtail to the common and position-2 lugs; heat-shrink; microSD: flash it (gate G-W3), then take it out of the Pi (**the card must be out for steps 3-4 (it hits the front wall on the stack path)**); EVF 5 V lead: solder the 1N5817 into the + conductor (band toward the board), the PH plug on the free end; adhesive heat-shrink (**polarity: meter USB-A VBUS -> PH pin 1 through the diode (forward), GND -> pin 2**); EVF board pigtail (Rev I): solder the PH 2-pin pigtail to the traced EXT+ / GND pads; heat-shrink strain relief (**photograph both board sides first (EVF gate G1)**) |
| Cables | `fps_lead` 18/24 switch -> GPIO13 + GND (pins 33/34); `pigtail` X1203 battery pads -> XT30 junction in the grip; `fan` Active Cooler -> Pi 5 FAN header |

### Step 2. Bench: panel (bench)

Paint-fill the engraving. Switch shaft, off the panel: fit the 18/24 switch dry (tab in its slot, the washer as supplied, nut finger-tight). Measure how far the shaft stands above the panel face (P, caliper depth rod). Take the switch off. Clamp the end that will be cut off (at least about 8 mm in the soft vise jaws) and saw P - 6.9 mm off the shaft end beside the jaws on the switch side, the switch hanging free; if less than that comes off, file the shaft down instead. Never clamp the bushing thread; never saw with the switch on the panel. Deburr. Refit the switch (tab in its slot), nut finger-tight + 1/8 turn. Encoder: snap it into its cradle by pushing on the back of its board until all 3 hooks click. Knobs: lay the 2 paper strips on the panel face round the encoder shaft. Hold the panel in one hand with that thumb flat on the back of the encoder board. Press knob_exp onto its D shaft with the other palm until it stops on the paper. Your thumb takes the push, not the hooks. Move the 2 strips round the switch shaft and press knob_fps on until it stops on the paper, its D flat to the shaft flat (the switch nut takes the push). Pull the paper out. From now on the knobs ride with the panel: never press a knob while the panel is on the body.

| Item | Detail |
|---|---|
| Bench sub-assembly | `panel` (printed, ASA satin silver); `encoder` (Adafruit 5880 I2C QT rotary encoder (A0 bridged, 0x37)); `switch_1824` (mini 2-position rotary switch + nut + washer); `knob_exp` (printed, ASA black); `knob_fps` (printed, ASA black) |
| Parts added to the body | none (bench step) |
| Fasteners | none |
| Tool | paint pen; 12.7 mm (1/2 in) socket or spanner for the switch nut; junior hacksaw + file; caliper with depth rod; vise with soft jaws (2 wood offcuts); printer paper, 2 strips (about 0.2 mm together) |

### Step 3. Base + grip

Press the tripod nut into its pocket from the top. Before the run button goes in, pass the run-lead socket end (separate 1-pin housings) in through the base opening and push it up through the base passage from below (nothing is under the passage yet). Then drop the run button into its cradle through the base opening, drawing the slack up through the passage, and press its red cap on through the grip-face hole. Thread the strap. Hold the tub over the base with the base 10 mm back. Push the run-lead sockets on up through the rear (-X) end of the floor run-lead hole into the tub. Lower the tub, tongues through the windows, keeping the lead lightly pulled up so that it stays in the rear end of the hole. Slide the base 10 mm forward (unlocked until step 8); the lead moves to the front end of the hole by itself. Lay the run lead in its floor lane and tape it flat with Kapton; let the socket end hang out over the open +Y side.

| Item | Detail |
|---|---|
| Parts added to the body | `tub` (printed, ASA satin silver); `base_grip` (printed, ASA black); `tripod_nut` (1/4-20 UNC hex nut, steel); `run_button` (pre-wired momentary, red cap (Squid Button class)); `strap` (12 mm hand strap with buckle) |
| Fasteners | 1 x PT 3.0 x 12 thread-forming screw for plastics, pan head, PH1 (EJOT PT K30x12 WN 1411 class / Delta PT 30x12 class; confirm the head on receipt) |
| Driving | `s_j` travels +Z (up, from below), 10 mm engagement into tub j4 lock boss |
| Torque | 0.35-0.5 N m by hand, stop at head contact (FASTENER-POLICY C; provisional until G-PT-1); no threadlocker |
| Tool | tweezers (press the nut with a flat bar); the straight PH1 screwdriver (s_j) |
| Motion | `base_on` (base_grip, tripod_nut, run_button, strap): start at offset (-10, 0, -15), then +Z 15, then +X 10 |
| Harness (WIRING s7) | run lead: before the tub is lowered, push its sockets up through the base passage and the rear (-X) end of the floor run-lead hole (x -41.5..-28, y 1.5..9); lower the tub, slide the base; tape the lead flat in its floor lane (`ko_run_floor`) (**r7 (BX-16): threaded before the tub goes down (`lead_access` run_lead_window)**) |
| Cables | `run_lead` run button -> GPIO26 + GND (pins 37/39) |
| In the body after this step | 6 ids (`layout.present_at(3)`) |

### Step 4. Pi stack + keeper + header leads

Check that the run lead is still taped flat in its lane, with its socket end held out over the open +Y side. Feed the XT30 end (long side front to back) down through the pigtail hole; the taped leg comes down with the stack. Hold the stack's port edge away from the U (more than 10 mm from the W mark). Lower the stack about 3 mm back from the front wall and 2 mm off the right wall; below the right-wall pads move it to the right wall; just above the floor slide it 2.8 forward and set it down on its 4 bosses (the kit screw heads drop into the boss pockets; nothing clicks). Push the XT30 and the free pigtail up into the empty grip bay so that nothing hangs below the grip mouth; it stays there until step 10. Keeper: hold it level from the open left side, 0.5 above its 2 bosses and 1.2 behind its place, slide it in -Y under the stick-guide rail until its port fingers are over the X1203 edge, push it 1.2 forward (the 2 USB fingers go under the Pi), lower it onto its bosses and drive s_k1 and s_k2 straight down: 0.35-0.5 N m, stop at head contact. Plug the HDMI (90 deg plug) on HDMI0, the FPC on CAM1 (camera end loose), the EVF 5 V lead in the upper USB 2 port. With the top open and the header in sight, plug the header ends, one housing at a time: QT lead (250 mm) on pins 1/3/5/6 (red on pin 1, 3V3), the 18/24 lead on 33/34 and the run lead on 37/39 (count from pin 1; a housing one row over puts 5 V from pin 2 on the QT 3V3 wire). Seat each housing straight down with open tweezer tips straddling the wire, pressing on both sides of the housing top, until it stops on the header plastic. Fingers do not fit beside them. Then tug each wire straight up gently: no housing may lift. Use single 1-pin housings (a 1x2 only on 33/34 or 37/39); never a 1x3 or 2x3 shell. Run the QT and 18/24 leads along the right wall and across behind the blower inlet (ko_lead_wall, ko_lead_cross), with the QT splice sleeve in the straight part of the cross run, not in a corner; park their free ends out of the open left side. The run lead crosses over the cooler shroud (ko_run_cross).

| Item | Detail |
|---|---|
| Parts added to the body | `x1203` (Geekworm X1203 UPS (pogo pins, XH lead to any 1S pack)); `x1203_kit` (X1203 kit standoffs + screws); `pi5` (Raspberry Pi 5 (4/8 GB)); `cooler` (Raspberry Pi Active Cooler); `pi_keeper` (printed, ASA black) |
| Fasteners | 2 x PT 3.0 x 12 thread-forming screw for plastics, pan head, PH1 (EJOT PT K30x12 WN 1411 class / Delta PT 30x12 class; confirm the head on receipt) |
| Driving | `s_k1` travels -Z (down, from above), 7.5 mm engagement into tub keeper boss s_k1; `s_k2` travels -Z (down, from above), 7.5 mm engagement into tub keeper boss s_k2 |
| Torque | 0.35-0.5 N m by hand, stop at head contact (FASTENER-POLICY C; provisional until G-PT-1); no threadlocker |
| Tool | straight PH1 screwdriver as step 8 (keeper screws s_k1, s_k2); ESD strap; the microSD is out |
| Motion | `pi_in` (x1203, x1203_kit, pi5, cooler): start at offset (-2.8, 2.1, 80), then -Z 40, then -Y 2.1, then -Z 35, then +X 2.8, then -Z 5; `keeper_in` (pi_keeper): start at offset (-1.2, 60, 0.5), then -Y 60, then +X 1.2, then -Z 0.5 |
| Harness (WIRING s7) | run lead: check it is still taped flat in its floor lane (`ko_run_floor`), socket end out over the open +Y side (**before the stack goes down**); pigtail: feed the XT30 end down through the pigtail hole (x -45..-34, y -13..-4) into the grip, long side front to back; the taped leg comes down with the stack (**before the stack goes down; port edge > 10 mm from the W mark**); micro-HDMI -> Pi HDMI0: 90 deg plug, cable leaves upward (**the EVF end stays loose**); FPC -> Pi CAM/DISP 1: contacts as printed on the cable; latch closed (**camera end loose**); EVF 5 V lead -> Pi upper USB 2 port: USB-A (**PH end loose**); QT lead -> pins 1/3/5/6: red 1, blue 3, yellow 5, black 6; top open, header in sight; one 1-pin housing at a time, seated straight down with open tweezer tips straddling the wire, each wire tugged; splice sleeve in the straight cross run (**count from pin 1: an off-by-one plug puts 5 V (pin 2/4) on the 3V3 wire; never a 1x3 or 2x3 shell**); 18/24 lead -> pins 33/34: GPIO13 on 33, GND on 34 (1x2 or two 1-pin housings; seat with tweezer tips, tug-test); PH end parked out of the left side; run lead -> pins 37/39: GPIO26 on 37, GND on 39 (1-pin housings, or one 1x2; seat with tweezer tips, tug-test) (**route over the cooler shroud (`ko_run_cross`)**) |
| Cables | `fpc` Pi 5 CAM/DISP 1 (port edge) -> GS camera (lower rear); `hdmi` Pi 5 HDMI0 -> EVF board lower edge; `usb_5v` Pi 5 upper USB 2 port -> EVF board 5 V; `qt` encoder -> GPIO 1/3/5/6; `run_lead` run button -> GPIO26 + GND (pins 37/39); `fps_lead` 18/24 switch -> GPIO13 + GND (pins 33/34); `pigtail` X1203 battery pads -> XT30 junction in the grip |
| In the body after this step | 13 ids (`layout.present_at(4)`) |

### Step 5. Plunger + hood + microSD

Hold the plunger in the front-wall hole (flange outside). Lower the hood straight down until the 4 hooks click; the front plate traps the plunger. Push the microSD home through the front slot (both walls) with tweezers, contacts up, until it latches.

| Item | Detail |
|---|---|
| Parts added to the body | `plunger` (printed, ASA black); `hood` (printed, ASA black); `microsd` (microSD card (OS), 32 GB A2 class) |
| Fasteners | none |
| Tool | tweezers |
| Motion | `hood_on` (hood): start at offset (0, 0, 60), then -Z 60 (snaps: hk1, hk2, hk3, hk4); `sd_in` (microsd): start at offset (30, 0, 0), then -X 30 |
| Harness (WIRING s7) | microSD -> Pi slot: push home through the front slot (hood plate + tub wall) with tweezers, contacts up (**after the hood is on**) |
| In the body after this step | 16 ids (`layout.present_at(5)`) |

### Step 6. EVF

Push the eyepiece spigot +X into the rear-wall bore through the housing, flange on the rear face. On the bench: stick the foam pad to the OLED back (adhesive side to the OLED, centred). Fit the flex into the board ZIF and close the latch. Mate the 5 V PH junction with the pair held about 60 mm (a hand's width) out of the open left side. Do NOT plug the HDMI yet. Slide the OLED and the board in together as a tethered pair (OLED and pad into the cell, board into its slot) until the board stops. Keep the PH junction riding above the bottom rail, beside the board's +X face. When the board is home, push the junction -Y and down into ko_5v_end with the 120 mm tweezers. Then (only after gate G-W7 passed) pinch the right-angle HDMI plug's +Y end top and bottom (thumb under it, over the open well), or hold its +Y half in the smooth-jaw pliers (tool 15), cable leading -Y, and feed it in from the open left side (plug top below z 52) under the bottom-rail end to below the board's receptacle, keeping its bottom above the stick-guide top (z 36) until it is under the receptacle. Lift it to the receptacle mouth, then push it straight up until it seats: a fingertip lies flat on the stick-guide top (z 36, under the plug's -Y half) and lifts the plug; if it does not fit there, come up from the open well below (tub floor, open from y 11 to the open side) and push straight up under the plug's +Y half (fingertip, or the end of the steel rule, tool 10, held upright as a push stick), keeping the plug square. Never lever against the board or the guide edge. Coil the HDMI slack over the stick guide (ko_hdmi_coil). From now until the panel is on (step 8) keep the body level or nose-down: only the panel's EVF cap stops the eyepiece moving rearward.

| Item | Detail |
|---|---|
| Parts added to the body | `eyepiece` (Display Components 0PE039-16X glass eyepiece); `hmx039` (Hicenda HMX039-V1 micro-OLED + 50 mm flex); `foam_pad` (closed-cell foam 16 x 14 x 1.0 (OLED pad)); `evf_board` (Hicenda HDMI driver board Rev I) |
| Fasteners | none |
| Tool | tweezers (120 mm, tool 8); fingertip for the HDMI push (on the stick-guide top or up from the open well; the steel rule, tool 10, held upright as a push stick if a fingertip does not fit); smooth-jaw pliers (tool 15) optional to carry the plug |
| Motion | `eyepiece_in` (eyepiece): start at offset (-30, 0, 0), then +X 30; `evf_pair_in` (hmx039, foam_pad, evf_board): start at offset (0, 60, 0), then -Y 15, then -Y 45 |
| Harness (WIRING s7) | flex -> EVF board ZIF: on the bench, contacts per the kit; foam pad stuck to the OLED back first (**ESD: grounded mat**); EVF 5 V lead PH -> board pigtail PH: outside the body, with the pair held about 60 mm out of the open left side, before the slide; the junction rides in above the bottom rail and is pushed into ko_5v_end with the tweezers once the board is home (**never mate live (pack unplugged)**); micro-HDMI -> EVF board: in the body, AFTER the pair is home: plug fed in low under the rail end, lifted to the receptacle, pushed up (+Z) through the bottom-rail gap with a fingertip (guide top, or up from the open well); right-angle plug, cable leaves -Y (**only after gate G-W7 passed**) |
| Cables | `hdmi` Pi 5 HDMI0 -> EVF board lower edge; `usb_5v` Pi 5 upper USB 2 port -> EVF board 5 V; `oled_flex` HMX039 -> EVF board ZIF |
| In the body after this step | 20 ids (`layout.present_at(6)`) |

### Step 7. Lens collar (centred) + camera + adapter

Bench B0 done: tripod block off (2 screws bagged), C-CS adapter seated and marked across adapter and BFAR, back focus set with the Kowa at infinity and the lock screw tight (s recorded), lens off again. Lens collar first, camera still out: feet through the 4 hood holes onto the tub face; start s_c1, s_c2, s_c3 with washers 2 turns. Push the centring gauge for this lens through the collar until its rear cone seats in the tub lip and its front cone in the collar bore chamfer; hold it home with a thumb and tighten s_c1, s_c2, s_c3 from the front, 0.15 N m provisional cap, stop at head contact; pull the gauge out. Camera: plug the FPC into it, bring it in from the left, 11 mm behind its place, then push it +X 11.1 until the adapter has passed the tub lip and the lock tab has gone in between the two tab-catch tines under the hood (if the tab stops on a tine end, roll the camera level and push again) (path: in at 2 mm high, lower 2 mm, then +X 11.1); it rests in its cage (BFAR in the counterbore, tab near the wall) until the lens carries it. Fold the FPC slack into its loop.

| Item | Detail |
|---|---|
| Parts added to the body | `lens_collar` (printed, ASA black); `gs_camera` (Raspberry Pi Global Shutter Camera (tripod block removed at B0)); `c_cs_adapter` (C-CS adapter ring 5 mm (with the camera)) |
| Fasteners | `s_c1` M3 x 10 PH1 + washer; `s_c2` M3 x 10 PH1 + washer; `s_c3` M3 x 10 PH1 + washer |
| Driving | `s_c1` travels -X (rearward, from the front), 3.9 mm engagement into tub insert TL; `s_c2` travels -X (rearward, from the front), 3.9 mm engagement into tub insert TR; `s_c3` travels -X (rearward, from the front), 3.9 mm engagement into tub insert LL |
| Torque | `s_c1` 0.15 N m (FASTENER-POLICY I, M3 into a heat-set insert); `s_c2` 0.15 N m (FASTENER-POLICY I, M3 into a heat-set insert); `s_c3` 0.15 N m (FASTENER-POLICY I, M3 into a heat-set insert); no threadlocker |
| Tool | straight PH1 torque screwdriver (the step 8 driver); collar centring gauge; hands |
| Motion | `collar_on` (lens_collar): start at offset (30, 0, 0), then -X 30; `camera_in` (gs_camera, c_cs_adapter): start at offset (-11.1, 60, 2), then -Y 60, then -Z 2, then +X 11.1 |
| Harness (WIRING s7) | FPC -> GS camera: 15-pin end, latch closed (**fold the slack into `ko_fpc_loop`**) |
| Cables | `fpc` Pi 5 CAM/DISP 1 (port edge) -> GS camera (lower rear) |
| In the body after this step | 26 ids (`layout.present_at(7)`) |

### Step 8. Lens + panel + 5 screws

Lens, panel still off: fit s_c4 loosely. Lay the body on its right side on the folded cloth, open left side up. One fingertip on the centre of the camera cover, from above through the open left side, presses the camera forward (+X) onto its lip catch: push only, never pinch or turn the cover. Pass the lens through the collar. Screw it into the adapter with fingertips until it stops, with no extra snug. The camera turns with it about 3 deg until its metal lock tab meets the hood tab catch, which holds it through metal. Set iris and focus, tighten the 2 thumb screws; push the lens gently rearward until the knurl seats on the collar cone. Stand the camera upright on the bench, one hand on the grip from now until s_c4 is snug (it tips at about 6 deg if let go). With s_c4 still loose, turn lens and camera together the other way until the lock tab stops on the other tine (about 6.5 deg of free roll), then back about half way: a soft stop each way means the tab is free; leave it floating between the tines. The camera now hangs on the lens (it touches neither the tub lip, the counterbore nor the tab-catch tines); snug s_c4 straight down from above, 0.2 N m. Panel (knobs on since step 2): a helper holds the body upright by the grip until the panel is home (never leave it standing on its grip end). Prop the panel about a hand's width (60 mm) off the body, inner face toward it, its bottom edge on a block or book stack as tall as the grip (about 110 mm, so the panel stands level with the body). Mate the 18/24 PH junction first, with both hands, one on each housing. Then plug the QT: one hand steadies the panel, its thumb behind the encoder's +X edge; the other holds the QT plug by its rear end and pushes it into the encoder's rear-side socket (the one nearest the lead), finishing with a fingernail on its back face: it is home when it stops (friction lock, no click). (The header ends went on at step 4.) Move the panel toward the body along -Y, body upright. At about 30 mm off, reach down from above between the body and the panel and lay the spare QT lead as a flat fold in the space between the encoder and the 18/24 switch, on top of the HDMI cable (push the loop by the plug into the fold as the panel closes); lay the 18/24 spare and its PH junction in the same space at the switch end; keep both away from the blower. Keep the body upright until the panel is fully home. Push the panel on along -Y (tongue into the hood groove, boss tabs into the lip notches, flush; the keeper finger is the camera's rear catch). Hold the panel home and turn the camera over onto its hood roof on a folded cloth at the bench edge, grip up, right side toward you and its right face within about 20 mm of the edge, so the driver handle and your hand are past the edge (the lead fold is now closed in by the panel, as in use). Lay a flat block no taller than 25 mm (a closed paperback) on the cloth against the left side, between the eyepiece and the lens, and stand it against a wall, a bench stop or a heavy object so it cannot slide: it bears on the hood band and the panel strip between the knobs and the cloth and keeps the panel home. Drive s_b1 and s_b2 first (now downward). Then drive s_r1 and s_r2 level from the right, the block taking the push; hold the grip with your other hand. 0.35-0.5 N m, stop at head contact. Turn the camera upright, keeping a hand on the grip. Set it down only on its right side: never on its left side (the exposure knob would carry it) and never stand it on its grip end (it tips at about 6 deg).

| Item | Detail |
|---|---|
| Parts added to the body | `lens` (C-mount lens (LENS parameter)); `panel` (printed, ASA satin silver); `encoder` (Adafruit 5880 I2C QT rotary encoder (A0 bridged, 0x37)); `switch_1824` (mini 2-position rotary switch + nut + washer); `knob_exp` (printed, ASA black); `knob_fps` (printed, ASA black) |
| Fasteners | 4 x PT 3.0 x 12 thread-forming screw for plastics, pan head, PH1 (EJOT PT K30x12 WN 1411 class / Delta PT 30x12 class; confirm the head on receipt); `s_c4` M3 x 16 PH1 + washer |
| Driving | `s_b1` travels +Z (up, from below), 7.4 mm engagement into panel boss_b1; `s_b2` travels +Z (up, from below), 7.4 mm engagement into panel boss_b2; `s_r1` travels +Y (toward the panel, from the right side), 10 mm engagement into panel post_f; `s_r2` travels +Y (toward the panel, from the right side), 10 mm engagement into panel post_r; `s_c4` travels -Z (down, from above), 5.3 mm engagement into lens_collar lug insert |
| Torque | 0.35-0.5 N m by hand, stop at head contact (FASTENER-POLICY C; provisional until G-PT-1); `s_c4` 0.2 N m (FASTENER-POLICY I, M3 into a heat-set insert); no threadlocker |
| Tool | PH1 screwdriver, 40 mm+ blade, dia <= 6.5 shank (hand only) |
| Motion | `lens_in` (lens): start at offset (40, 0, 0), then -X 40; `panel_on` (panel, encoder, switch_1824, knob_exp, knob_fps): start at offset (0, 70, 0), then -Y 10, then -Y 30, then -Y 30 |
| Harness (WIRING s7) | 18/24 PH junction: first: a helper holds the body upright, the panel stands 60 mm off on a block about 110 mm tall; mate the 2-pin PH pair with both hands, one on each housing (mating pose `fps_ph`) (**header end went on at step 4**); QT lead -> encoder JST-SH: then: hold the plug by its rear end and push it into the rear-side (-X) socket, finishing with a fingernail on its back face, thumb behind the encoder +X edge (mating pose `qt_enc`); home when it stops (friction lock, no click) (**header end went on at step 4**); QT spare, 18/24 spare, PH junction -> `ko_lead_stow`: at about 30 mm off: flat fold between encoder and switch on the HDMI run; body upright until the panel is home (**nothing over the blower inlet**) |
| Cables | `qt` encoder -> GPIO 1/3/5/6; `fps_lead` 18/24 switch -> GPIO13 + GND (pins 33/34) |
| In the body after this step | 37 ids (`layout.present_at(8)`) |

### Step 9. Exterior

Push the eyecup over the barrel. Fit the sleeve to the stick, push the stick in from the rear. (The knobs went on at step 2; r5: the adapter went in at step 7, the lens at step 8.)

| Item | Detail |
|---|---|
| Parts added to the body | `eyecup` (printed, TPU 95A black); `usb_stick` (SanDisk Extreme PRO USB 3.2 SSD stick); `stick_sleeve` (printed, ASA satin silver) |
| Fasteners | none |
| Tool | none |
| Motion | `stick_in` (usb_stick, stick_sleeve): start at offset (-70, 0, 0), then +X 70 |
| Harness (WIRING s7) | USB stick -> Pi lower USB 3 port: from the rear scoop, sleeve fitted |
| In the body after this step | 40 ids (`layout.present_at(9)`) |

### Step 10. Power

Lay the camera on its right side on the folded cloth (REST_POSES right_down_10; never on its left side, and not on its hood roof now: the eyecup stands proud of it). Draw the pigtail XT30 out of the grip mouth until the whole XT30 housing and at least 15 mm of wire behind it are out (estimate: about 28 mm of wire or more). If it does not reach, stop: never mate it inside the bay. Hold the pack in your palm, its XT30 in your fingers, and plug it into the pigtail XT30, holding both housings. Push the junction and the folded pigtail into the bay ahead of the pack, then push the pack in: the XT30 pair ends up lying flat on the pack top under the run button, the pigtail (female) end to the rear and the fuse sleeve beside it, with the pigtail fold above it. Nothing may hang in the gaps beside the pack, and the pigtail must leave the XT30 female straight, with no bend at its solder cups: if it does not, stop (gate G-MP-PACK). Slide the cap on (-X) until the detent clicks. Turn the camera upright, one hand on the grip. Level the horizon on live view every time: loosen s_c4 half a turn, turn lens and camera together until the horizon is level (window +-1.4 deg: the lock-screw heads keep >= 0.3 off the tab-catch tines; computed `roll_catch` window; a soft stop at about 3 deg either way means the tab is on a tine: come back toward the middle), push the lens back onto the cone, re-snug s_c4 0.2 N m.

| Item | Detail |
|---|---|
| Parts added to the body | `xt30_pair` (XT30 pair (pigtail female + pack male) + fused 18 AWG pigtail (cut length L_cut, PIGTAIL) with its inline 15 A fuse); `pack` (1S2P 18650 pack, BMS, XT30 male lead, pull ribbon); `cap` (printed, ASA black) |
| Fasteners | none |
| Tool | PH1 screwdriver (level check only) |
| Motion | `pack_in` (pack, xt30_pair): start at offset (0, 0, -110.2), then +Z 30.2, then +Z 80; `cap_on` (cap): start at offset (52, 0, 0), then -X 52 |
| Harness (WIRING s7) | pack XT30 -> pigtail XT30: camera on its right side, pack held in the palm; at the grip mouth, the whole pigtail XT30 housing + 15 mm of wire out (estimate about 28 mm), never mated inside the bay; push the junction and the folded pigtail in ahead of the pack, then the pack; the pair ends flat on the pack top, female end to the rear (G-MP-PACK) (**this powers the camera: the X1203 may start the Pi**) |
| Cables | `pack_lead` 1S2P BMS -> XT30 male |
| In the body after this step | 43 ids (`layout.present_at(10)`) |
<!-- END:steps -->

## 3. Checks after each step (by eye and by hand; record them on the build sheet)

| Step | Check |
|---|---|
| 1 | Pigtail joints insulated; meter + to - on the pigtail: no short. Stack square, cooler pins seated, fan lead plugged. A0 bridged. Switch lead heat-shrunk. EVF lead: diode band toward the board, polarity metered (WIRING s7). (r7, BX-3) Pigtail cut to L_cut (200 mm + d_board, G-W2), only if d_board is 25 mm or less (else stopped before the cut: G-W5 drop); U at the W mark (within 1 mm), leg taped flat under the X1203; RTV bead over both joints and 8-10 mm of the pair, tack-free before stacking; no tie to a standoff |
| 2 | Encoder PCB under both cradle hooks; shaft square to the panel. Switch tab in its slot; the knob flat lines up with the "18"/"24" ticks at the two stops. (r7) Switch shaft cut off the panel: 6.7-7.1 above the panel face. Knobs on: a paper strip slides under each knob skirt with light drag (0.2 gap); the shaft ends sit at or below the knob tops |
| 3 | Nut seated flush in its pocket. Run cap 2.5 mm proud of the pad. Base slid the full 10 mm: the tongues sit under the lips and the base no longer lifts off. (r7, BX-16) Run lead threaded up through the floor hole before the tub was lowered, taped flat in its lane, not pinched. It runs up through the -X end of the floor hole, not over the base top; the base slides without catching it |
| 4 | (r7, BX-11) Before the keeper: the run lead still taped in its lane; the pigtail leg still taped flat under the X1203 and the U at the port edge inside the gap to the lip gusset; the U lies at the W mark, not under the keeper finger kf4 or the bar (x -41 and beyond). XT30 down its hole, nothing under the stack. Stack flat on its 4 bosses (no rock); keeper fingers over the X1203 at all 4 stations (look under the Pi at the USB end), keeper flat on its 2 bosses, s_k1 and s_k2 at head contact (tally 1 drive each). HDMI, FPC and 5 V lead plugged at the Pi. **Header: QT red on pin 1 (3V3, the corner pin by the cooler end), 18/24 on 33/34, run on 37/39; count the pins, photograph the header.** (r7, BX-10) Header: 8 contacts on pins 1, 3, 5, 6, 33, 34, 37, 39; single housings (or 1x2 on 33/34, 37/39); all housing tops level; each wire tugged. QT and 18/24 leads along the right wall and across behind the blower inlet; the QT splice sleeve in the straight part of the cross run; run lead over the cooler shroud, below z 40 |
| 5 | Hood level on the wall tops all round; 4 hooks clicked; plate 0.2 off the front wall. Plunger moves in and returns on the Pi button spring (0.6 travel, presses 0.35). microSD latched (tip about 2.5 mm proud of the Pi edge, inside the slot) |
| 6 | Spigot flange flat on the rear face. OLED in its cell with the foam pad stuck to its back; board fully home in its slot; flex in the ZIF, latch closed (mated outside, pair slid in together). PH junction in `ko_5v_end`, clear of the bottom rail. HDMI plug pushed fully up into the board through the rail gap (no gap between the plug and the board edge: seen from the open left side with a small mirror (tool 17), or felt with a fingertip). HDMI coil over the stick guide (`ko_hdmi_coil`), clear of the cooler inlet. (r7) From here until the panel is on (step 8), keep the body level or nose-down |
| 7 | (r6) Collar first: 4 feet flat on the tub face through the hood holes; the centring gauge seated on both cones (no rock) while s_c1..s_c3 went to head contact at 0.15 N m on the torque screwdriver; washers under every head; gauge out. (r5) Then the camera in its cage: the adapter past the tub lip, the BFAR in the counterbore, the camera resting, not wedged (it lifts and turns slightly by hand); the adapter mark lines up. FPC folded into the loop space, not touching the blower inlet |
| 8 | (r5) Lens: thumb screws set; the knurl seated on the collar cone (push it gently rearward: no axial play); the camera hangs on the lens: look through the open left side, it touches neither the lip, the counterbore nor the tab-catch tines; check by feel (r7 fix-up: the hood roof hides the tines): with s_c4 loose, turn lens and camera gently both ways: a soft stop each way at about 3 deg means the tab is free between the tines; it was left mid-way before s_c4 was snugged; s_c4 at 0.2 N m. (r7, BX-2) QT plug fully seated at the encoder (fingernail push on its back face) with the panel propped 60 mm off and the 18/24 PH junction mated first (both hands); the body held upright by a helper. Before the last 30 mm of panel travel the QT fold, the 18/24 spare and the PH junction lie between encoder and switch on the HDMI run; nothing over the blower inlet; the panel closes without pressure. Panel flush with the hood band and the tub. 4 screws at head contact, none stripped. (r7) Panel screws driven in the hood-down pose at the bench edge (driver handle past the edge), block against the left side and stopped from sliding; the camera was never on its left side and never left standing on its grip end. The dials turn; nothing rubs inside |
| 9 | The eyecup sleeve over the eye-end body (r7: the knobs went on at step 2). Stick in, sleeve flush with the rear face (r5: the lens was checked at step 8) |
| 10 | (r7, BX-3) Camera on its right side, pack held in the palm. The whole XT30 housing and 15 mm or more of wire out of the grip mouth before mating (estimate about 28 mm), else stop: never mated inside the bay; no loop beside the pack. The XT30 pair lies flat on the pack top under the run button, female end to the rear, fuse sleeve beside it; the pigtail leaves the female straight, no bend at the solder cups (else stop, G-MP-PACK). Cap detent clicked. Power on with the plunger; (r5) level check on live view every time (r7 fix-up): s_c4 half a turn, turn lens and camera together until the horizon is level (window +-1.4 deg; r7: the lock-screw heads keep >= 0.3 off the tab-catch tines, computed `roll_catch` window), push the lens back onto the cone, s_c4 0.2 N m; the EVF shows the boot screen (there are no LED indicators: user decision 2026-10-05). Then WIRING G-W8 to G-W12 in the closed body (G-W12: full-workload power test). G-W4 to G-W7 and G-W13 (option C) are bench gates that ran before assembly (s1 Gates before assembly) |

## 4. Screws (the 4 enclosure screws at step 8; the 2 Pi-keeper screws at step 4; the J4 lock s_j at step 3; r5: the lens-collar M3 screws s_c1..s_c3 at step 7 and s_c4 at step 8)

The totals (PT body screws, and the X1203 kit M2.5 screws and standoffs counted separately) are generated in
DESIGN.md s1.1 (`counts`).

<!-- BEGIN:screws -->
| Screw | Kind | Joins | Into | Head point (x, y, z) | Travels | Engagement (mm) | Counterbore | Step | Driver | Torque (N m) |
|---|---|---|---|---|---|---|---|---|---|---|
| `s_b1` | PT 3.0 x 12 | base_grip + tub | panel boss_b1 | (-91, 27.9, -2) | +Z (up, from below) | 7.4 | dia 7 in `base_grip`, z -8..-2 | 8 | PH1, bit dia <= 6.5 x 40+ | 0.35-0.5, stop at head contact |
| `s_b2` | PT 3.0 x 12 | base_grip + tub | panel boss_b2 | (-105, 27.9, -2) | +Z (up, from below) | 7.4 | dia 7 in `base_grip`, z -8..-2 | 8 | PH1, bit dia <= 6.5 x 40+ | 0.35-0.5, stop at head contact |
| `s_r1` | PT 3.0 x 12 | tub | panel post_f | (-31.5, -32.4, 85.5) | +Y (toward the panel, from the right side) | 10 | dia 7 in `tub`, y -35..-32.4 | 8 | PH1, bit dia <= 6.5 x 40+ | 0.35-0.5, stop at head contact |
| `s_r2` | PT 3.0 x 12 | tub | panel post_r | (-143.5, -32.4, 47.5) | +Y (toward the panel, from the right side) | 10 | dia 7 in `tub`, y -35..-32.4 | 8 | PH1, bit dia <= 6.5 x 40+ | 0.35-0.5, stop at head contact |
| `s_k1` | PT 3.0 x 12 | pi_keeper + tub | tub keeper boss s_k1 | (-99.5, 16, 14.3) | -Z (down, from above) | 7.5 | dia 7 in `pi_keeper`, z 14.3..15.6 | 4 | PH1, bit dia <= 6.5 x 40+ | 0.35-0.5, stop at head contact |
| `s_k2` | PT 3.0 x 12 | pi_keeper + tub | tub keeper boss s_k2 | (-64, 28.2, 14.3) | -Z (down, from above) | 7.5 | dia 7 in `pi_keeper`, z 14.3..15.6 | 4 | PH1, bit dia <= 6.5 x 40+ | 0.35-0.5, stop at head contact |
| `s_j` | PT 3.0 x 12 | base_grip + tub | tub j4 lock boss | (-111, -20, -2) | +Z (up, from below) | 10 | dia 7 in `base_grip`, z -8..-2 | 3 | PH1, bit dia <= 6.5 x 40+ | 0.35-0.5, stop at head contact |
| `s_c1` | M3 x 10 + washer | lens_collar + tub | tub insert TL | (3.3, 11, 90.5) | -X (rearward, from the front) | 3.9 | dia 7.5 in `lens_collar`, x 2.8..8.6 | 7 | PH1, bit dia <= 6.5 x 40+ | 0.15 (machine thread in a brass insert) |
| `s_c2` | M3 x 10 + washer | lens_collar + tub | tub insert TR | (3.3, -11, 90.5) | -X (rearward, from the front) | 3.9 | dia 7.5 in `lens_collar`, x 2.8..8.6 | 7 | PH1, bit dia <= 6.5 x 40+ | 0.15 (machine thread in a brass insert) |
| `s_c3` | M3 x 10 + washer | lens_collar + tub | tub insert LL | (3.3, 28, 36) | -X (rearward, from the front) | 3.9 | dia 7.5 in `lens_collar`, x 2.8..8.6 | 7 | PH1, bit dia <= 6.5 x 40+ | 0.15 (machine thread in a brass insert) |
| `s_c4` | M3 x 16 + washer | lens_collar | lens_collar lug insert | (4.7, -31, 66.5) | -Z (down, from above) | 5.3 | none: washer on the upper-lug top (spot face) | 8 | PH1, bit dia <= 6.5 x 40+ | 0.2 (machine thread in a brass insert) |
<!-- END:screws -->

s_b1 and s_b2 go up through the base counterbores into the panel bosses. Since the r2 fixer pass the base slide (J4) is
locked by its own screw s_j (step 3), so taking s_b1/s_b2 out for panel service no longer frees the base. s_r1 and
s_r2 go in from the plain right side through the wall pads into the panel posts. The straight-driver audit in
`build_d2.py` (SPEC s5) places a dia 6.5 x 40 bit plus a dia 30 x 100 handle on each axis against every part present
at the screw's own step (3, 4, 7 or 8); its result is in DESIGN.md. r5: s_c1..s_c3 are M3 machine screws into tub
inserts, driven along -X from the front before the lens is fitted (with the lens fitted, the driver handle hits the
Kowa front barrel); s_c4 is driven straight down from above and is the last operation on the lens (FASTENER-POLICY I).

## 5. Battery use

- **Charge out of the camera.** The pack has no charge port in the body (WIRING W-7). Charge it on a 1S Li-ion
  charger with an XT30 lead (BOM D2-67) at 2 A or less, to 4.20 V; never unattended; on a non-flammable
  surface.
- **Fit.** Lay the camera on its right side on a folded cloth (r7 fix-up). Slide the cap off forward (+X, 52 mm).
  r7 (BX-3): draw the pigtail XT30 out until the whole housing and at least 15 mm of wire behind it are out of the
  grip mouth (estimate: about 28 mm or more). If it does not reach, stop and do not mate inside the
  bay; re-check the cut length (G-W2). Hold the pack in your palm and plug its XT30 into the pigtail XT30 at the grip
  mouth, red to red, holding both housings. Feed the folded pigtail and the junction in ahead of the pack, then the
  pack, ribbon last. The pair ends flat on the pack top under the run button, female end to the rear, fuse sleeve
  beside it; the pigtail leaves the female straight (else stop, G-MP-PACK). Look up the mouth
  before the cap: no loop beside the pack. Slide the cap on rearward until the detent clicks.
  The X1203 may start the Pi as soon as the XT30 meets.
- **Remove.** Shut down first (section 7 P1: hold the plunger 2 s; the EVF shows the shutdown screen, then goes dark;
  wait 5 s more). Slide the cap forward, pull the pack
  by its ribbon; the XT30 junction follows; unplug it by the housings, never by the wires.
- **Runtime.** About 1 h at the 18 W planning load (WIRING s4, unmeasured). The EVF overlay shows the gauge reading.
- **Handling (r7, BX-13; fix-up VERIFY-C5).** Set the camera down on its right side; never on its left side, and never
  stand it on its grip end (it tips at about 6 deg: computed `handling` rest_pose stability; hold it by the grip when
  upright). Never on its left side: the exposure
  knob is the highest point there, and resting on it presses the encoder push switch (computed: `handling`
  `rest_pose` rows).
- **Storage.** Out of the camera at about 3.7-3.8 V per cell for anything longer than a few days. With the pack in
  and the Pi halted, the X1203 still draws a standby current (G-W8 records it).

## 6. Storage media

- **USB stick (recording).** Shut down or stop recording. Pull the sleeve's lip at the rear scoop: the stick comes out
  rearward with its sleeve. Push it back in the same way until the sleeve is flush with the rear face.
- **microSD (OS only).** Internal electronic service: first section 7 prerequisite P1-P4 (shut down, cap off, pack
  out, XT30 parted). Then through the slot low in the front plate (y -11.5..0.5, z 16-18.6: below the lens collar, on the right-hand side of the plunger as you hold the camera) with fine tweezers;
  the card is not swapped in normal use.

## 7. Service order (exact reverse of section 2 and `layout.INSERTIONS`)

**Isolation prerequisite (r3, audit 2026-10-05 correction 1). It applies to EVERY internal electronic service: the
panel-only route (EVF board, encoder, camera, leads), the microSD, the hood, the Pi stack and the base. There is no
shortcut.** A halted Pi is not established electrical isolation: the plunger only asks the Pi to shut down, the X1203
keeps a standby draw with the Pi halted (G-W8 records it), and the states of the downstream rails (Pi 5 V, 3V3, the EVF
5 V feed) with the Pi halted have not been measured. The only isolation this design has is physical: the pack off its
XT30. No switch is added for this; none is needed.

- **P1.** Shut down: hold the plunger 2 s. The EVF shows the shutdown screen until the system has halted, then goes
  dark; wait 5 s more before P2. There are no LED indicators (user decision 2026-10-05): the EVF is the status display.
  EVF dark at halt is expected from the configuration (`POWER_OFF_ON_HALT=1` switches off the Pi USB port that feeds
  the EVF, WIRING s8) and is confirmed only on the bench by G-W4 and G-W8 (not run). If the shutdown screen never
  appeared (the live image is still shown), hold the plunger 2 s again. If the shutdown screen was shown and then
  went away but the EVF stays lit (blank, no-signal or backlight only), do not press the plunger again: a press while
  halted boots the Pi (WIRING G-W8). Wait 5 s, go on to P2 and record it, because the expected EVF-dark sign did not
  hold (a G-W4 / G-W8 finding). Either way EVF dark is not isolation: P3-P4 are.
- **P2.** Slide the cap +X 52 off the grip.
- **P3.** Pull the pack out of the bay by its ribbon; the XT30 junction follows it to the grip mouth (the junction sits
  above the pack in the bay and cannot be reached with the pack in place; r3 fix-baseline, verifier VBD-7). r7 (BX-3):
  the pigtail is long enough for the whole XT30 housing and at least 15 mm of wire (estimate about 28 mm) to come out
  of the mouth. Lay the camera on its right side for this (r7 fix-up).
- **P4.** Unplug the pack XT30 from the pigtail XT30 by the housings, never by the wires. Set the pack aside: it stays
  out until the body is closed again.

Only after P4 does any screw come out or any internal lead come apart. Close in the reverse order: body closed first,
then the pack in and the XT30 mated last (section 2 step 10), as in the initial assembly.

1. Prerequisite P1-P4 above (pack out of the camera).
2. Full service (hood or Pi stack, items 8-11): pull the USB stick and sleeve out rearward (-X 70), pull the eyecup
   off the barrel (reverse step 9; r7: the knobs stay on: they ride with the panel). **r5 removal order for the hood or the Pi
   stack:** panel (items 3-5), then the lens (item 6a), then the camera with its adapter (item 6b), then the lens
   collar (item 6c), then the EVF, microSD and hood (items 7-9). The collar's feet pass through the hood plate, so the
   hood never lifts with the collar on (CAD: `hood_off`, `keeper_out` and `pi_out` list the collar and s_c1..s_c4 as
   off). **Panel-only service** (items 3-7) may leave the lens, the collar, the eyecup, the stick and the strap
   fitted: the panel clears them (CAD record `panel_off` below). The pack is already out (item 1).
3. Panel screws (tool 1 only), **after item 1**. r7 (BX-13): pull the eyecup off first (the panel still clamps the
   eyepiece): it is the highest point when the camera lies on its hood roof. Use the step-8 pose (hood roof down on a
   folded cloth at the bench edge, right side toward you and its right face within about 20 mm of the edge so the
   driver handle and your hand are past the edge; a block no taller than 25 mm against the left side for s_r1/s_r2,
   stood against a wall or a heavy object so it cannot slide; CAD record `REST_POSES` `hood_down_s7`, driver-plane
   rule), then turn the camera upright, a hand on the grip, before item 4. Remove s_r1, s_r2 (from the right) and s_b1, s_b2
   (from below, up through the 2 base counterbores) with the straight PH1 driver. Each screw has used one of its 5 drives (tally).
   Take a tripod plate off first (it covers s_b1/s_b2); the strap does not reach the s_b1/s_b2 driver line (y 27.85).
   **Base (r2 fixer, verifier M-V-MPS-5):** in r2, s_b1 and s_b2 were also the only lock of the base slide (J4), so
   panel service could free the body to slide 10 mm off the base and drag the run lead and the XT30 pigtail across the
   floor-hole and base-window edges. The base now has its own lock screw s_j (step 3, at (-111, -20) from below),
   which stays in for panel and Pi service. While the panel is off, keep the body on its right side on the bench (never standing on its grip end: it tips).
4. Panel: pull it straight out along +Y about 60 mm by hand (the 2 boss tabs leave the lip notches, the tongue leaves
   the hood groove, the knobs ride out on their shafts; r7: the QT fold, the 18/24 spare and the PH junction come out
   with it, and the QT lead is still plugged at the encoder). There is no skirt, barb or latch any more (r2, finding 3): there is no
   flexing latch; the number of openings is limited by the PT boss tally (FASTENER-POLICY C, provisional until G-PT-1)
   and is checked physically by G-PANEL-1 (not run). CAD record: `layout.REMOVALS`
   `panel_off`, swept with the strap, cap, pack, lens and stick in place. That sweep is **geometry evidence only** (the
   panel path does not collide with those parts); it says nothing about the electrical state and is never permission
   to open the panel or part a lead with the pack connected. The pack is out (item 1) before this item. Physical gate
   G-PANEL-1 (coupons base_edge_*). The panel's EVF cap releases the spigot clamp: the eyepiece stays in its bore and half-collar, but do
   not pull the eyecup while the panel is off.
   **4a. Knob change (r7, BX-5):** pull the old knob straight off (+Y): the panel backs the encoder for a pull. To fit
   a knob, take the panel off first (items 3-5) and press it on at the bench as in step 2, thumb behind the encoder
   board, on the 2 paper strips (tool 16). Never press a knob on with the panel on the body.
5. Leads (pack already out, item 1): with the panel about 60 mm off, propped on the step-8 block, hold the QT plug
   by its rear end (not the wire) and pull it straight out of the encoder, then part the 18/24 PH junction (the
   header ends stay on). To close: reverse step 8 in the step-8 pose (r7 fix-up: a helper holds the body upright, the
   panel propped 60 mm off on a block about 110 mm tall; the PH junction mated first with both hands, then the QT
   plug pushed home with a fingernail; the spares folded into `ko_lead_stow` at about 30 mm; panel on along -Y, boss tabs
   into the notches; hood roof down, block against the left side; 4 screws at 0.35-0.5 N m); only then the pack and
   cap (step 10).
6. Camera, lens and collar (r5; pack out, item 1; panel off, items 3-4):
   a. Lens: loosen s_c4 one turn (straight PH1 from above). Unscrew the lens with fingertips: the tab catch holds the
      camera, and no hand touches it. Lift the lens out forward (+X 40). Check both paint marks (B0). (CAD record
      `lens_off`.)
   b. Camera (reverse `camera_in`, CAD record `camera_out`): unfold the FPC, pull the camera and its adapter -X 11.1
      back through the tub lip, lift 2, take it out along +Y 60; unplug the FPC at the camera. The collar may stay.
   c. Collar (CAD record `collar_off`; only for a collar swap or the hood / Pi routes): s_c1, s_c2, s_c3 out from the
      front (PH1 along -X), then the collar +X 30 off the tub face and out of the hood holes. The inserts stay in the
      tub; no drive tally (machine thread in brass). r6 (audit X2): a collar always goes back on with the camera
      out (item b) and the centring gauge of that collar's lens, as step 7.
   To close: step 7 (collar with the centring gauge, s_c1..s_c3 0.15 N m on the torque screwdriver (provisional cap;
   G-COL-1), gauge out, then the camera), step 8 (the lens as step 8 (body on its right side, fingertip push on the cover centre, tab catch
   holds; then upright, hand on the grip: with s_c4 still loose, turn lens and camera together the other way until
   the lock tab stops on the other tine (about 6.5 deg of free roll), then back about half way, so the tab floats
   between the tines), s_c4 0.2 N m, then the panel), and the step 10 level check.
7. EVF (r7, C-16; reverse `evf_pair_in`, `eyepiece_in`; pack out, item 1; CAD record `evf_out`): uncoil the HDMI.
   Lift the 5 V PH junction out of `ko_5v_end` with tweezers (tool 8). Unplug the HDMI straight down through the
   bottom-rail gap: one fingertip, coming from the right of the board (+X), pushes up under the free end of the
   bottom-rail slab (y 23-28) while the pliers (tool 15) grip the plug body on its left and right faces at its deep
   half and pull it straight down. Never pull the cable, never rock the plug. Then slide the OLED, the pad and the
   board out together along +Y 45 (the pad is stuck to the OLED and comes out with it). Outside the body, part the PH
   junction and the flex. Pull the eyepiece out -X 30 through the housing. To close: step 6 (HDMI plugged last, in
   the body).
8. microSD (pack out, item 1): pull it out through the front slot with tweezers (it must be out before the stack moves).
9. Hood (r2 fixer, verifier M-V-MPS-2; CAD records `layout.REMOVALS` `hood_off` and `RELEASE_ACCESS`): with the panel,
   lens, camera, lens collar (r5), eyepiece and EVF pair out (items 4-7) and the microSD out (item 8), push one release pin (tool 9) straight
   into each of the 2 dia 1.6 holes in the right wall at hk1 (x -45) and hk2 (x -125), 9.6 mm below the hood seam
   (z 87.7), until it stops (about 3 mm in: it deflects the tooth 0.55, 0.15 clear of the ledge). The pins stay in by
   friction, so the 2 releases are made one at a time and stay made. Then lift the hood straight up 60: hk3 (front)
   and hk4 (rear) have a 45 deg return catch and cam out at the insertion strain. Take the plunger out of its hole and
   pull the 2 pins. Refit: pins out, drop the hood straight on until all 4 click. Computed only: pin reach 0 mm3 on any
   other part, strain at the pin 1.51 % nominal / 2.26 % with Kt (limit 2.5 %). Physical gate G-SNAP-2 (hook coupons +
   5 remove/refit cycles of the whole hood): not run. If a hook whitens, the hood is a replace-on-service print.
10. Pi stack (r2, finding 1: non-destructive). Tools to reach and remove it: the straight PH1 driver (tool 1, panel
    and keeper screws), the 2 hood release pins (tool 9, item 9), tweezers (tool 8, microSD, item 8) and the ESD strap
    (tool 12).
    a. With the pack out (item 1), unplug the header leads (QT 1/3/5/6, 18/24 33/34, run 37/39), the HDMI, the FPC and the 5 V lead; lay them out
       of the open left side (they cross the keeper's driver lines and its +Y exit).
    b. Keeper screws: remove s_k1 (behind the USB end, x -99.5) and s_k2 (port edge, x -64) straight up with the PH1
       driver; tally one drive each (5 per boss, then the M3 insert fallback, FASTENER-POLICY D-E).
    c. Keeper (reverse `keeper_in`, CAD record `layout.REMOVALS` `keeper_out`): lift it 0.5 off its bosses, pull it
       1.2 rearward (-X: the 2 USB fingers leave the underside of the Pi), then slide it out along +Y 60 through the
       open left side. It is rigid: nothing flexes, nothing breaks.
    d. Stack (reverse `pi_in`, `REMOVALS` `pi_out`): lift 5, -X 2.8, up 35, +Y 2.1, up 40. Nothing latches it, so it
       lifts off its 4 bosses freely; keep the XT30 pigtail feeding up through its floor hole as it rises. r7 (BX-11):
       the taped leg and the RTV stay on the X1203; lift the stack straight up with the pigtail following through
       the hole (XT30 long side front to back).
    To refit: section 2 step 4 (stack down on its bosses, keeper in, s_k1 and s_k2 at 0.35-0.5 N m, stop at head
    contact). Physical gate G-KEEP-1 (coupons `coupon-pi-keeper-*`: the whole keeper, a tub floor coupon with both
    keeper bosses and the 4 Pi bosses, and 2 flat stand-in boards on the real X1203 kit): 5 full keeper cycles on
    printed parts, not run. Far-corner stack tilt (verifier M-V-MPS-4): the 4 keeper fingers sit on 2 adjacent edges,
    so the r2 fixer added a CAD restraint: the hood stack-stop post (`layout.HOOD_STACK_STOP`, 0.15 over the far kit
    screw head; it comes off and goes on with the hood). Computed check `stack_retention`
    (`checks.check_stack_retention`): the stack CoM lies inside the retention hull and the largest rigid lift is within
    its limit (numbers in DESIGN.md). Physically open: the bench tilt/knock and retention test with the real stack under
    a printed hood (G-KEEP-1 follow-up), not run.
11. Run lead (pack out, item 1): pull its socket end down through the floor hole. Base: remove s_j (from below, tool 1; r2 fixer), then
    slide the base 10 mm rearward and lift it off the
    tongues (no skirts to remove: r2, finding 3).

**Lens swap (r5; no isolation needed, nothing electrical is touched).** With the panel on, the camera rests in its
cage: the tub lip ahead, the panel keeper behind, the hood tab catch either side of its lock tab. Loosen s_c4 one turn (straight
PH1 from above). Tip the body nose-down. Carry the lens with one hand and unscrew it with fingertips only: the camera turns
with it about 3 deg until its lock tab meets the tab catch, which holds it through the metal housing. A stuck
thread: stop, never more than fingertip torque. G-CAM-2 repeats its corner check after 5 swaps. Then check both paint marks (B0 item 3; audit B-2):
if the adapter came out with the lens, refit it before anything else. Fit the new lens the same way, carrying its
weight so that the camera only sees the thread torque. Tip the isolated body nose-down so the camera comes forward onto its lip catch before starting the thread; never force a thread that will not start. Push the lens rearward until its band seats on the collar cone. Body upright, one hand on the grip: with s_c4 still loose, turn lens and camera together the other way until the lock tab stops on the other tine (about 6.5 deg of free roll), then back about half way, so the tab floats between the tines (r7 fix-up, VERIFY-C4). s_c4 0.2 N m; then the step 10 level check (always: set the horizon level, window +-1.4 deg). A lens
with a different band needs its own collar (a Fujinon collar for the Fujinon): panel off, items 6a-6c (camera out),
then step 7 with that collar's centring gauge, then step 8. The back focus was set for the Kowa at B0: check infinity on live view with the new lens and, if
it is off, reset s with the camera out (B0) and record it.

Re-assemble from section 2. Replace any hood hook that has whitened. Use the insert fallback on any boss that spins.

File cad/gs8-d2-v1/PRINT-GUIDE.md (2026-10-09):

# GS8 D2 release v1: print guide (`cad/gs8-d2-v1`)

Release r5, 2026-10-06 (first written 2026-10-04 by the docs owner; r4 adds the modifier meshes of s1.1; r5 adds the
lens collar, the tub insert bosses and the hood without its turret). How to print the 12 printed production parts of D2 (count: DESIGN.md s1.1 `counts`). `build_d2.py` writes one STL per part with
the print orientation built in (`out/stl/<part>.stl`: Z0 is the bed and the "face down" of the table is on the bed);
load them unrotated. The tables between `BEGIN`/`END` markers are generated by `make_tables.py` from `layout.py` and
the build's `out/print-manifest.json`. While a module is still a stub, its row shows the **layout estimate** (shell area x
wall x feature factor) instead of the solid. Re-run `python cad/gs8-d2-v1/make_tables.py` after every build.

Nothing here has been printed. Times and filament are estimates; re-slice to get real figures.

## r6 (2026-10-08): the print order and orientation are settled

- **Order (section 7, generated).** One table in `layout.py` (`PRINT_PREREQS`, `COUPON_PREREQS`, `PRINT_SEQUENCE`)
  says which recorded gates must pass before each part or coupon set is printed. They are the measurements that set
  the part's geometry (the MEASURED-PARTS "Blocks" column) plus the profile, knob and collar calibrations.
  - The build enforces it. A slicer record for a part is rejected if it was filed before those gates passed, and the
    same goes for a G-COL-1 coupon record. The receipt's `print_release` lists the parts the records release now.
  - The tub, hood and panel wait for MP-CAM with its lens line (audit 2026-10-06 M2); so do the EVF, Pi and stick
    measurements that also shape them. The collar also waits for G-COL-1.
- **Orientation (section 3, generated).** Every part keeps its face-down. The new computed check `print_overhang`
  slices each production STL in its print pose every 0.2 mm and accounts for all new area beyond the 45° allowance.
  Each patch must be one of these, or the build fails:
  - a short overhang, no more than 1.0 mm from supported material;
  - an anchored bridge of 30 mm or less;
  - a bridge that ends at a screw hole, which is reported;
  - inside a declared support zone.

  It confirmed the bridges this guide lists and found two chins nobody had listed. The s_k2 keeper boss and the LL
  collar-insert boss each print as a flat ledge off a wall, so the tub now has 4 small paint-on supports instead of 2.
- **The collar ears are r 5.6** (review A3). The 0.6 bed chamfer had left 0.65 mm of ear wall in the first layers; it
  is now 1.25.
- **New printed tool:** the collar centring gauge `stl/tools/collar_gauge.stl` (audit X2), printed with the G-COL-1
  coupons and used at assembly step 7.

## Cloud-polish print stock and finish datums

This document in the copied `r5-cloud-polish-20261007` fork does not supersede any later desktop work. For the lens
collar only, the production STL and `collar_part` coupon include three 0.2 mm sacrificial membranes across the
3.4 mm anchor holes, inside the first washer-seat bridge layer. This gives bridge lines a continuous roof instead
of ending in a hole. Clear only those three holes to 3.4 mm by hand and remove debris before screws or inserts are
assembled. Leave the washer seat planes, cone and feet unchanged. STEP/assembly checks describe the cleared part;
`print-manifest.json` records print stock, finished volume and postprocessing separately. Slicer and coupon gates
remain open: inspect one complete bridge layer and a flat washer seat in the actual slicer and G-COL-1.

The collar rear-bore land is 1.6 mm before the 45-degree seat cone, removing the unused thin entry feather.
Do not enlarge or chamfer it by hand; it is part of the checked profile. The lens seat and band datum have not moved.

The s_c4 upper-lug bearing edge deliberately stays square so its washer is fully supported. Use normal elephant-foot
compensation there and remove only loose burrs, never a chamfer beneath the washer. All other bed-edge rules remain.
The existing envelope, part count, washer type, front cone, fixed-band datum and PH1 driver access are preserved.

The panel encoder cradle now has 1.0 mm tooth lands (1.62 mm probed root), preserving the catch plane while extending
the free tips 0.6 mm. Use the regenerated encoder-cradle coupon and repeat G-SNAP-2; old coupons do not validate it.
The included DejaVu Sans Bold font file is hash-pinned, so the printed lettering is reproducible across computers.

## 1. Material and machine

| Setting | Value |
|---|---|
| Material | ASA for every rigid part (satin silver: tub, panel, stick sleeve; black: hood, base + grip, cap, knobs, pi_keeper, plunger, lens collar, collar centring gauge). TPU 95A for the eyecup. One colour per part, no painting except the engraving fill. r6 (audit B-8): print the lens collar in ASA. G-W11 now logs a thermocouple on the collar's LR foot at the tub front wall; if it reads above 50 C, reprint the collar in PC and repeat G-COL-1 on PC coupons |
| Drying | ASA 4 h at 65-80 C; TPU 4-6 h at 50-55 C; print from a dry box |
| Nozzle / layer | 0.4 mm / 0.2 mm (the first layer 0.2 too: the panel engraving is cut 0.4 = 2 layers into its bed face) |
| Temperatures (ASA) | nozzle 250-260 C, bed 100-110 C, enclosed chamber 45 C or warmer, part fan 0-20 %; no draft |
| Bridges (ASA) | bridge fan 60-100 %, bridge flow 0.85-0.9, bridge speed about 20 mm/s; the enclosure stays closed. Functional bridged faces: the hood J2 groove lip (5 x 20 mm between piers), the base run-button shelf and rear stop (24.2), the tub and base counterbore shoulders (head bearing faces of s_r1/s_r2, s_b1/s_b2), the pi_keeper s_k1 counterbore and s_k2 spot-face, the collar washer seats (membranes). r6: `print_overhang` measures every bridge span per part (section 3); the longest is 24.7 (base shelf), all within FDM MAX_BRIDGE 30. Bridges that end at a screw hole are listed there as "around a hole": check those head bearing faces flat in section 5 |
| Temperatures (TPU) | nozzle 220-230 C, bed 50 C, 20-25 mm/s, retraction short or off |
| Shrink | XY shrink compensation in the slicer profile (measure it once on a 100 mm coupon). Never scale the models |
| Bed faces | 0.2-0.3 mm elephant-foot compensation. The **outer** bed-face edges carry 0.6 x 45 deg chamfers (`FDM['BED_CHAMFER']`); never a round on the bed. Inner bed-face openings (base keyhole windows 18.5 x 36.5, tripod-nut pocket, s_b holes, tub s_r counterbores) are sharp and rely on the elephant-foot compensation; deburr them (section 5) |
| Clearances built in | SLIDE 0.25, LOCATE 0.15, SEAM 0.3 per side (`layout.FDM`). Do not add slicer hole or XY offsets on top; if a coupon (section 6) shows a tight fit, change the profile, not the model |
| Supports | Every support is a declared zone (`layout.PRINT_SUPPORT_ZONES`) that `print_overhang` checks; no other region needs one. **tub:** 4 paint-on supports: 2 under the T-tongue -Y wings (each about 7.8 x 1.6, towers about 17 mm from the bed; they carry the grip joint J4, never skip them) and (r6) 2 under the flat boss chins: the s_k2 keeper boss (2.9 x 7.3, about 59 mm up, beside the X1203 edge) and the LL collar-insert boss (3.3 x 2.4, about 59 mm up, at the front wall). Both chins clear a board by 0.25-0.3 in the camera and would droop toward it unsupported; paint the support on the right wall's inner face under each chin and remove it through the open left side. **hood:** tree supports in 1 place since r5 (the lens turret and its support are gone): the eyepiece housing +Y strip under its window. Nothing else (the hood housing ceiling is a self-supporting 15.2 bridge). r2 fixer: the hood's stack-stop fin and post (17.5 x 3.7 fin, then a 4.2 x 3.7 post, about 75 mm tall from the roof) print straight up from the roof without supports; check that the post tip is not stringy (it sits 0.15 over the kit screw head) |
| Brim | 5 mm on the tub, the base + grip, the hood (roof) and the panel (face); none on the small parts |
| Beds | 250 x 210 x 220 (Prusa MK4 / Core One) and 256 x 256 x 256 (Bambu X1/P1). Section 2b |
| Seams | aligned rear, on an inside corner where the part has one (never on the panel face or the hood plate) |
| Modifier meshes (r4) | **Load every `out/stl/modifiers/<part>__mod_*.stl` of a part as a modifier mesh** (40 % infill, 4 perimeters) at its exported position; s1.1 |

### 1.1 Modifier meshes (r4)

FASTENER-POLICY sets 4 perimeters and a 40 % infill modifier 8 mm round every PT pilot. The build now exports those
zones as meshes in each part's print pose (`layout.print_modifiers`, the `print_modifiers` check confirms each one
overlaps its part), so nobody draws them by hand:

| Part | Modifier files (`out/stl/modifiers/`) | Zones |
|---|---|---|
| `tub` | `tub__mod_s_b1`, `_s_b2`, `_s_r1`, `_s_r2`, `_s_k1`, `_s_k2`, `_s_j`, (r5) `_s_c1`, `_s_c2`, `_s_c3` | dia 16 cylinders along every screw that passes the tub: the s_r counterbore pads, the 2 keeper bosses, the j4 lock boss, the floor round s_b1/s_b2 and (r5) the 3 lens-collar insert bosses in the front wall |
| `panel` | `panel__mod_s_b1`, `_s_b2`, `_s_r1`, `_s_r2` | the 4 threaded bosses and posts (the policy applied to the panel for the first time in r4; before, the panel was printed at plain 25 %) |
| `base_grip` | `base_grip__mod_s_b1`, `_s_b2`, `_s_j`, `_tripod_nut` | the 3 counterbores and the tripod-nut pocket (8 mm round) |

Import the part STL, then add each modifier as a modifier/part-modifier mesh **without moving it** (same bed frame;
if the slicer auto-centres imports, turn that off or move part and modifiers together). Set the modifier to 40 %
gyroid infill and 4 perimeters. The other 9 parts have no modifier meshes: the hood is a shell at 25 % gyroid like the
tub and panel, the small parts print at 100 % (or as a declared thin part); r5: the lens collar is a small part at
100 %, and its lug insert sits in solid material (audit 2026-10-06 B-10). A
slicer-review record names the part STL and all its modifier files (evidence/README.md).

## 2. Per part

<!-- BEGIN:print -->
| # | Part | Material, colour | Face down | Build X x Y x Z (mm) | Perim. / top-bottom / infill | Supports | Volume (cm3) | Mass at 100 % (g) | Mass as printed (g) | Filament [est] (g) | Time [est] (h) | Basis |
|---|---|---|---|---|---|---|---|---|---|---|---|---|
| 1 | `tub` | ASA, satin silver | -Y | 151.3 x 101 x 70 | 4 / 5 / 25 % gyroid + 40 % modifier meshes x 10 (`stl/modifiers/tub__mod_*.stl`: s_b1, s_b2, s_r1, s_r2, s_k1, s_k2, s_j, s_c1, s_c2, s_c3) | 4 small paint-on supports, each declared in layout.PRINT_SUPPORT_ZONES and checked by print_overhang: under the -Y wings of the 2 keyhole T-tongue heads (each about 7.8 x 1.6, about 17 mm above the bed, the T undercut cannot face the bed) and (r6) under the 2 flat chins: the s_k2 keeper boss (2.9 x 7.3 off the floor wall, 59 mm up) and the LL collar-insert boss (3.3 x 2.4 off the front wall, 59 mm up); nothing else | 106.1 | 113.5 | 96.5 | 101.3 | 4.9 | manifest (out/print-manifest.json) |
| 2 | `hood` | ASA, black | +Z | 171.2 x 67.4 x 99.7 | 4 / 5 / 25 % gyroid | tree supports from the bed at 1 place only (r5: the lens turret is deleted): the +Y lower strip of the eyepiece housing under its window (the window runs the full housing length, so the strip starts mid-air; support from outside, y > 35). Everything else is self-supporting: housing interior = 45 deg flanks + 15.2 mm bridge; J2 groove lip = 21 mm bridges between 6 piers; all holes in the plate are bridged <= 14.2 mm; the lens bore is a truncated teardrop (13.1 mm flat); r5: the 4 collar foot holes (dia 8.6) are teardrops (apex -Z = print up); r7: the camera tab catch (2 tines) hangs from the band and grows straight up. | 57.6 | 61.6 | 52.4 | 55.0 | 2.7 | manifest (out/print-manifest.json) |
| 3 | `panel` | ASA, satin silver | +Y | 148.6 x 94.4 x 65.4 | 4 / 5 / 25 % gyroid + 40 % modifier meshes x 4 (`stl/modifiers/panel__mod_*.stl`: s_b1, s_b2, s_r1, s_r2) | none: every feature grows from the inner face (posts, bosses, tongue teeth, hooks, ribs, keeper, EVF cap); the R5 end corners have a 45 deg facet at the bed; holes are vertical in print. | 51.2 | 54.8 | 46.5 | 48.9 | 2.4 | manifest (out/print-manifest.json) |
| 4 | `base_grip` | ASA, black | +Z | 116.5 x 70.4 x 110 | 4 / 5 / 25 % gyroid + 40 % modifier meshes x 4 (`stl/modifiers/base_grip__mod_*.stl`: s_b1, s_b2, s_j, tripod_nut) | none. Prints upside down (base top on the bed): keyhole lips are the first 1.6 mm, the head pockets bridge 18.5 (x), the nut-pocket ceiling bridges 11.4 round the dia 6.6 hole, the run-button shelf and rear stop bridge 25 between the bay walls, the heel strap slots bridge 13, the dia 13.6 run hole has a 45 deg teardrop roof, the cap grooves have 45 deg faces. | 91.0 | 97.4 | 58.4 | 61.4 | 3.0 | manifest (out/print-manifest.json) |
| 5 | `cap` | ASA, black | -Z | 48 x 30 x 10.2 | 4 / 6 / 100 % | none (key heads 45 deg; detent bumps 0.35 proud, 1.2 tall) | 6.7 | 7.2 | 7.2 | 7.6 | 0.5 | manifest (out/print-manifest.json) |
| 6 | `plunger` | ASA, black | +X | 7.8 x 13.6 x 4 | 4 / 6 / 100 % | none (finger face + flange on the bed, stem and nib rise) | 0.3 | 0.3 | 0.3 | 0.3 | 0.1 | manifest (out/print-manifest.json) |
| 7 | `knob_exp` | ASA, black | +Y | 28 x 28 x 9.1 | 4 / 6 / 100 % | none (top face on the bed, knurl vertical, recess open up) | 4.8 | 5.1 | 5.1 | 5.4 | 0.4 | manifest (out/print-manifest.json) |
| 8 | `knob_fps` | ASA, black | +Y | 20 x 20 x 7 | 4 / 6 / 100 % | none (top face on the bed, knurl vertical, recess open up) | 1.3 | 1.3 | 1.3 | 1.4 | 0.2 | manifest (out/print-manifest.json) |
| 9 | `eyecup` | TPU 95A, black | +X | 45.7 x 45.7 x 16.4 | 3 / 4 / 100 % (TPU 95A, 20-25 mm/s) | none (sleeve end on the bed; 15 deg flare, 45 deg inner lip) | 4.4 | 5.3 | 5.3 | 5.6 | 0.3 | manifest (out/print-manifest.json) |
| 10 | `stick_sleeve` | ASA, satin silver | -X | 13 x 22.9 x 16 | 2 / 4 / 0 % (0.8 walls, declared MIN_WALL exception THIN_OK) | none (end face on the bed, walls vertical) | 1.1 | 1.2 | 1.2 | 1.2 | 0.2 | manifest (out/print-manifest.json) |
| 11 | `pi_keeper` | ASA, black | +Z | 64 x 54.9 x 7.9 | 4 / 6 / 100 % | none | 6.2 | 6.6 | 6.6 | 7.0 | 0.4 | manifest (out/print-manifest.json) |
| 12 | `lens_collar` | ASA (PC if G-W11 shows > 50 C at the camera), black | +X | 66.2 x 68.6 x 11.3 | 4 / 6 / 100 % | none | 16.1 | 17.3 | 17.3 | 18.1 | 1.0 | manifest (out/print-manifest.json) |
| | **total** | | | | | | | **372** | **298** | **313** | **16.0** | |
<!-- END:print -->

"Mass at 100 %" is the solid volume x ASA 1.07 g/cm3 (TPU 1.21). "Mass as printed" applies the layout infill factor
(`layout.INFILL_FACTOR`): shell parts 0.85 (4 perimeters, 25 % gyroid), base + grip 0.6, small parts and TPU 1.0.

### 2b. Bed fit (both printer classes)

<!-- BEGIN:beds -->
| Part | Build X x Y x Z (mm) | 250x210x220 (Prusa MK4/Core One class) | 256x256x256 (Bambu X1/P1 class) |
|---|---|---|---|
| `tub` | 151.3 x 101 x 70 | fits (STL) | fits (STL) |
| `hood` | 171.2 x 67.4 x 99.7 | fits (STL) | fits (STL) |
| `panel` | 148.6 x 94.4 x 65.4 | fits (STL) | fits (STL) |
| `base_grip` | 116.5 x 70.4 x 110 | fits (STL) | fits (STL) |
| `cap` | 48 x 30 x 10.2 | fits (STL) | fits (STL) |
| `plunger` | 7.8 x 13.6 x 4 | fits (STL) | fits (STL) |
| `knob_exp` | 28 x 28 x 9.1 | fits (STL) | fits (STL) |
| `knob_fps` | 20 x 20 x 7 | fits (STL) | fits (STL) |
| `eyecup` | 45.7 x 45.7 x 16.4 | fits (STL) | fits (STL) |
| `stick_sleeve` | 13 x 22.9 x 16 | fits (STL) | fits (STL) |
| `pi_keeper` | 64 x 54.9 x 7.9 | fits (STL) | fits (STL) |
| `lens_collar` | 66.2 x 68.6 x 11.3 | fits (STL) | fits (STL) |
<!-- END:beds -->

The build's `stl + bed fit` check repeats this on the STL bounding boxes; only that check may say "pass".

## 3. Orientation, supports and part notes

**Settled (r6).** The orientation table below is generated from `layout.PRINT_ORIENTATION_WHY` and the last build's
`print_overhang` rows in `checks.json`. A part reads `pass` only when every downward patch in every 0.2 mm layer is
accounted for: a short overhang, an anchored bridge, a bridge that ends at a screw hole, or a declared support zone.
"Around a hole" counts bridges whose lines end at a screw hole: their head bearing faces get the flatness check of
section 5 item 3. The hand-written table after it keeps the per-part detail.

<!-- BEGIN:orientation -->
| Part | Face down | Why this face | Computed (print_overhang) | Bridges: longest span (mm) | Declared supports |
|---|---|---|---|---|---|
| `tub` | -Y | Right wall down: the open left side faces up, so every rib, boss, catch and cell grows from the bed wall or stands at 45 deg; front and rear walls print vertical with their bores as teardrops (apex up). The keyhole T-tongues under the floor are the only undercut (2 paint-on supports). | pass | 19.7 (2 around a hole) | `ll_insert_boss_chin`, `s_k2_boss_chin`, `tongue_f_minus_y_wing`, `tongue_r_minus_y_wing` |
| `hood` | +Z | Roof down: the visible top is the bed face and the band, plate and housing walls rise from it; the housing interior is 45 deg flanks under a bridge and the J2 groove lip bridges between piers. The eyepiece window sill is the only support. | pass | 20.7 | `eyepiece_window_sill` |
| `panel` | +Y | Outer face down: the engraving prints into a smooth bed face and every post, boss, rib, tongue and hook grows upward from it. | pass | - | none |
| `base_grip` | +Z | Base top down (upside down): the keyhole lips are the first layers and the grip column rises from the base; pockets, shelf and strap slots bridge the short way. | pass | 24.7 (1 around a hole) | none |
| `cap` | -Z | Bottom face down: the keys and detent bumps print as vertical faces. | pass | 3.4 | none |
| `plunger` | +X | Finger face down: flat, unmarked finger face; stem and nib rise from the flange. | pass | - | none |
| `knob_exp` | +Y | Top face down: the knurl prints vertical and the D-bore stands upright (round, accurate). | pass | - | none |
| `knob_fps` | +Y | Top face down: the knurl prints vertical and the D-bore stands upright (round, accurate). | pass | - | none |
| `eyecup` | +X | Base ring down: the 15 deg flare and 45 deg lip need no support in TPU. | pass | - | none |
| `stick_sleeve` | -X | End face down: the 0.8 walls print vertical (full height, no bridges). | pass | - | none |
| `pi_keeper` | +Z | Top face down: the fingers grow from it with 45 deg backs; the finger tips stay sharp. | pass | 7.3 (2 around a hole) | none |
| `lens_collar` | +X | Front face down: the bore, cone and hoop lie in the layer plane, so the pinch hoop tension runs along the perimeters and the bore prints round; the ear screw axes are vertical; only the three washer seats face down (bridges with a 0.2 membrane). | pass | 7.2 | none |
| `collar_gauge` | -X | assembly tool: rear end down, both cones widen upward at 45 deg | pass | - | none |
<!-- END:orientation -->

| Part | Face down (on the bed) | Supports | Notes |
|---|---|---|---|
| `tub` | -Y: the right wall (print-up is +Y, toward the open left side) | 4 small paint-on supports: under the -Y wings of the 2 keyhole T-tongue heads (each about 7.8 x 1.6, starting about 17 mm above the bed) and (r6) under the flat chins of the s_k2 keeper boss and the LL collar-insert boss (each about 59 mm above the bed, on the right wall's inner face); nothing else | Every other internal feature grows from the right wall or has its -Y faces at 45 deg or steeper: rib_l gusset, Pi bosses and the 2 keeper bosses (r2: the floor hooks are gone), catch ledges, EVF half-collar, OLED cell, board rails, stick guide. Bridges: window and slot tops <= 20 mm, the dia 7 counterbore shoulders, the cell -Y wall (13.9), the scoop roof (20). The camera lip (dia 32.4) and BFAR counterbore (dia 37.5; r5, they replace the dia 36.5 bore and its 2 pins) and the EVF bore (dia 29.3) are in X-normal walls, so they carry teardrops pointing +Y. r5: the 3 lens-collar insert bosses (OD 8, x -7.6..-5.2) are teardrop prisms with the apex -Y; their 4.0 insert bores run along X, horizontal in this print. 4 perimeters, 25 % gyroid, 40 % modifier round the 2 s_r pads, the 2 keeper bosses s_k1/s_k2 (r2; their pilots are horizontal in this print, the weak case, FASTENER-POLICY B) and (r5) the 3 insert bosses. Brim 5 mm. 70 mm tall as printed |
| `hood` | +Z: the roof (the part prints upside down) | tree, from the bed, 1 place only (r5: the lens turret and its support are gone): the +Y lower strip of the eyepiece housing under its window (support from outside, y > 35) | Housing interior = 45 deg flanks + a 15.2 bridge; the J2 groove lip prints as 21 mm bridges between 6 piers; plate holes are bridged <= 14.2; the lens bore is a truncated teardrop. r5: the 4 collar foot holes (dia 8.6) are teardrops with the apex -Z, each with a full ring >= 1.2 (measured 1.85-2.35); the camera roll fin and its 2 webs grow straight up from the roof. The 4 hooks, rail block and roof rib grow upward. Remove the tree support with flush cutters; deburr the hook teeth and the groove mouth. 5 mm brim on the roof |
| `panel` | +Y: the outer face (engraving on the bed) | none | Engraving 0.4 deep in the bed face, text at least 3.0 high; glyph outlines grow 0.15 per side (`FDM['ENGRAVE_TEXT_GROW']`) so the bold strokes are about 0.9, and the computed `engrave_groove` check passes when no glyph has more than 20 % of its area narrower than 0.6 (`checks.json`). Posts, bosses, tongue, encoder cradle, EVF cap and camera keeper finger all grow upward. Use a smooth PEI sheet for a uniform face; no ironing on the bed face |
| `base_grip` | +Z: the base top (the part prints upside down; the grip column rises 102 mm) | none | The first 1.6 mm are the keyhole lips; the head pocket ceilings bridge 18.5 mm the short way. The tripod-nut pocket opens on the bed. The cap rails are at the top of the column. Brim 5 mm; slow the column above 60 mm if it wobbles. Longest print of the set |
| `pi_keeper` (r2) | +Z: the top face | none | Rigid keeper (finding 1): arm, bridge, port bar and 4 fingers whose backs are 45 deg; 4 perimeters; infill as in the s2 table (small-part class, 100 %; never below 40 % gyroid). The finger tips (1.6) are the critical section: no elephant foot trimming on them |
| `cap` | -Z: its bottom face | none | The 2 keys (web + 45 deg head, ending 1.2 inside the R9 corner) and the detent bumps print as vertical faces |
| `plunger` | +X: the finger face | none | Black ASA from the hood spool (no light pipe: the camera has no LED indicators, user decision 2026-10-05); 100 % infill, no top pattern on the finger face; paint-fill the power symbol white |
| `knob_exp`, `knob_fps` | +Y: the top face | none | Knurl vertical. D bores 6.0/4.5 (exposure) and 6.35/4.8 (18/24) are modelled +0.10 radial over the shaft (`FDM['KNOB_BORE_OFFSET']`); the D-bore ladder coupon (section 6) sets that value before the knobs are printed |
| `eyecup` | +X: the base ring | none (15 deg flare) | TPU 95A, 3 perimeters, 100 %. The sleeve grips the eyepiece eye-end body with 0.3 interference |
| `stick_sleeve` | -X: its end face | none | 0.8 wall, a declared MIN_WALL (1.2) deviation (`layout.THIN_OK`: non-structural slider cover; DESIGN s3): 2 perimeters at 0.4, 4 top/bottom, no infill; check it slides in the guide |
| `lens_collar` (r5) | +X: the front face (one collar per lens) | none | Ring body r 30 round the lens bore, 4 feet, 2 pinch lugs on -Y; r6: ear lobes r 5.6 (1.25 of wall round the counterbores even at the 0.6 bed chamfer). The ears, lugs and feet grow -X; the 45 deg cone that seats the lens band prints as an inward step; a 0.6 bed chamfer runs round the outer edge of the front face, including the bore entry (the centring gauge seats on it: keep it clean, never re-cut it). Downward faces: only the 3 washer-seat bridges (with membranes) and the s_c4 holes. Small-part class, 100 %; ASA black (PC only if G-W11 finds > 50 C at the collar foot). Before printing: section 7 (MP-CAM with G-LENS, then G-COL-1 on the coupons). After printing: set the L 5.7 insert in the lower lug (s4); check the band slides into the bore with s_c4 loose |
| `collar_gauge` (r6 tool) | -X: the rear end (both cones widen upward at 45 deg) | none | Centring gauge for one lens (it matches that collar's bore chamfer), from `stl/tools/collar_gauge.stl`; 100 %, 4 perimeters, about 22 g. Not part of the camera. Print it with the G-COL-1 coupons and check it there first: with the collar coupon held loosely on the tub-front coupon, the gauge must seat on both cones and centre the collar (feeler: equal gap all round the lip). Used at assembly step 7 and for every collar refit (ASSEMBLY s2, s7) |

## 4. Hardware fitted to printed parts

- **Tripod nut** (1/4-20 hex, steel): pressed into the base pocket from the top at assembly step 3 with a flat bar. No
  heat. The 2.3 mm bearing wall under it is part of the base.
- **PT screws** need no preparation: the seven 2.5 mm pilots are printed (4 enclosure + 2 keeper + the s_j base lock; r4: was "six", stale since r2). Do not drill or tap them. The first drive
  forms the thread (FASTENER-POLICY A-C).
- **Heat-set inserts (r5, lens collar only; FASTENER-POLICY I).** 3 short M3 inserts (L 4.0, BOM D2-35) go into the
  3 tub front-wall bosses (TL, TR, LL) from the front, and 1 M3 insert L 5.7 (D2-36) into the collar's lower lug
  from below, with the iron's M3 heat-set tip (D2-74), square to the face, 0.1 below it (ASSEMBLY B1). The printed
  bores are 4.0; do not drill them. Everywhere else the M3 insert is only the fallback for a stripped PT boss
  (FASTENER-POLICY E).

## 5. Post-processing checklist

1. Remove the brims and the hood supports; deburr the seam chamfers. Leave the datum faces untouched: the tub
   front-wall outer face (r5: the lens-collar seat, x -2.7; r4 seated the camera on the inner face x -5.2), the tub
   rear outer face (EVF flange datum F) and the wall tops (hood seat).
2. Check the bores with a gauge or the part itself: r5 camera lip dia 32.4 and counterbore dia 37.5 in the tub front
   wall and the hood plate bore dia 36.5 (the camera must not touch them once it hangs on the lens: lip 0.5 ahead of
   the BFAR face, 0.75-0.825 radial); the 4 hood foot holes dia 8.6 (the collar feet pass with 0.5 radial); EVF bore dia 29.3 (spigot locates, 0.15); plunger hole 11.6 x 6.6
   (the stem slides, 0.3). Ream lightly only if a part binds.
3. Scrape or file the hood J2 groove floor (the bridged lip top) flat and check the panel tongue slides in it (0.4
   under the tongue, 0.25 over it). Seat a PT screw head on each counterbore shoulder (tub s_r1/s_r2 from the right,
   base s_b1/s_b2 from below): it must sit flat, with no sag on the bridged shoulder. Check the sliding joints dry
   before any electronics go in: hood rail groove on the panel tongue; base
   keyhole windows on the tub tongues, then the 10 mm slide (0.25); cap rails and
   detent (0.25); stick sleeve in the guide.
4. Check the snap hooks once by hand (hood hooks hk1-hk4 on the tub ledges): they must click with the hood level. (r2: the Pi floor hooks and gate G-SNAP-1
   are withdrawn; the Pi keeper is screwed, nothing on it flexes.) Strains: `layout.snap_strains()`.
   The hook catch faces are short horizontal overhangs in print (hood 0.65 x 8 with a 1.0 land since the r2 fixer; hk3/hk4
   catch faces are 45 deg; encoder cradle 0.65): clean any droop with a craft knife. Check the 2 dia 1.6 release holes in
   the tub right wall take a 1.5 pin with light friction (the pin must stay in by itself).
5. Paint-fill the panel engraving (assembly step 2): paint pen, then wipe the face with IPA on a flat pad.
   The engraving (from `layout.ENGRAVE`, 0.4 deep in the panel face):

<!-- BEGIN:engrave -->
| id | Kind | Text / shape | Where on the panel face (x, z) | Size | Stroke |
|---|---|---|---|---|---|
| `exp_arc` | arc | arc | centre (-63, 57), r 17.0 | at -100, 100 deg | 0.9 |
| `exp_ticks` | ticks | ticks | centre (-63, 57), r 15.8..18.2 | at -100, 100 deg | 0.9 |
| `exp_arrows` | arrowheads | arrowheads | centre (-63, 57), r 17.0 | at -100, 100 deg (size 2.4 x 1.3) | 0.9 |
| `exp_m` | text | "-" | (-42.1, 48.6) | h 3.4 |  |
| `exp_p` | text | "+" | (-83.9, 48.6) | h 3.4 |  |
| `exp_lbl` | text | "exposure" | (-63, 36.5) | h 3 |  |
| `fps_ticks` | ticks | ticks | centre (-123, 57), r 11.6..14.2 | at -45, 45 deg | 1.2 |
| `fps_18` | text | "18" | (-110.3, 69.7) | h 3 |  |
| `fps_24` | text | "24" | (-135.7, 69.7) | h 3 |  |
| `badge` | text | "GS8" | (-26, 87.3) | h 3.8 |  |
<!-- END:engrave -->

6. (r5; replaces r4's camera-pin fit: the pins are deleted) Set the 4 heat-set inserts (s4; ASSEMBLY B1): 3 short ones
   in the tub front-wall bosses, 1 L 5.7 in the collar's lower lug. r6 (audit B-13): do the collar dry fit on the
   G-COL-1 coupons, not on the production tub with the hood on. That fit would cost one of the hood's counted hook
   cycles, because the hood must come off again for step 4. On the coupons: the 4 feet pass the `collar_hood_plate`
   holes and sit flat on `collar_tub_front`; s_c1..s_c3 reach their inserts by hand; the centring gauge seats on both
   cones.

## 6. Coupons to print first (about 4 h in total; 27 coupon STLs (r5: 23 + 4), see below; generated count: DESIGN.md s1 `counts`)

| Coupon | From | Purpose | Gate |
|---|---|---|---|
| PT boss, 3 per orientation (vertical boss as in the panel posts, horizontal as the bottom bosses) | FASTENER-POLICY C | drive and strip torque, sets T_spec | G-PT-1 |
| Pi keeper (r2; whole keeper since the r2 fixer): tub floor coupon (x -106..-5.3, both keeper bosses, 4 Pi bosses), the whole `pi_keeper`, 2 flat 1.6 stand-in boards assembled on the real X1203 kit | SPEC J9, `coupons_r1.py` | 5 full service cycles (keeper in under the Pi board, s_k1 + s_k2 in and out), finger gaps 0.05-0.3 at all 4 fingers, 20 N lift of the stand-in | **G-KEEP-1** |
| Base edge (r2): base patch at s_b1, tub lip notch patch, panel boss tab | SPEC J3/J5 (r2) | panel open/close 5 times with the PH1 only, strap fitted | **G-PANEL-1** |
| Cap retention (r2): grip bay end with the 2 grooves + detent arm, and the cap | SPEC J6 | 20 slides, detent hold, 20 N pull-down | **G-CAP-1** |
| EVF stop (r2): tub board slot section, panel rib section | SPEC J8 | the real EVF board: feeler 0.1-0.5 at the +Y stop; no shuttle on the HDMI plug | **G-EVF-2** |
| Hood hook hk1 + ledge with its release hole, hook hk3 + sloped ledge (45 deg return; r2 fixer), and one encoder cradle hook on a 1.6 board edge | SPEC J1, J12 | 5 click/release cycles (pin release for hk1, straight pull for hk3), no whitening, no set; then 5 remove/refit cycles of the whole hood | **G-SNAP-2** |
| Lens collar (r5): tub front wall with the lip, counterbore, 3 insert bosses and the LR foot land; hood front plate with the 4 foot holes; the whole collar (default lens); r6: the centring gauge (`stl/tools/collar_gauge.stl`). Set 3 short inserts in the tub coupon and the lug insert in the collar first. **Only after G-COMB-1, MP-CAM (G-CAM-1) and G-LENS (section 7)** | SPEC J7 (r5), FASTENER-POLICY I | feet pass the holes (>= 0.3); r6: the gauge seats on both cones and centres the collar (equal feeler gap round the lip, within 0.1); the band slides in with s_c4 loose; at 0.15 / 0.2 N m (torque driver) no slip under 1.0 N m roll or 50 N axial; 3x lens mass at the CoM: dial at the lens front <= 0.02, returns; 24 h at 50 C, re-torque check; 20 pinch cycles, no lug crack | **G-COL-1** |
| Keyhole tongue + base slot (one tongue, 20 mm of base) | SPEC J4 | drop in, slide 10 mm, no rock; keyhole fit | **G-J4-1** (fit record, s6.1) |
| Knob D-bore ladder, 5 steps of `KNOB_BORE_OFFSET` -0.05..+0.15 radial, both shafts | SPEC J12 | push fit on the encoder and switch shafts | **G-KNOB-1** (calibration record, s6.1); then set `FDM['KNOB_BORE_OFFSET']`, rebuild, print the knobs |
| Clearance comb 0.15 / 0.25 / 0.30 | layout FDM | confirms LOCATE / SLIDE / SEAM on this printer and profile | **G-COMB-1** (calibration record, s6.1); profile tuning |

The coupons are modelled (`make_coupons.py`, FIXER P-P11): each is the exact intersection of the built part with a box
round one feature, posed as its parent part prints, in `out/stl/coupons/` with `out/coupons-manifest.json` (r5: 23 STLs from `make_coupons.py`, about 83 g of ASA at 100 % incl. the 3 G-COL-1 coupons of 31 g; r2 fixer to r4: 20, about 52 g; plus
4 from `coupons_r1.py` with `out/coupons-r1-manifest.json`):

| STL | Qty | Cut from | Gate |
|---|---|---|---|
| `pt_boss_post` | 3 | panel post_f (pilot along print-up) | G-PT-1 |
| `pt_boss_bottom` | 3 | panel boss_b1 + wall patch (pilot horizontal) | G-PT-1 |
| `board_edge_plate` | 2 | 1.6 plate (encoder cradle hook test) | G-SNAP-2 |
| `coupon-pi-keeper-tub`, `-part`, `-x1203`, `-pi` | 1 + 1 + 1 + 1 | tub floor x -106..-5.3 (s_k1 + s_k2 bosses, 4 Pi bosses, lip gusset); the whole keeper; 2 flat 1.6 stand-in boards (mount on the real X1203 kit) | G-KEEP-1 |
| `hood_hook_ret`, `hood_ledge_ret` | 1 + 1 | hood hk3 (45 deg return) + band patch; tub front-wall sloped ledge | G-SNAP-2 |
| `base_edge_base`, `base_edge_tub`, `base_edge_panel` | 1 + 1 + 1 | base at s_b1; tub lip notch; panel boss tab | G-PANEL-1 (+ G-PT-1) |
| `cap_retention_grip`, `cap_retention_cap` | 1 + 1 | grip bay end (grooves, detent arm); the cap | G-CAP-1 |
| `evf_stop_tub`, `evf_stop_panel` | 1 + 1 | tub board slot (67 tall as printed); panel stop rib + EVF cap | G-EVF-2, G-EVF-1 |
| `hood_hook` + `hood_ledge` | 1 + 1 | hood hk1 + band patch; tub hk1 ledge + wall patch | G-SNAP-2 |
| `encoder_cradle_hook` | 1 | panel top cradle hook (test on the 1.6 plate) | G-SNAP-2 |
| `tongue` + `keyhole_slot` | 1 + 1 | tub tongue_f (20 mm, with its paint-on support) + base window/pocket | G-J4-1 |
| `knob_bore_ladder_enc`, `knob_bore_ladder_sw` | 1 + 1 | D bores at -0.05..+0.15 radial (1-5 rim notches) | G-KNOB-1 (sets `KNOB_BORE_OFFSET`) |
| `clearance_comb` | 1 | pegs + holes at 0.15 / 0.25 / 0.30 per side | G-COMB-1 (profile tuning) |
| `collar_tub_front`, `collar_hood_plate`, `collar_part` (r5) | 1 + 1 + 1 | tub front wall x -8.2..-2.6 (lip, counterbore, TL / TR / LL insert bosses, LR foot land; 7.6 g); hood front plate (bore, 4 foot holes; 6.6 g); the whole Kowa collar (17.0 g) | G-COL-1 |

### 6.1 Calibration and fit records (r3, audit 2026-10-05 correction 1B)

Three coupon groups (`knob_bore_ladder_enc` + `knob_bore_ladder_sw`, `clearance_comb`, `tongue` + `keyhole_slot`) had no record id before r3; each group now has its own id (the ids `build_d2.py` `CALIBRATION_ITEMS` requires as
`coupon_validation` items), and its result is filed like every other coupon gate:

| Record id | Coupon STLs | What is recorded | Pass |
|---|---|---|---|
| **G-KNOB-1** | `knob_bore_ladder_enc`, `knob_bore_ladder_sw` | which rim-notch step (1-5) pushes onto the real encoder and the real 18/24 shaft without play, per shaft | one step fits both shafts (or one per shaft); the chosen offset goes into `FDM['KNOB_BORE_OFFSET']`, then the knobs are rebuilt and their new STL hashes recorded |
| **G-COMB-1** | `clearance_comb` | which pegs enter / slide / bind at 0.15 / 0.25 / 0.30 per side | 0.15 locates, 0.25 slides, 0.30 is free (LOCATE / SLIDE / SEAM of `layout.FDM`) on this printer, material and profile |
| **G-J4-1** | `tongue`, `keyhole_slot` | the J4 tongue drops into the keyhole window, slides 10 mm and does not rock or lift | drop in, full 10 mm slide, no rock |

How to file one: write one structured evidence record per tested item as `evidence/README.md` describes (written by
the checks role; use its template): `item` = the record id above (never a file name), `state` = `coupon_validation`,
`artifacts` = {path: sha256} of every coupon STL of that record actually printed (hash the file you sliced), `profile` = printer,
material, slicer profile or variant, `verdict` = pass or fail, `date`, `by`, `notes`. A record counts only for its
item id and the hashes it lists: a record for an older STL (different hash) is stale, and a failed record stays
visible until a newer passing record for the current hashes is filed. Nothing has been printed or recorded on this
machine; all three are **not run**.

## 7. Print order (settled, r6; audit 2026-10-06 M2)

The order is a rule, not a suggestion. Print a part only after **every gate listed for it** has a current recorded
pass (evidence/README.md). The table is generated from `layout.PRINT_PREREQS`, `COUPON_PREREQS` and
`PRINT_SEQUENCE`, and its "Now" column comes from the last build receipt's `print_release`.
- The build enforces the rule. A `slicer_review` record for a part, or a G-COL-1 coupon record, is **rejected** if it
  was filed before those gates passed or is dated before them. The part's evidence then stays open.
- **Any measured difference** at order 2 means: update `layout.py`, rebuild and rerun the release sequence (HANDOFF),
  then slice the new STL. A record for an older STL is stale by hash anyway.
- The collar is per lens. A `--lens` build exports that lens's collar and its own centring gauge.

Within a stage, the sequence follows the old advice:
- `base_grip` first: it is the longest print, and its pack bay and keyholes can be checked against the pack and the
  tongue coupon.
- Then `tub` and `hood`: check the hood on the tub at once (hooks, plate gap 0.2, wall-top seat).
- `panel` face down on a clean sheet.
- One plate of the small parts.
- The collar after G-COL-1.
- The TPU `eyecup` last (change the material and the profile).

<!-- BEGIN:order -->
| Order | What | Print only after a current recorded pass of | Now |
|---|---|---|---|
| 1 | Calibration and fit coupons (s6, all except the 3 G-COL-1 coupons) | nothing: print them first, in parallel with the bench measurements | released |
| 2 | Bench measurements, no printing (ASSEMBLY B0, MEASURED-PARTS): MP-CAM with the lens (G-CAM-1, G-LENS), MP-PACK, MP-RUN, MP-X1203, MP-HDMI, MP-EVF, MP-ENC, MP-SW, MP-STICK, MP-FPC | update `layout.py` with any measured difference, rebuild and rerun the release sequence before order 3 | - |
| 3 | G-COL-1 coupons (`collar_tub_front`, `collar_hood_plate`, `collar_part`) and the centring gauge (`stl/tools/collar_gauge.stl`) | G-COMB-1, G-CAM-1, G-LENS | blocked (3 of 3 open) |
| 4 | `base_grip` | G-COMB-1, G-MP-PACK, G-RUN-1 | blocked (3 of 3 open) |
| 5 | `tub` | G-COMB-1, G-PI-1, G-MP-X1203, G-CAM-1, G-LENS, G-HDMI, EVF-G1, EVF-G7, EVF-G8, G-MP-EVF, G-MP-STICK, G-MP-FPC | blocked (12 of 12 open) |
| 6 | `hood` | G-COMB-1, G-MP-X1203, G-CAM-1, G-LENS, EVF-G1, EVF-G7, EVF-G8, G-MP-EVF, G-MP-FPC | blocked (9 of 9 open) |
| 7 | `panel` | G-COMB-1, G-CAM-1, G-LENS, G-HDMI, EVF-G1, EVF-G7, EVF-G8, G-MP-EVF, G-ENC-1, G-MP-ENC, G-MP-SW | blocked (11 of 11 open) |
| 8 | `pi_keeper` | G-COMB-1, G-PI-1, G-MP-X1203 | blocked (3 of 3 open) |
| 9 | `cap` | G-COMB-1, G-MP-PACK | blocked (2 of 2 open) |
| 10 | `plunger` | G-COMB-1 | blocked (1 of 1 open) |
| 11 | `knob_exp` | G-COMB-1, G-MP-ENC, G-KNOB-1 | blocked (3 of 3 open) |
| 12 | `knob_fps` | G-COMB-1, G-MP-SW, G-KNOB-1 | blocked (3 of 3 open) |
| 13 | `stick_sleeve` | G-COMB-1, G-MP-STICK | blocked (2 of 2 open) |
| 14 | `lens_collar` | G-COMB-1, G-CAM-1, G-LENS, G-COL-1 | blocked (4 of 4 open) |
| 15 | `eyecup` | G-MP-EVF | blocked (1 of 1 open) |

| Gate | What it fixes before printing |
|---|---|
| EVF-G1 | EVF board revision (5 V lead end) |
| EVF-G7 | EVF panel release (EVF-A usable at all) |
| EVF-G8 | OLED flex length |
| G-CAM-1 | MP-CAM: camera stack, back focus s, tripod-block removal (tub lip and counterbore, hood tab catch (lock-screw head side, head dia/height, tip protrusion, tab width/top), panel keeper, collar C-flange datum) |
| G-COL-1 | collar coupons: fit, centring gauge, pinch, slip, pull-out and creep |
| G-COMB-1 | LOCATE / SLIDE / SEAM confirmed on this printer and ASA profile (clearance comb) |
| G-ENC-1 | encoder back parts against the cradle hooks |
| G-HDMI | micro-HDMI plugs and the 18/24 switch bushing (EVF board slot, panel) |
| G-KNOB-1 | KNOB_BORE_OFFSET chosen on the D-bore ladders, then the knobs rebuilt |
| G-LENS | MP-CAM lens line: band OD, edge, position, rings and CoM (collar bore and cone; lens rows of j7_float) |
| G-MP-ENC | encoder board, bushing and shaft |
| G-MP-EVF | EVF bench assembly: optics, board stop, eyecup barrel |
| G-MP-FPC | camera FPC length and fold (tub and hood keep-outs) |
| G-MP-PACK | pack envelope and lead exit (grip bay, cap) |
| G-MP-STICK | stick width and thickness (guide, sleeve) |
| G-MP-SW | 18/24 switch tab, nut and shaft |
| G-MP-X1203 | X1203 board and Active Cooler height (Pi bosses, keeper, hood and FPC clearances) |
| G-PI-1 | X1203 edge parts and standoffs (keeper fingers, Pi bosses) |
| G-RUN-1 | run button and cap (grip cradle and hole) |
<!-- END:order -->

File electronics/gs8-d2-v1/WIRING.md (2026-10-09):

# GS8 D2 release v1: wiring guide (`electronics/gs8-d2-v1`)

Written 2026-10-04 by the docs owner of the D2 release layer. Geometry, cable ids, lengths and keep-outs come from
`cad/gs8-d2-v1/layout.py` (`CABLES`, `KEEPOUTS`, `COTS`, `STEPS`); the cable table in section 5 is generated from it by
`cad/gs8-d2-v1/make_tables.py`. Component facts come from `concepts/nizo-evf-2026-10-03/research/PALETTE.md` and
`electronics/gs8-evf-v1/EVF-SELECTION.md`. **Nothing here is bought, built or measured.** Every electrical number is a
datasheet, listing or planning figure, and every bench gate in section 9 is open.

**Status (r4, 2026-10-05 evening; r3 text kept).** r4 added the W-10 pigtail fuse, the pack protection requirement
R-PACK-BMS, concrete regulator candidates for option C (s4.8), a defined off-rail G-W13 (e), and the CAD `cable_routes`
check (route continuity, end reach and length; bend radius still a bench item). Done on this machine: CAD geometry and computed checks (`cad/gs8-d2-v1`), these documents,
the generated BOM, the planning calculations of section 4 and a box-arithmetic placement check (s4.8). **Not done:**
procurement (nothing ordered or received), printing or slicing, any measurement, any soldering or harness build, any
power-up, and every bench gate of section 9 (G-W1 to G-W13, EVF-G1 to EVF-G9). No electrical performance, fit or
service life is claimed from CAD or from these calculations.

D2 is much simpler than the release v1 harness: there is no PROTO1 board, no buck converter, no fuse block, no
MCP23017 and no INA260. Power comes from a Geekworm X1203 UPS board under the Pi (pogo pins onto the header tails),
fed from a 1S2P 18650 pack in the grip over one XT30 junction. The four controls use 3 GPIO pins, I2C and the Pi's own
power button.

## 1. Files

| File | What |
|---|---|
| `WIRING.md` | this guide |
| `make_bom.py` | writes `BOM.md` and `bom.csv` from `layout.py` + `outputs/bom-release-2026-09-25/prices.json` |
| `BOM.md`, `bom.csv` | purchased lines, printed parts, fasteners, consumables, tools (generated) |
| `../../cad/gs8-d2-v1/make_tables.py` | refreshes the generated blocks in this file (header, cables, plug order), PRINT-GUIDE.md, ASSEMBLY.md and DESIGN.md, and writes the 3 files below |
| `harness-schedule.csv` | every cable: class, both ends, length, plug steps, keep-out chain, routing note (generated) |
| `pi5-header.csv` | the Pi 5 J8 pins D2 uses (generated) |
| `wiring-d2.svg` | block diagram of the harness (generated) |

## 2. Block diagram

```
 1S2P 18650 pack (BMS)            GRIP                                   BODY
 [cell][cell]--BMS--pack lead 18 AWG--XT30 M | XT30 F--[15 A fuse]--pigtail 18 AWG, cut 200 mm + pads-to-W (G-W2)--+
                                                                               | solder, 2 joints
                                                         Geekworm X1203 battery pads (XH socket left empty)
                                                         X1203 boost 5.1 V 5 A  (fuel gauge I2C 0x36)
                                                               | pogo pins onto the header tails (5 V, GND, SDA/SCL, ...)
   Pi 5 power button <-- printed plunger                 Raspberry Pi 5 (EEPROM PSU_MAX_CURRENT=5000)
                                                               |-- CAM/DISP 1 --FPC 22-15 200 mm--> GS camera
                                                               |-- HDMI0 --micro-HDMI 200 mm (90 deg)--> EVF board --flex--> HMX039 OLED
                                                               |-- USB 2 upper --USB-A 5 V lead + 1N5817--> EVF board EXT+
                                                               |      (r3 candidate C: a 4.55 V LDO in place of the diode, s4.8)
                                                               |-- USB 3 lower <== SanDisk SDCZ880 stick (rear scoop)
                                                               |-- FAN <-- Active Cooler lead
                                                               |-- pins 1/3/5/6 <--QT 250 mm-- Adafruit 5880 encoder (0x37)
                                                               |-- pins 33/34 <--Dupont-- 18/24 rotary
                                                               '-- pins 37/39 <--pre-wired lead-- run button (grip)
```

## 3. Decisions made in this layer

| # | Decision | Why |
|---|---|---|
| W-1 | The pigtail is **soldered to the X1203 battery pads**; the board's XH2.54 battery socket stays empty. | An XH2.54 contact is a ~3 A class part. Near cut-off the pack delivers about 8.5 A (section 4). The pad position on the board is open (layout `COTS['x1203']` "pads: position open (Q2)"). r7 (BX-3): strain relief is a neutral-cure silicone RTV bead at the pads (not acetoxy). No tie to a standoff. |
| W-2 | **18 AWG silicone** for the pigtail and the pack lead; **XT30U** at the grip junction. | 8.5 A planning peak; XT30 is a 15 A continuous class connector. The voltage drop is in section 4. |
| W-3 | **A 1N5817 Schottky in series with the + conductor of the EVF 5 V lead.** | The EVF board needs 4.25-4.90 V at its terminals (EVF-SELECTION s5, vendor range 3.5-5.0 V). A Pi USB port sits at about 5.0-5.1 V. 0.35-0.45 V of diode drop at 0.3 A gives about 4.6-4.7 V. The diode also blocks backfeed from the board into the Pi's USB rail. Confirmed only by bench gate G-W6. **r3:** a diode has no guaranteed minimum drop, so this feed cannot be shown to stay <= 4.90 V on paper and G-W6 is expected to fail; the recommended candidate (s4.8, option C, user decision) replaces the diode by a 4.55 V LDO. |
| W-4 | **The EVF lead has a JST PH 2-pin wire-to-wire junction at the board end.** | The board slides into its slot at step 6 after the lead is plugged into the Pi at step 4. A Rev I board gets a 2-wire PH pigtail soldered to its traced EXT+/GND pads (EVF-SELECTION s5). Never mate it live. r7 (BX-9): the junction is mated with the pair held about 60 mm out of the open left side, then tucked into `ko_5v_end` with tweezers once the board is home (s7 notes). |
| W-5 | **The run button is active low on GPIO26** with the internal pull-up; **18/24 is GPIO13**, low = 24 fps, high (open) = 18 fps. | 0 parts; a lead that falls off reads as 18 fps, the safe default. |
| W-6 | **The power button is the Pi 5's own button**, pressed by the printed plunger. logind ignores it; a daemon shuts down only after a **2 s hold**. | A brush of the left hand cannot stop a take (concept E-F2). |
| W-7 | **The pack is charged out of the body** on a 1S Li-ion charger with an XT30 lead. | The X1203's own USB-C input is inside the closed body under the Pi. In-body charging is not provided in D2. |
| W-8 | **No added I2C pull-ups, no level shifting.** | The Pi 5 has 1.8 k pull-ups on GPIO2/3 and the 5880 runs from 3V3 (pin 1). The X1203 gauge shares the bus through the pogo pins; its bus level and any on-board pull-ups are checked at G-W2. |
| W-9 | **Operating restrictions R-P1 to R-P8 (r2)**: 2 USB loads only, no overclock, `arm_freq=1800` if G-W12 allows, radios off, nothing on Ethernet/HDMI1/PCIe, default fan curve, no extra header loads, software low-cell shutdown. | They are intended to reduce the 5.1 V load. With them the load is **estimated** at 17.7-22.1 W (r2 fixer: S3 board 11-12.5 W [est] + HDMI +5 V 0.26 W), within 0.8-5.2 W of the G-W12 P1 limit (22.9 W). **r3: that estimate is not a demonstrated supply margin**: nothing is measured, the restrictions are not shown to hold the load anywhere, and the 27 W planning peak stays above the X1203's 25.5 W and is not served (section 4.1-4.4). G-W12 stays open until measured. |
| W-10 | **r4: a 15 A inline fuse (Littelfuse 0251015.MXL, PICO II, very fast) in the + conductor of the pigtail, within about 25 mm of the XT30 female**, sleeved in adhesive 3:1 heat-shrink and lying along X under the XT30 pair (in `ko_xt30`; modelled in the `xt30_pair` proxy, so the pack-insertion sweep and the interference checks see it). | Before r4 the only protection between 2 high-drain cells and the 18 AWG pigtail was the pack BMS, which was not even specified; a BMS whose MOSFETs fail shorted leaves about 120-200 A [est] into the pigtail. The fuse is a second, independent layer for the pigtail and the X1203 input (not for the 60 mm pack lead and the XT30, which stay on the BMS). Sizing (251 datasheet rev VL: 25 % standard derating plus the temperature curve): 15 A x 0.75 x 0.985 = 11.1 A allowed at 40 C, so 8.6 A is 78 %; the 12 A part keeps only 1-3 % and is rejected. Cold 4.46 mohm: about 0.04 V and 0.33-0.35 W at 8.6 A. Melting I2t 68.8 A2s against an estimated <= 0.35 A2s plug-in surge (X1203 input capacitance unpublished; 100-1000 uF bracket). Interrupting 300 A at 32 VDC against an estimated 120-200 A fault. +1 part, +2 solder joints; confirmed only by G-W5 (drop, temperature) and G-W1 (plug-in). |
| W-QT | **r7 (BX-2): the QT lead is 250 mm (240-270), spliced from an Adafruit 4397 (sockets, D2-24) and a Pololu 5521 (JST-SH, D2-24B).** Map continuity first (4397: SH pin 1 GND black, 2 3V3 red, 3 SDA blue, 4 SCL yellow; Pololu 5521: black is pin 1, the other three by meter). Join by SH pin number, never by colour alone. Joints 91-115 mm from the socket tip, 8 mm apart, one thin-wall sleeve each, one adhesive 3:1 sleeve about 35 mm over all; no joint or sleeve outside 85-121 mm (r7 fix-up, VERIFY-C2: the wall-to-cross corner is at about 82-84 mm from the socket tip and the rise into ko_qt_tail at about 129 mm, so the old 77-113 window put the sleeve end on the corner; the G-QT-1 dry-fit is the gate). Finished length 250 +/- 10, socket tip to SH plug face. | The 150 mm lead let the panel stand only about 15-20 mm off while the encoder was plugged (BX-2). At 250 mm the plug is made with the panel 60 mm off: computed `mate_reach` row qt_enc, slack 35.2 mm at the 240 mm minimum after a 24 mm margin. The spare folds into `ko_lead_stow` (`cable_stow`). The joints sit in the straight run of `ko_lead_cross` (y -29..17), not in a corner. 250 mm is inside Adafruit's own 300 mm warning for QT leads; the bus is checked at G-HDR-1 and G-W9. A one-piece 240-270 mm lead of the same ends may replace the splice (buy-check MP-QT; no vendor confirmed). +4 solder joints. |

## 4. Power path

| Segment | Part | Rating / planning figure | Source |
|---|---|---|---|
| Cells | 2 x 18650 in parallel (1S2P), high-drain class (>= 10 A continuous per cell, e.g. Molicel P28A or Samsung 35E class) | 4.2 V full, 3.6 V nominal, 3.0 V cut-off; 2 x 3.5 Ah x 3.6 V = 25.2 Wh (35E class) | PALETTE s5a |
| BMS | in the pack | must pass >= 10 A continuous; UVP 2.5-3.0 V | estimate |
| Pack lead | 18 AWG silicone, 60 mm, XT30U male | | layout `CABLES['pack_lead']` |
| Junction | XT30U pair in the grip (male on the pack, female on the pigtail) | 15 A continuous class | listing class |
| Fuse (r4, W-10) | Littelfuse 0251015.MXL in the pigtail + conductor, about 20-25 mm from the XT30 female | 15 A very fast; 11.1 A allowed at 40 C after derating; 4.46 mohm cold; I2t 68.8 A2s; 300 A at 32 VDC | 251 datasheet rev VL 09/26/24 |
| Pigtail | 18 AWG silicone, r7: cut length 200 mm + d_board (G-W2; 200-225 mm: d_board over 25 mm stops step 1, G-W5 drop), XT30U female, soldered to the X1203 battery pads; RTV strain relief at the pads | | layout `CABLES['pigtail']`, `PIGTAIL` |
| UPS | Geekworm X1203: 1S input, boost to 5.1 V, 5 A max out | 5.1 V +-5 %, 5 A | PALETTE s5a (listing) |
| Pi feed | pogo pins onto the 5 V / GND header tails | no USB-PD; hence `PSU_MAX_CURRENT=5000` | PALETTE s5 |
| USB budget | stick (USB 3, lower port) + EVF lead (USB 2, upper port) | 1.6 A total with a 5 A supply declared | Pi 5 whitepaper RP-009856 via PALETTE |

### 4.1 Planning peak against the X1203 ceiling (audit finding 4, r2)

**Planning load** (PALETTE s0/s5, not measured): 18 W record, **27 W peak** on the 5.1 V side. The X1203 is rated
5.1 V x 5 A = **25.5 W**. 27 W is 5.29 A at 5.1 V: **1.5 W (6 %) above the rating.** If the camera really drew 27 W,
the X1203 would not serve it: it would current-limit and the rail would sag (Pi undervoltage, USB resets, a brownout).
Calling the output "capped" does not make a 27 W demand pass. The 27 W figure stays as the inherited planning peak (the
30.5 W EVF-branch allowance of `electronics/gs8-gnb3s-v1/power-budget.json`, minus the dropped microphone, expander,
INA260 and latch). It is an allowance, not an itemised load.

**The 27 W planning peak stays in force against the 25.5 W ceiling.** The estimated envelope of 4.2-4.4 below, with the
operating restrictions of 4.3, is a planning estimate of what D2 may draw; **it is not a demonstrated supply margin**
(r3, audit 2026-10-05 finding 4) and it does not replace the 27 W figure. Gate G-W12 (section 9) stays open until it is
measured on the real stack and loads. If G-W12 fails, the power arrangement of 4.5 (another design, not a verified
drop-in) replaces the X1203.

### 4.2 Workload states and estimated loads at 5.1 V

Sources: [pub] = published third-party bench figures for a bare Pi 5, read 2026-10-05 (r2) from search summaries,
not re-measured: Jeff Geerling 2024, "New 2GB Pi 5 has 33 % smaller die"
(https://www.jeffgeerling.com/blog/2024/new-2gb-pi-5-has-33-smaller-die-30-idle-power-savings/): idle 3.2-3.3 W and
`stress-ng` all cores 9.8 W (4/8 GB); raspberry.tips 2026 "Raspberry Pi Power Consumption"
(https://raspberry.tips/en/faq/raspberry-pi-power-consumption-update-2026-all-models-compared): Active Cooler fan
about 0.5 W, "CPU + USB SSD + 4K video" about 16 W. These are other people's
units, not this one. [rec] = repo record. [spec] = interface specification. [est] = my estimate, with its basis.

| Load | S0 idle | S1 live view | S2 record | S3 write burst | S4 startup | Basis |
|---|---|---|---|---|---|---|
| Pi 5 board (SoC, RAM, RP1, PMIC) | 3.3 | 4.5 | 6.0 | 12.5 | 7.0 | idle [pub]; S1, S2, S4 [est]: ISP + KMS for S1, 47.5-76 MB/s RAW copy + filesystem for S2, all cores during boot for S4. **S3 (r2 fixer): `stress-ng` all cores alone is 9.8 W [pub]; S3 adds the ISP/KMS/RAW pipeline on top, +1.2-2.7 W [est: the S1/S2 board figures minus idle], so 11.0-12.5 W; 12.5 is used.** (r2 R4 had 8.0, below the published CPU-only figure.) The raspberry.tips "CPU + USB SSD + 4K video" 16 W total implies a board near 11-13 W, consistent |
| HDMI +5 V (pin 19 to the EVF board) | 0.26 | 0.26 | 0.26 | 0.26 | 0.26 | the G-W7 limit, 50 mA x 5.1 V [rec: EVF-SELECTION G5 expects <= about 30 mA]; r2 fixer: was in no table |
| GS camera (IMX296, from the Pi 3V3) | 0.05 | 0.4 | 0.4 | 0.4 | 0.2 | [est] small sensor module, not published |
| Active Cooler fan | 0.2 | 0.3 | 0.5 | 0.5 | 0.5 | full speed about 0.5 W [pub]; the curve sets the rest [est] |
| EVF board + panel (USB 2 port, through the 1N5817) | 0.8 | 1.3 | 1.3 | 1.55 | 1.55 | <= 0.30 A at the board (EVF-G4 [rec]) = 1.55 W at 5.1 V; menu/live split [est] |
| SDCZ880 stick (USB 3 port) | 0.3 | 0.3 | 2.5 | 4.6 | 2.5 | 4.6 W = the USB 3 device maximum of 900 mA [spec]; idle and sustained write [est] |
| Encoder, X1203 gauge (header 3V3) | 0.1 | 0.1 | 0.1 | 0.1 | 0.1 | [est] seesaw MCU about 20 mA |
| **Total (W)** | **5.0** | **7.2** | **11.1** | **19.9** | **12.1** | sum (r2 fixer; R4 had 4.8 / 6.9 / 10.8 / 15.2 / 11.9) |
| **Current at 5.1 V (A)** | 0.98 | 1.41 | 2.17 | 3.90 | 2.37 | P / 5.1 |

State definitions (G-W12 uses the same ones):
- **S0 idle**: booted to the camera service, EVF on a static menu, sensor not streaming, stick mounted, no writes.
- **S1 live view**: sensor streaming 1456 x 1088 at 24 fps to the EVF (1024 x 768), no writes.
- **S2 record**: S1 + RAW 24 fps written to the stick (10-bit packed 47.5 MB/s; also the 16-bit container 76 MB/s),
  encoder polled, fan on its curve, steady temperature (10 min).
- **S3 write burst**: S2 on a stick filled to >= 50 % and written past its cache, plus 60 s of `stress-ng --cpu 4`
  (the runaway-software case) and the fan forced to full speed.
- **S4 startup**: from pack connection to recording-ready: X1203 start, boot, stick enumeration, camera probe, EVF
  hotplug. The first 30 s.

The S2 estimate (11.1 W) is below the 18 W planning record figure. PALETTE s5 already expected 10-15 W. The runtimes
and cell currents below keep the 18 W planning figure until G-W12 measures S2.

### 4.3 Operating restrictions (part of the D2 configuration, section 8)

| # | Restriction | Expected effect |
|---|---|---|
| R-P1 | **USB budget**: exactly 2 USB loads: the stick (lower USB 3) and the EVF lead (upper USB 2). The other 2 ports stay empty (they are inside the closed body). `PSU_MAX_CURRENT=5000` gives the Pi's 1.6 A total USB limit. Never add `usb_max_current_enable` tricks or a USB hub | USB side <= 1.6 A x 5.1 V = **8.2 W, the Pi's own USB current limit** (Pi 5 whitepaper RP-009856 via PALETTE s5; its trip behaviour is not measured here); <= 6.15 W by the 2 device maxima (stick 4.6 + EVF 1.55) |
| R-P2 | **No overclock**: no `over_voltage`, no `arm_freq` above 2400, no `force_turbo`; default `ondemand` governor | keeps the board inside the published 9.8 W all-core class |
| R-P3 | **CPU cap `arm_freq=1800`** (25 % below the 2.4 GHz default), kept only if G-W12 shows 0 dropped frames in S2 and S3 at 24 fps | CPU part of the board maximum about 9.8 -> 7.5 W [est: dynamic CPU power scales with f x V^2; idle unchanged], so the S3 board 12.5 -> 10.2 W [est]. **Recommended (r2 fixer)**: without it the estimated worst case (22.1 W, 4.4) is only 0.8 W under the G-W12 P1 limit; with it 3.1 W. Kept only if G-W12 shows 0 dropped frames |
| R-P4 | **Radios off in the camera image**: `dtoverlay=disable-wifi`, `dtoverlay=disable-bt`. Footage leaves on the stick. A bench/maintenance image may enable Wi-Fi, never while recording | removes a 0.3-1 W [est] transmit load that the table does not carry |
| R-P5 | **Nothing on Ethernet, HDMI1 or PCIe**; `dtparam=pciex1` stays off; no M.2 HAT (it also clashes with the cooler) | removes 1-2 W [pub, NVMe class] of possible additions |
| R-P6 | **Fan curve: firmware default, not capped** | 0 W change. Its 0.5 W maximum is already in the table; a capped fan would trade power for throttling (G-W11) |
| R-P7 | **No other loads on header 5 V** (pins 2/4 are the feed); 3V3 carries only the encoder | keeps the header load at the table's 0.1 W |
| R-P8 | **Software low-cell shutdown** at 3.3 V under load (gauge 0x36; G-W5 sets the value) | limits the battery current at end of discharge (4.7) |

### 4.4 Estimated envelope against the ceiling (r2 fixer: an estimate, not a bound)

| Case | Pi board | Camera | Fan | USB (stick + EVF) | Header 3V3 | HDMI +5 V | Total | vs 25.5 W | to P1 (22.9 W) |
|---|---|---|---|---|---|---|---|---|---|
| Expected burst (S3 estimate, no CPU cap, USB at the 2 device maxima) | 12.5 | 0.4 | 0.5 | 6.15 | 0.1 | 0.26 | 19.9 W (3.90 A) | 78 % | 3.0 W |
| R-P1..R-P8 with the CPU cap, USB at the 2 device maxima | 10.2 | 0.5 | 0.5 | 6.15 | 0.1 | 0.26 | 17.7 W (3.47 A) | 69 % | 5.2 W |
| CPU cap, USB at the Pi's hardware limit (1.6 A) | 10.2 | 0.5 | 0.5 | 8.2 | 0.1 | 0.26 | 19.8 W (3.88 A) | 78 % | 3.1 W |
| **No** CPU cap, USB at the hardware limit | 11.0-12.5 | 0.5 | 0.5 | 8.2 | 0.1 | 0.26 | **20.6-22.1 W (4.03-4.33 A)** | 81-87 % | **0.8-2.3 W** |
| Planning peak (kept) | | | | | | | **27 W (5.29 A)** | **106 %: not served** | |

On these estimates (none measured; **not a demonstrated margin**) the envelope would sit below the X1203 rating
(25.5 W), but **not by much**: without the CPU cap and
with the USB side at its hardware limit, the estimated worst case is 0.8-2.3 W under the G-W12 P1 limit (22.9 W, 100 ms
peak). r2 R4's "at least 6.4 W (25 %) in hand" used an S3 board figure (8.0 W) below the published CPU-only maximum and
had no HDMI +5 V row; it is withdrawn. The envelope rests on figures that are not D2 measurements: the published
9.8 W CPU figure, an estimated pipeline increment and the Pi's own USB current limit. G-W12 measures the real
envelope. The X1203 may also derate at a low cell voltage (a boost draws its
highest input current there); G-W12 therefore runs every state at 3.30 V input.

### 4.5 Fallback arrangement with headroom (option b; not applied)

Use it only if G-W12 fails P1 or P2 (load or rail) at any input voltage, or P4 (X1203 temperature) at the measured load.

| Candidate | Rating | D2 geometry and parts impact | Verdict |
|---|---|---|---|
| Geekworm X1206 V2.0 (PALETTE 5a) | 5.1 V 6 A (30.6 W) | 108 x 85 board with 4 x 21700: wider than the tub (inner width 65), so a new body | rejected for D2 |
| Waveshare UPS HAT (E) (PALETTE 5a) | 5 V 6 A | 4 x 21700 in series do not fit the grip bay (38 x 20 x 72, 2 x 18650) | rejected for D2 |
| **2S1P pack of the same 2 cells + 5 V >= 7 A buck on the header feed, replacing the X1203** | >= 35 W | **Pack**: same cells and the same bay envelope (`COTS['pack']` box unchanged), 2S BMS + balance lead, a 2S charger. **Buck**: module class <= 40 x 40 x 10 [est] in the X1203 slot (z 6.0-16.0 under the Pi); the release-v1 DROK 090483 (60 x 52 x 20, 8 A) does not fit that slot and would lift the Pi stack about 10 mm into the FPC/HDMI routes (z 30-44). **Lost**: the X1203 fuel gauge (add a 1-cell-class I2C monitor, +1 board), its start/stop logic. **Added**: an inline fuse, + about 4 solder joints; `COTS['x1203']`, `X1203_KIT`, `PI['x1203_z']` and the pigtail route are re-derived. **r2 fixer:** the `pi_keeper` fingers bear 0.1 over the X1203 top edge, so with the X1203 removed they hold nothing: the keeper fingers, the s_k1/s_k2 bosses and the Pi standoff support (what then carries the Pi standoffs on the floor bosses) are re-derived too (keeper reprint; G-KEEP-1 re-run) | named fallback |

### 4.6 Recommendation (option c)

Keep the X1203 and adopt R-P1 to R-P8 now (configuration only; no parts, no geometry). Keep the 27 W planning peak in
this document (it exceeds the 25.5 W rating; the 17.7-22.1 W estimate does not show that the X1203 suffices), and keep the 18 AWG / XT30 path sized for the full 25.5 W (8.6 A at 3.3 V). G-W12 must pass before
any powered full-build claim. If it fails, the 2S1P + buck arrangement of 4.5 is the next design, with the geometry
work listed there.
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

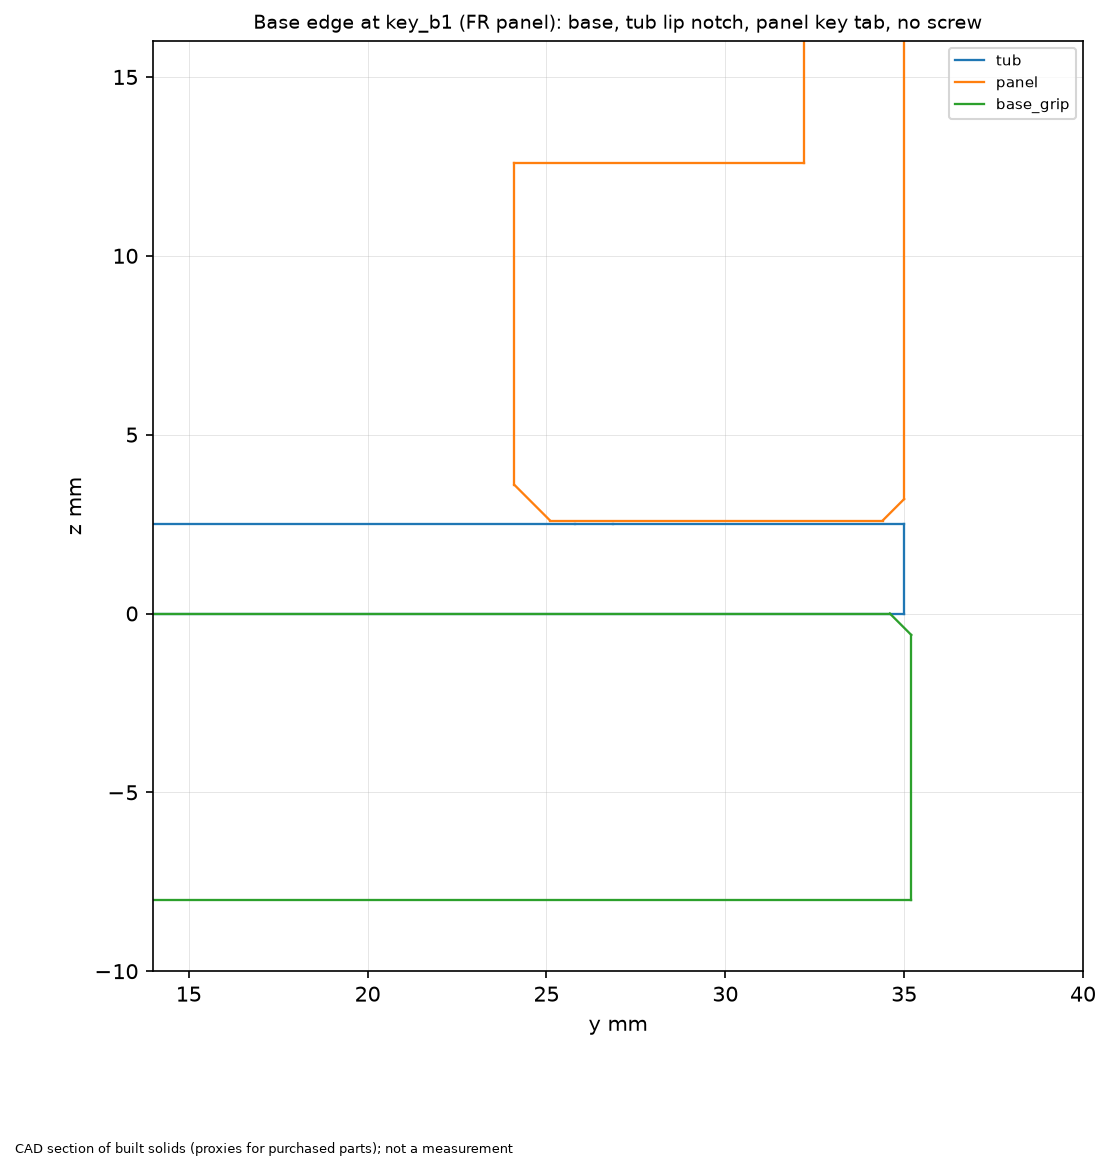
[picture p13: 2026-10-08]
audit/d2-readiness-2026-10-05-r3/rebuild-fr1/renders/section-base-edge-x91.png

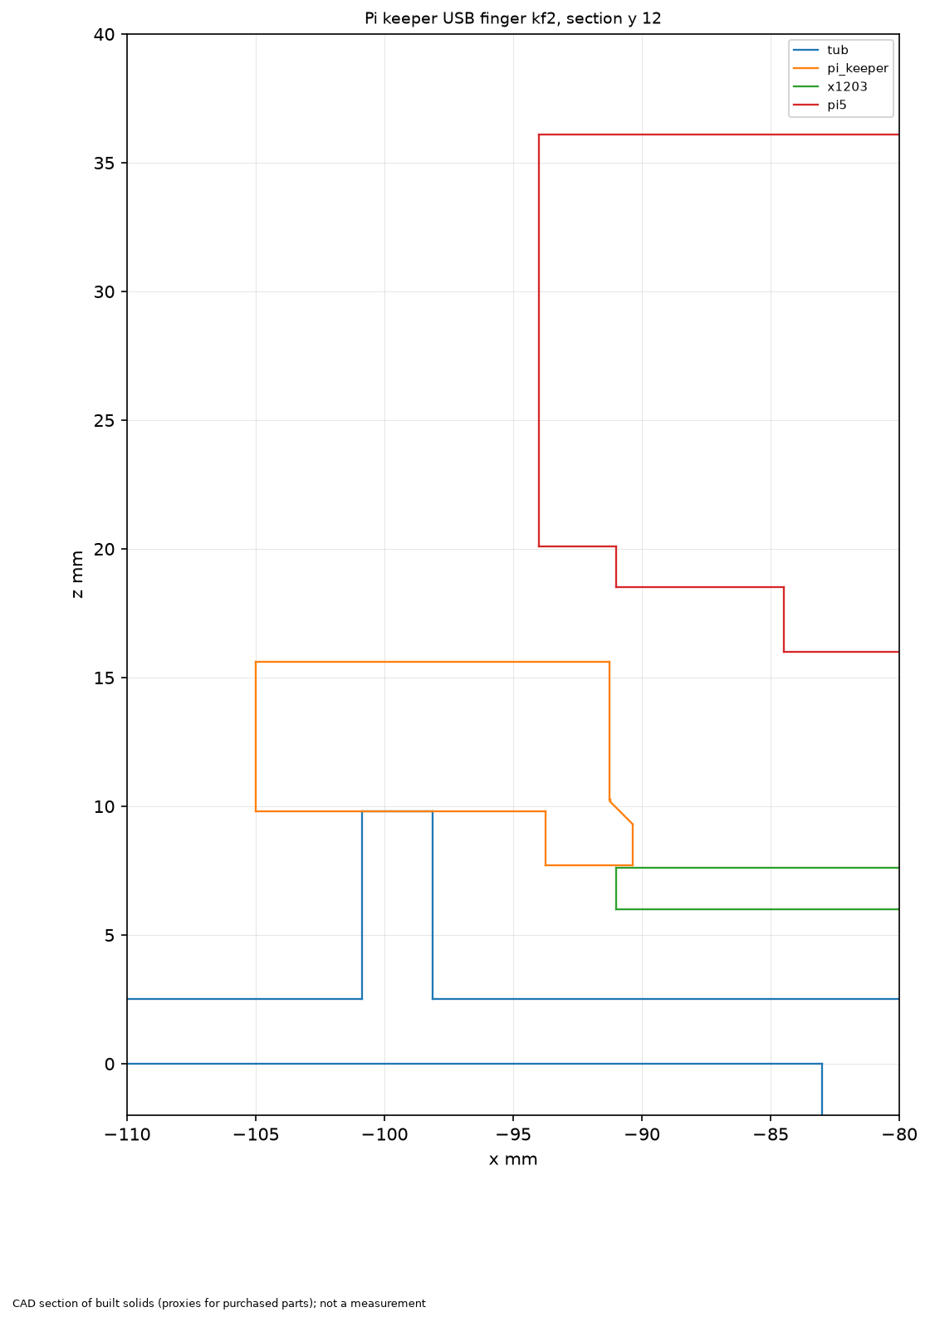
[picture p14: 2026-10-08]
audit/d2-readiness-2026-10-06/rebuild-kowa/renders/section-pi-keeper-y12.png

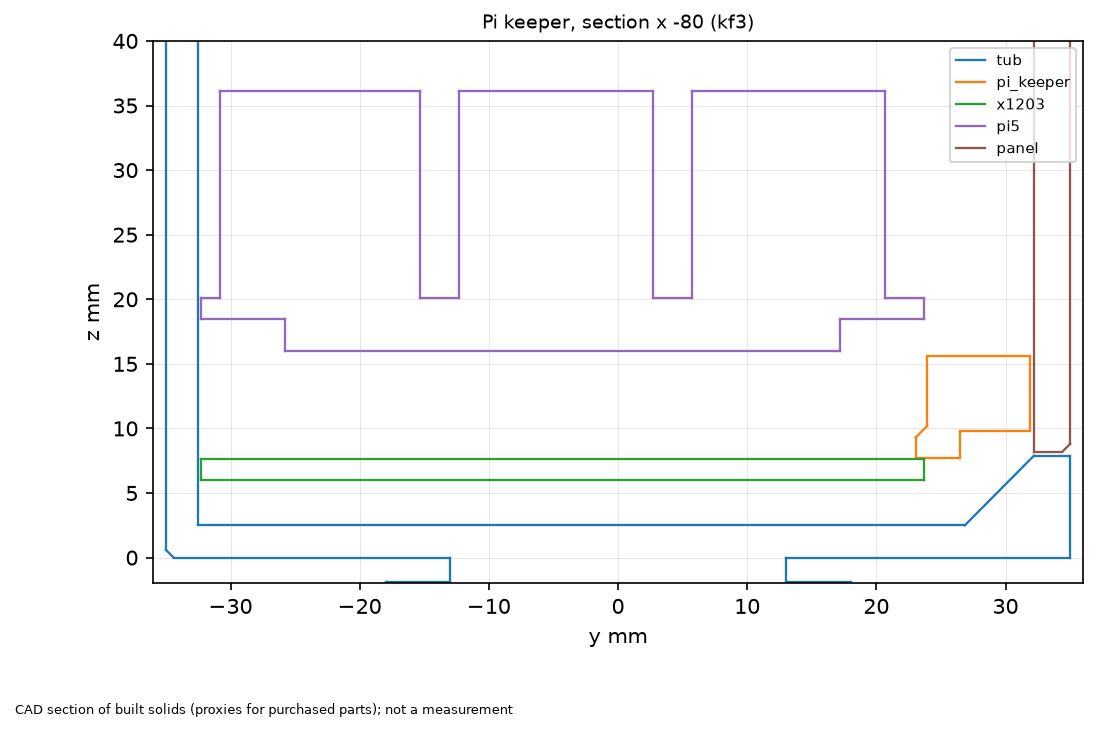
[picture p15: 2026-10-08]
audit/d2-readiness-2026-10-06/rebuild-kowa/renders/section-pi-keeper-x80.png

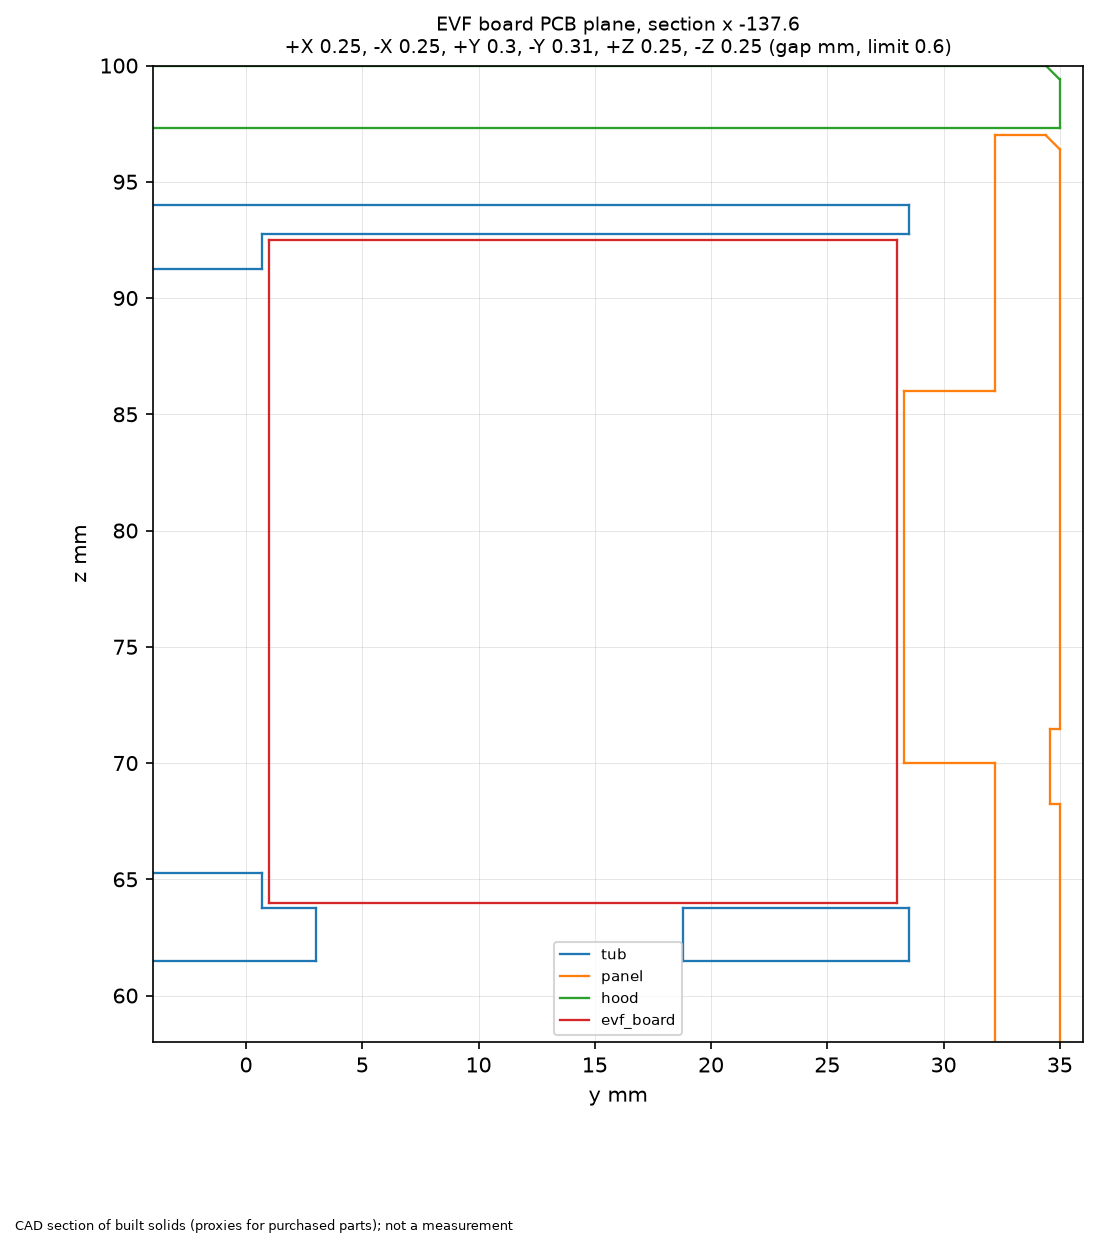
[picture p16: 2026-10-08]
audit/d2-readiness-2026-10-05-r3/rebuild-fr1/renders/section-evf-board-x137.png

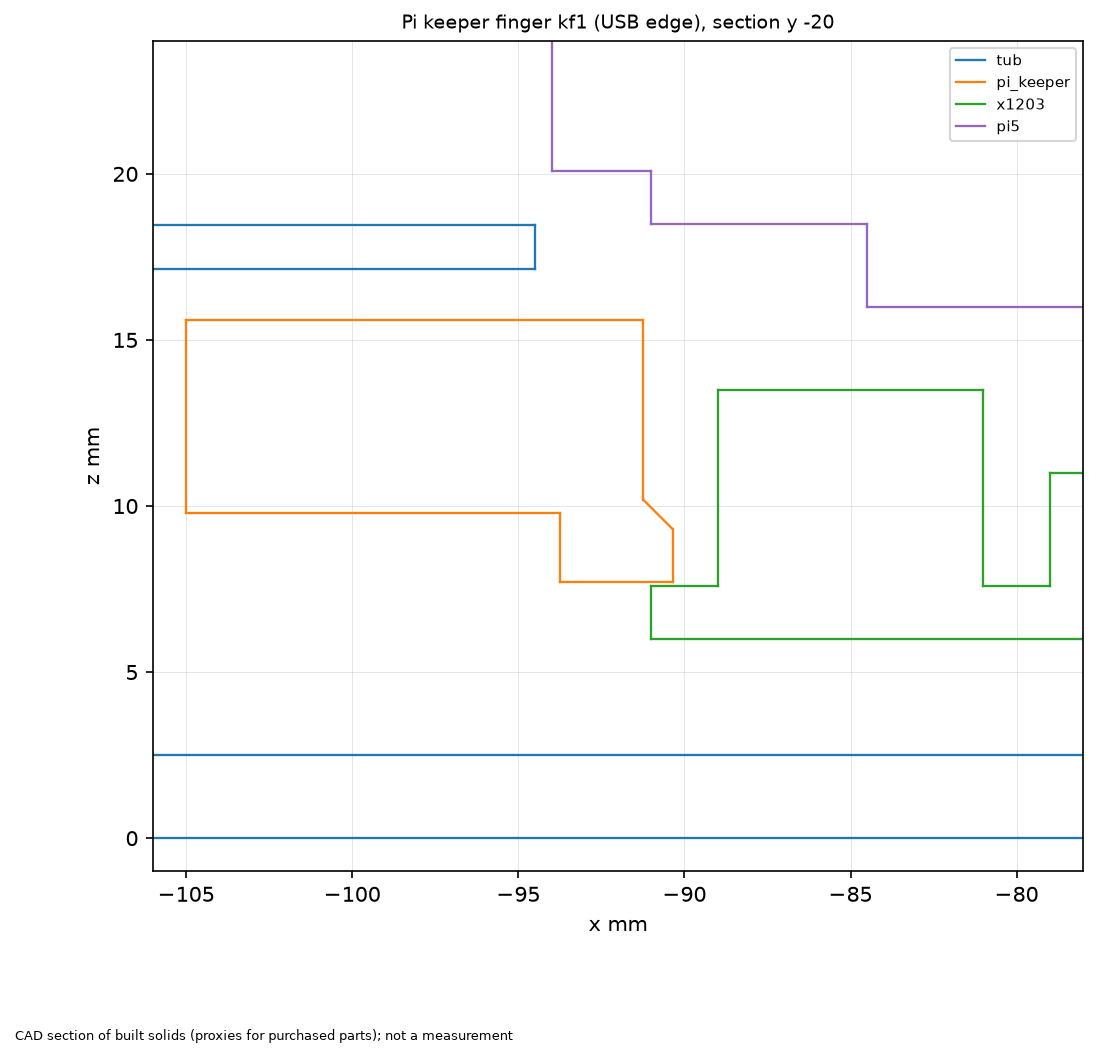
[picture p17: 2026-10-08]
audit/d2-readiness-2026-10-05-r3/rebuild-fr1/renders/section-pi-keeper-y-20.png

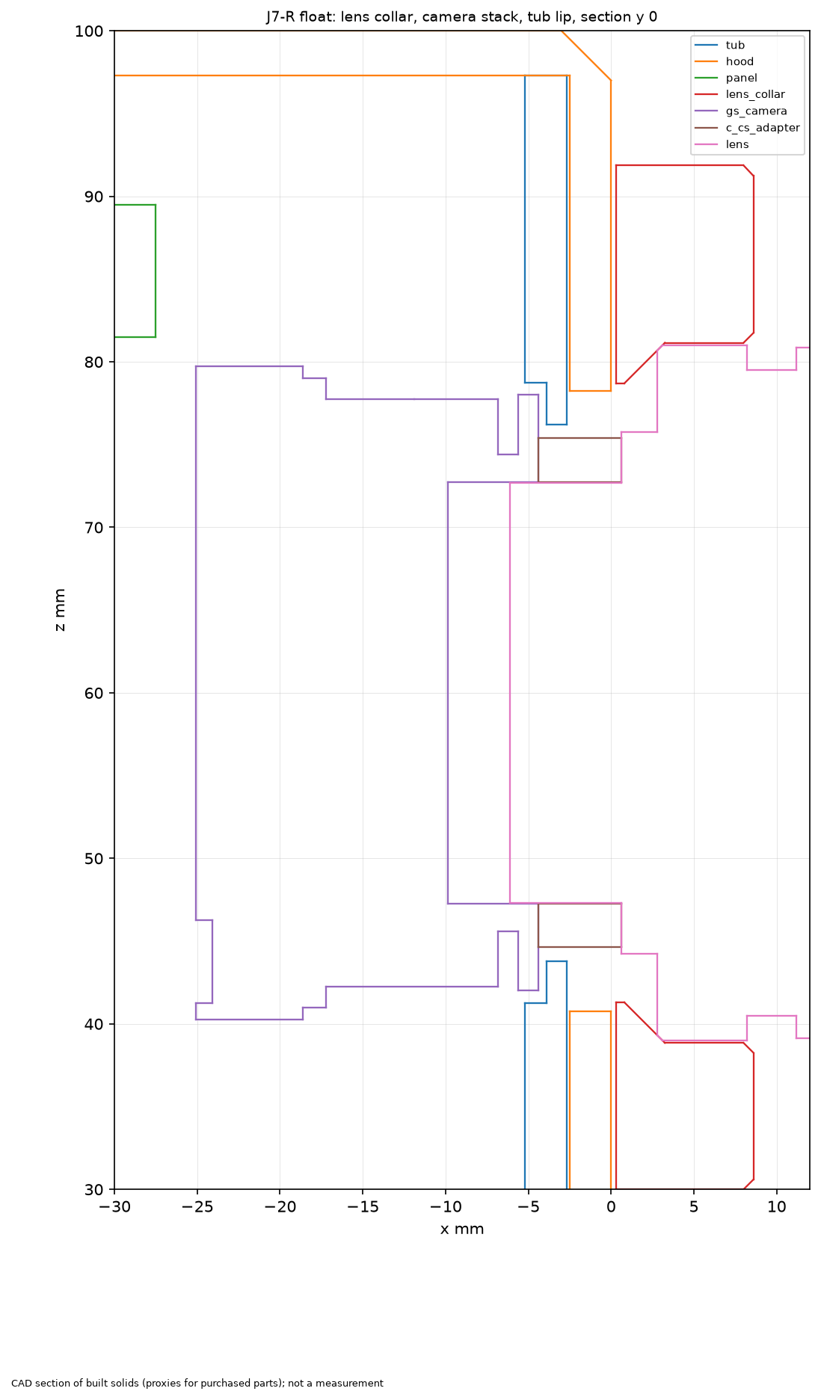
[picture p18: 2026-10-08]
audit/d2-readiness-2026-10-06/rebuild-kowa/renders/section-j7-y0.png

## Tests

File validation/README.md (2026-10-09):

# Cloud verification records

These records describe computational/host checks only. Every physical gate remains open (r7: 58 listed = 56 open +
2 withdrawn).

**r7 (2026-10-09, blocker review 2026-10-08 fixes).** `rebuilt-cad-integrity.json` is now the final-release audit of
the r7 build (Kowa 05:56:23 +0800 with the Fujinon alternate of 05:50:40): pass; sources 20/20, outputs 86/86, gate
docs 4/4; 35 categories (34 pass + `mass_com` report-only); 58 physical gates (56 open, 2 withdrawn; new G-EVF-3,
G-QT-1, G-HDR-1). Kowa 990 rows = 960 pass + 30 info + 0 fail; Fujinon 987 rows = 957 pass + 30 info + 0 fail. Tests
after that build (05:56-06:09 MPST, all through `run_locked.py`):
- `test_r3_regressions.py`: 82 of 82 cases pass;
- the focused unittest list: 73 tests OK, with 4 POSIX-only skips;
- `test_collar.py` both lenses: PASS in 118.8 s;
- r7 planted-fault suites (94 cases): `test_r7_c1.py` 14/14, `test_r7_c2_mate_reach.py` 13/13, `test_r7_c4.py`
  11/11 (cases 1-10 and 13), `test_r7_c5_handling.py` 19/19, `test_r7_lead_access.py` 21/21, `test_r7_fixup.py` 9/9,
  `test_r7_integration.py` 7/7 (its category-count case now runs against the r7 `checks.json`);
- `test_hood_panel.py` (hood and panel): PASS.

**r6 (2026-10-08).** `rebuilt-cad-integrity.json` is the final-release audit of the r6 build (Kowa 16:05:33 +0800 with
the Fujinon alternate): pass; sources 20/20, outputs 86/86, gate docs 4/4; 28 categories (27 pass + `mass_com`
report-only). Tests after that build:
- 82 custom regression cases (65 + 17 r6 planted-fault cases);
- 73 focused unittest cases, OK with 4 POSIX-only skips;
- `test_collar.py` both lenses, PASS in 151.8 s.

The records below describe the cloud-polish run that r6 builds on.

- `cad-kowa-integrity.json`: final Kowa source/output/gate-doc, mesh, STEP and producer-evidence audit.
- `cad-fujinon-integrity.json`: final Fujinon audit.
- `software-verification.json`: package source/test hashes, 256 EVF tests, post/recorder/model checks and wheel/source-package hashes. Its `sources_sha256` paths are relative to `software/gs8-camera-evf/`; `navigation_docs_sha256` paths are relative to the project root.
- `lock-contention.json`: separate-process contention, child lifetime and metadata results. Windows concurrency was not tested on Windows.

CAD verification on the final corrected geometry: 65 custom regression cases; 73 focused unittest cases; 18 common
helpers; and the full both-lens collar geometry/assembly check (127.6 s). All passed. Both final variants have 27
passing categories, zero failures/stubs/unclassified spots. Kowa has 748 pass/18 info rows, Fujinon 745 pass/18 info.

From `cad/gs8-d2-v1/`, using the pinned interpreter, run:

```text
python run_locked.py -- test_r3_regressions.py
python run_locked.py -- -m unittest -v test_mechanical_refinements test_datum_inputs test_panel_refinements test_collar_rear_land test_build_outputs test_print_stock_exports test_release_gates test_audit_cloud_release test_run_locked
python run_locked.py -- test_collar.py
python run_locked.py -- test_r7_c1.py
python run_locked.py -- test_r7_c2_mate_reach.py
python run_locked.py -- test_r7_c4.py --out <scratch>/test_r7_c4.json
python run_locked.py -- test_r7_c5_handling.py
python run_locked.py -- test_r7_lead_access.py
python run_locked.py -- test_r7_fixup.py
python run_locked.py -- test_r7_integration.py
python run_locked.py -- test_hood_panel.py
```

The r7 suites read the release STEPs in `out/step/parts` and `out/checks.json`, so run them after the release build.
`test_r7_c4.py --out` and moving `out/test_hood_panel_*.json` away keep `out/` to release outputs only.

The strict cloud artifact audit intentionally expects unadvanced physical evidence. Real bench results belong in the
project's structured evidence workflow; they must not be invented to turn an unmeasured assumption green.

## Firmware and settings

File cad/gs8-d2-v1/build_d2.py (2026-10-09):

# SPDX-License-Identifier: MIT
"""GS8 D2 release build: assemble every printed module + COTS proxies from layout.py, run the SPEC s6 checks,
export STL (print orientation), STEP, manifests, receipts and renders.

Run (repo root, always through the lock):
  .venv-cad/Scripts/python.exe cad/gs8-d2-v1/run_locked.py -- cad/gs8-d2-v1/build_d2.py [--fast] [--part ID]
      [--lens kowa_lm6hc|fujinon_hf6xa] [--sweep-step 2.0] [--no-sweeps] [--no-thin] [--out DIR]
--part ID  quick single-part run (printed id: contract, bed, thin wall, keep-outs, interference with COTS; STL)
--fast     skip VTK assembly views (and the STEP export)
--skip-renders  keep STEP and all checks; skip only VTK assembly views
Outputs in cad/gs8-d2-v1/out/: stl/<id>.stl, step/gs8-d2-assembly.step, print-manifest.json, parts-manifest.json,
checks.json, build-receipt.json, renders/{hero,exploded,xray}.png (part runs: part-<id>.json, stl/<id>.stl).
A printed module that is missing or fails to build is replaced by its envelope box (stub=True): it is assembled and
checked, but a stub result never passes and cad_release_candidate stays false. Purchased parts are proxies; nothing is
printed, bought or measured. r2 (R3): the receipt carries status_states (cad_checks computed; slicer_review,
coupon_validation, measured_fit, assembly_operation from structured evidence records, r3: evidence/README.md, bound to
the sha256 of the tested artifacts; pass / fail / conflict / stale / not run per item); critical_features
gates local thickness (thin_wall is a secondary screen); evf_restraint, removals and service_driver check finding 6
and the service paths; renders/section-<id>.png come from layout.SECTIONS.
"""
import argparse
import hashlib
import importlib.util
import json
import math
import os
import sys
import time
import traceback

HERE = os.path.dirname(os.path.abspath(__file__))
sys.path.insert(0, HERE)

import cadquery as cq  # noqa: E402

import checks as CK  # noqa: E402
import cots  # noqa: E402
import d2_common as dc  # noqa: E402
import layout as L  # noqa: E402

OUT = os.path.join(HERE, 'out')
T0 = time.time()
TIMES = {}


def log(*a):
    print('[%6.1fs]' % (time.time() - T0), *a, flush=True)


def lap(name, t0):
    TIMES[name] = round(time.time() - t0, 2)
    log('%s done in %.1f s' % (name, TIMES[name]))


def sha(path):
    with open(path, 'rb') as f:
        return hashlib.sha256(f.read()).hexdigest()


def write_json(name, data):
    p = os.path.join(OUT, name)
    with open(p, 'w', encoding='utf-8', newline='\n') as f:
        json.dump(data, f, indent=1, default=str)
    return p


def as_shape(obj):
    """Workplane / Shape -> one cq.Shape (Solid, or Compound when several)."""
    if obj is None:
        return None
    if isinstance(obj, cq.Workplane):
        vals = [v for v in obj.vals() if isinstance(v, cq.Shape)]
        sols = [s for v in vals for s in v.Solids()]
        if len(sols) == 1:
            return sols[0]
        return cq.Compound.makeCompound(sols if sols else vals)
    return obj


# ------------------------------------------------------------------------------------------- printed modules
def load_module(fname):
    path = os.path.join(HERE, fname)
    if not os.path.exists(path):
        return None, 'missing'
    try:
        spec = importlib.util.spec_from_file_location(fname[:-3], path)
        mod = importlib.util.module_from_spec(spec)
        spec.loader.exec_module(mod)
        return mod, 'ok'
    except Exception:  # noqa: BLE001
        return None, 'import error: ' + traceback.format_exc(limit=3)


STUB_WALL = 2.0


def stub_shape(env):
    """Envelope box, hollowed to a closed 2.0 shell when every side is >= 10 mm (keeps stub masses plausible)."""
    b = dc.box_solid(env)
    d = [env[k][1] - env[k][0] for k in 'xyz']
    if min(d) >= 10.0:
        w = STUB_WALL
        b = b.cut(dc.box_solid({k: (env[k][0] + w, env[k][1] - w) for k in 'xyz'}))
    return b


def stub_row(pid, why):
    p = L.PARTS[pid]
    return dict(shape=stub_shape(p['envelope']), kind='printed', stub=True, stub_reason=why, module=p['module'],
                print=dict(face_down=p['face_down'], supports=p['supports'], notes='stub (envelope box)'))


def build_printed(only=None):
    """{pid: row}. only = a single printed id for --part runs."""
    rows, mods = {}, {}
    by_mod = {}
    for pid, p in L.PARTS.items():
        if only is None or pid == only:
            by_mod.setdefault(p['module'], []).append(pid)
    for fname, pids in by_mod.items():
        t0 = time.time()
        mod, st = load_module(fname)
        mods[fname] = dict(status=st, parts=pids)
        built = {}
        if mod is not None:
            try:
                if only is not None and hasattr(mod, 'build_part'):
                    built = {only: mod.build_part(L, only)}
                else:
                    built = mod.build(L)
                mods[fname]['status'] = 'built'
            except Exception:  # noqa: BLE001
                mods[fname]['status'] = 'build error: ' + traceback.format_exc(limit=4)
                built = {}
        pr = getattr(mod, 'PRINT', {}) if mod is not None else {}
        for pid in pids:
            if pid in built and built[pid] is not None:
                rows[pid] = dict(shape=as_shape(built[pid]), kind='printed', stub=False, module=fname,
                                 print=pr.get(pid, {}), n_solids=len(built[pid].solids().vals())
                                 if isinstance(built[pid], cq.Workplane) else 1)
                if hasattr(mod, 'prepare_print'):
                    prep = mod.prepare_print(L, pid, rows[pid]['shape'])
                    rows[pid]['print_shape'] = as_shape(prep['shape'])
                    rows[pid]['print_preparation'] = {k: v for k, v in prep.items() if k != 'shape'}
            else:
                rows[pid] = stub_row(pid, mods[fname]['status'] if mod is None or pid not in built
                                     else 'part missing from build()')
        mods[fname]['seconds'] = round(time.time() - t0, 2)
        log('module %s: %s (%s)' % (fname, mods[fname]['status'].split('\n')[0], ', '.join(pids)))
    return rows, mods


def contract_checks(rows):
    out = []
    for pid, r in rows.items():
        if r['kind'] != 'printed':
            continue
        p = L.PARTS[pid]
        if r.get('stub'):
            out.append(dict(part=pid, status='stub', reason=r['stub_reason'].split('\n')[0]))
            continue
        sh = r['shape']
        bb = CK.bb_tuple(sh)
        env = CK.box_bb(p['envelope'])
        over = [_round(env[0] - bb[0]), _round(bb[1] - env[1]), _round(env[2] - bb[2]), _round(bb[3] - env[3]),
                _round(env[4] - bb[4]), _round(bb[5] - env[5])]
        inside = max(over) <= 1e-3
        nsol = len(sh.Solids())
        valid = sh.isValid()
        fd_ok = r['print'].get('face_down', p['face_down']) == p['face_down']
        ok = inside and nsol == 1 and valid and fd_ok and bool(r['print'])
        out.append(dict(part=pid, status='pass' if ok else 'fail', one_solid=nsol == 1, n_solids=nsol, valid=valid,
                        inside_envelope=inside, envelope_excess=over, face_down_matches=fd_ok,
                        print_entry=bool(r['print']), volume_mm3=round(sh.Volume(), 1)))
    return out


def _round(x, n=3):
    return round(float(x), n)


# ------------------------------------------------------------------------------------------- COTS
def build_cots(only=None):
    t = cots.build_all(L, only=only)
    rows = {}
    for cid, r in t.items():
        rows[cid] = dict(r, shape=as_shape(r['shape']) if r['shape'] is not None else None, stub=False)
    return rows


def cots_containment(rows):
    out = []
    for cid, r in rows.items():
        if r['kind'] == 'printed' or r.get('box') is None or r.get('shape') is None:
            continue
        bb, env = CK.bb_tuple(r['shape']), CK.box_bb(r['box'])
        over = max(env[0] - bb[0], bb[1] - env[1], env[2] - bb[2], bb[3] - env[3], env[4] - bb[4], bb[5] - env[5])
        out.append(dict(id=cid, status='pass' if over <= 0.02 else 'fail', excess=_round(over)))
    return out


# ------------------------------------------------------------------------------------------- exports
PRINT_RATE = 6.0     # mm3/s effective extrusion (0.4 nozzle, 0.2 layers, ASA, enclosed) -> time estimate only


def export_modifiers(pid, r, fd):
    """r4: slicer modifier meshes (layout.print_modifiers) in the SAME print pose as the part STL: the rotation of
    dc.to_print_pose, then the translation that put the rotated part on the bed origin. Each must overlap its part
    (a modifier that misses the part is a stale definition and fails). -> manifest rows."""
    mods = L.print_modifiers(pid)
    mdir = os.path.join(OUT, 'stl', 'modifiers')
    if os.path.isdir(mdir):             # never leave a modifier from an older build beside the current ones
        for f in os.listdir(mdir):
            if f.startswith(pid + '__mod_'):
                os.remove(os.path.join(mdir, f))
    if not mods or r.get('stub') or r.get('shape') is None:
        return []
    rx, ry, rz = dc.FACE_DOWN_ROT[fd]

    def rot(s):
        for ang, ax in ((rx, (1, 0, 0)), (ry, (0, 1, 0)), (rz, (0, 0, 1))):
            if ang:
                s = s.rotate(dc.V(0, 0, 0), dc._v(ax), ang)
        return s
    bb = rot(r['shape']).BoundingBox()
    shift = dc.V(-bb.xmin, -bb.ymin, -bb.zmin)
    os.makedirs(mdir, exist_ok=True)
    rows = []
    for m in mods:
        if m['kind'] == 'cyl':
            p0, p1 = dc.V(*m['p0']), dc.V(*m['p1'])
            solid = cq.Solid.makeCylinder(m['r'], (p1 - p0).Length, p0, (p1 - p0).normalized())
        else:
            solid = dc.box_solid(m['box'])
        ov = r['shape'].intersect(solid).Volume()
        name = '%s__mod_%s.stl' % (pid, m['id'])
        path = os.path.join(mdir, name)
        rot(solid).translate(shift).exportStl(path, 0.05, 0.3)
        rows.append(dict(id=m['id'], kind=m['kind'], stl='stl/modifiers/' + name, stl_sha256=sha(path),
                         infill_pct=L.MOD_INFILL, perimeters=4, part_overlap_mm3=round(ov, 1),
                         status='pass' if ov > 1.0 else 'fail',
                         note='load as a modifier mesh at its exported position (same bed frame as the part); '
                              'translate together with the part, never alone'))
    return rows


def print_overhang(pid, r, pose, fd):
    """r6 (settled orientation): the computed print_overhang row of one part in its print pose; the declared support
    zones (layout.PRINT_SUPPORT_ZONES, assembly frame) are mapped with the same transform as the STL."""
    if r.get('stub'):
        return dict(kind='print_overhang', part=pid, face_down=fd, status='stub')
    try:
        src = r.get('print_shape', r['shape'])
        rot, t = dc.print_pose_transform(src, fd)
        zones = [dict(z, box=dc.map_box(z['box'], rot, t)) for z in (L.PRINT_SUPPORT_ZONES.get(pid) or [])]
        return CK.check_print_overhang(L, pid, CK.manifold_of_tol(pose, 0.03, 0.2), zones)
    except Exception as e:  # noqa: BLE001 - a failed check is a FAIL row, never a skipped one
        return dict(kind='print_overhang', part=pid, face_down=fd, status='fail',
                    error='%s: %s' % (type(e).__name__, str(e)[:200]))


def export_part(pid, r, bed_rows, thin_rows, mesh_rows, overhang_rows=None):
    """Print-pose STL + manifest row for one printed part."""
    p = L.PARTS[pid]
    fd = p['face_down']
    pose = dc.to_print_pose(r.get('print_shape', r['shape']), fd)
    os.makedirs(os.path.join(OUT, 'stl'), exist_ok=True)
    path = os.path.join(OUT, 'stl', pid + '.stl')
    if r.get('stub'):                  # never leave a printable file for a stub (or a stale one from an older build)
        if os.path.exists(path):
            os.remove(path)
    else:
        pose.exportStl(path, 0.03, 0.2)
    mesh_rows.append(stl_mesh_check(pid, pose, r))
    bed = CK.check_bed(L, pid, pose)
    if r.get('stub'):
        bed['status'] = 'stub'
    bed_rows.append(bed)
    finished_vol = r['shape'].Volume()
    vol = r.get('print_shape', r['shape']).Volume()
    rho = L.TPU_DENSITY if p['material'].startswith('TPU') else L.FDM['ASA_DENSITY']
    m = L.mass_g(vol, pid)
    hours = (vol * L.INFILL_FACTOR[p['infill']] / PRINT_RATE) / 3600 * 1.15 + 0.1
    pr = r.get('print') or {}
    th = next((t for t in thin_rows if t['part'] == pid), None)
    ov = print_overhang(pid, r, pose, fd)
    if overhang_rows is not None:
        overhang_rows.append(ov)
    ov_summary = dict(status=ov['status'], longest_bridge_mm=ov.get('longest_bridge_mm'),
                      bridge_regions=ov.get('bridge_regions'), hole_edge_bridges=ov.get('hole_edge_bridges'),
                      supports=sorted(ov.get('supports_used') or {}), unsupported=len(ov.get('unsupported') or []),
                      check='checks.json print_overhang (r6)')
    return dict(print_overhang=ov_summary, print_after=list(L.PRINT_PREREQS.get(pid, ())),
                orientation_why=L.PRINT_ORIENTATION_WHY.get(pid), modifiers=export_modifiers(pid, r, fd),
                id=pid, module=p['module'], material=p['material'], colour=p['colour'], face_down=fd,
                supports=pr.get('supports', p['supports']), notes=pr.get('notes', ''), infill_class=p['infill'],
                print_preparation=r.get('print_preparation'), finished_volume_mm3=round(finished_vol, 3),
                infill_factor=L.INFILL_FACTOR[p['infill']], volume_mm3=round(vol, 1), mass_100pct_g=round(vol * rho, 1),
                mass_est_g=round(m, 1), filament_g_est=round(m * 1.05, 1), print_time_est_h=round(hours, 2), print_bbox_mm=bed['print_bbox'],
                bed_fit=bed['beds'], stl=None if r.get('stub') else 'stl/%s.stl' % pid,
                stl_sha256=None if r.get('stub') else sha(path), stub=bool(r.get('stub')),
                thin_wall=None if th is None else dict(status=th['status'], p1=th.get('p1'), min=th.get('min')))


def stl_mesh_check(pid, pose, r):
    """The print mesh (STL tolerance 0.03 mm / 0.2 rad) must be one watertight 2-manifold shell whose volume
    matches the BRep within 0.5 %."""
    try:
        man = CK.manifold_of_tol(pose, 0.03, 0.2)
        if man is None:
            return dict(part=pid, status='stub' if r.get('stub') else 'fail', error='not a 2-manifold mesh')
        shells = len(man.decompose())
        vb = pose.Volume()
        dv = abs(man.volume() - vb) / max(vb, 1e-9)
        ok = shells == 1 and dv <= 0.005
        st = 'pass' if ok else 'fail'
        if r.get('stub'):
            st = 'stub'
        return dict(part=pid, status=st, watertight=True, shells=shells, volume_brep=round(vb, 1),
                    volume_mesh=round(man.volume(), 1), volume_dev=round(dv, 5))
    except Exception as e:  # noqa: BLE001
        return dict(part=pid, status='fail', error=str(e))


COLOURS = {'satin silver': '#c9cac6', 'black': '#2b2c2f', 'clear/natural': '#e6e0cc'}
COTS_COLOUR = {'pi5': '#2f6b45', 'x1203': '#24563a', 'evf_board': '#2f6b45', 'encoder': '#2a4f8a', 'cooler': '#9a9ea3',
               'gs_camera': '#3b3f45', 'lens': '#1c1d1f', 'c_cs_adapter': '#7d7f82', 'eyepiece': '#46494e',
               'hmx039': '#151515', 'usb_stick': '#a3262b', 'switch_1824': '#6b6d70', 'run_button': '#c8262b',
               'pack': '#3a6ea5', 'xt30_pair': '#e0b020', 'tripod_nut': '#a9a9a2', 'strap': '#3d3328',
               'foam_pad': '#222222', 'x1203_kit': '#c9a86a'}


def hex_rgb(c):
    return tuple(int(c[k:k + 2], 16) / 255 for k in (1, 3, 5))


def colour_of(i, r):
    if r.get('stub'):
        return '#e0904a'
    if r['kind'] == 'printed':
        return COLOURS.get(L.PARTS[i]['colour'], '#2b2c2f')
    if i.startswith('s_'):
        return '#b8b8b0'
    return COTS_COLOUR.get(i, '#5d7a62')


def export_step(rows):
    os.makedirs(os.path.join(OUT, 'step'), exist_ok=True)
    asm = cq.Assembly(name='gs8_d2')
    for i, r in rows.items():
        if r.get('shape') is None:
            continue
        asm.add(r['shape'], name=i, color=cq.Color(*hex_rgb(colour_of(i, r)), 1.0))
    os.makedirs(os.path.join(OUT, 'step', 'parts'), exist_ok=True)
    for i, r in rows.items():          # one STEP per printed part, assembly pose (for edits in other CAD tools)
        pth = os.path.join(OUT, 'step', 'parts', i + '.step')
        if r['kind'] == 'printed' and not r.get('stub') and r.get('shape') is not None:
            cq.exporters.export(cq.Workplane().add(r['shape']), pth)
        elif r['kind'] == 'printed' and os.path.exists(pth):
            os.remove(pth)
    path = os.path.join(OUT, 'step', 'gs8-d2-assembly.step')
    if hasattr(asm, 'export'):
        asm.export(path)
    else:
        asm.save(path)
    return path


# ------------------------------------------------------------------------------------------- renders (VTK)
EXPLODE = {'hood': (0, 0, 70), 'plunger': (35, 0, 0), 'panel': (0, 85, 0), 'knob_exp': (0, 125, 0),
           'knob_fps': (0, 125, 0), 'encoder': (0, 85, 0), 'switch_1824': (0, 85, 0), 'base_grip': (0, 0, -60),
           'skirt_l': (0, 25, -60), 'skirt_r': (0, -25, -60), 'cap': (0, 0, -150), 'pack': (0, 0, -105),
           'xt30_pair': (0, 0, -85), 'tripod_nut': (0, 0, -45), 'run_button': (25, 0, -60), 'strap': (0, -30, -60),
           'eyecup': (-60, 0, 0), 'eyepiece': (-35, 0, 0), 'stick_sleeve': (-75, 0, 0), 'usb_stick': (-60, 0, 0),
           'lens': (75, 0, 0), 'c_cs_adapter': (58, 0, 0), 'gs_camera': (0, 55, 15), 'pi5': (0, 0, 25),
           'lens_collar': (40, 0, 0),   # r5 (judge 3 s6.9): collar +X 40; adapter 45 -> 58 so it is not drawn inside the collar

           'cooler': (0, 0, 35), 'x1203': (0, 0, 15), 'x1203_kit': (0, 0, 20), 'hmx039': (0, 45, 0),
           'evf_board': (0, 50, 0), 'foam_pad': (0, 45, 0)}


def explode_of(i):
    if i.startswith('s_'):
        s = next(s for s in L.SCREWS if s['id'] == i)
        base = (0, 0, -60) if s['axis'][2] else (0, 0, 0)
        if s.get('kind', 'PT') == 'M3':      # r5: the collar screws ride out with the collar (+X 40), then back out 30
            base = EXPLODE.get(s['head_part'], (0, 0, 0))
        return tuple(base[k] - s['axis'][k] * 30 for k in range(3))
    return EXPLODE.get(i, (0, 0, 0))


VIEWS = {'hero': ((230.0, 260.0, 190.0), (-70.0, 0.0, -2.0), 158.0, 'assembled'),
         'exploded': ((260.0, 300.0, 210.0), (-62.0, 20.0, -35.0), 255.0, 'exploded'),
         'xray': ((-62.0, 500.0, -5.0), (-62.0, 0.0, -5.0), 130.0, 'xray'),
         'section-lens-axis': ((-62.0, 500.0, -5.0), (-62.0, 0.0, -5.0), 130.0, 'section 0.0'),
         'section-evf-axis': ((-120.0, 500.0, 60.0), (-120.0, 16.0, 60.0), 70.0, 'section 16.0')}


def _actor(vtk, Vm, Fm, colour, opacity, pos, clip=None):
    import numpy as np
    from vtk.util.numpy_support import numpy_to_vtk, numpy_to_vtkIdTypeArray
    pts = vtk.vtkPoints()
    pts.SetData(numpy_to_vtk(np.ascontiguousarray(Vm, np.float32), deep=True))
    cells = np.hstack([np.full((len(Fm), 1), 3, np.int64), Fm.astype(np.int64)]).ravel()
    ca = vtk.vtkCellArray()
    ca.SetCells(len(Fm), numpy_to_vtkIdTypeArray(cells, deep=True))
    poly = vtk.vtkPolyData()
    poly.SetPoints(pts)
    poly.SetPolys(ca)
    nr = vtk.vtkPolyDataNormals()
    nr.SetInputData(poly)
    nr.SetFeatureAngle(35)
    nr.SplittingOn()
    mp = vtk.vtkPolyDataMapper()
    mp.SetInputConnection(nr.GetOutputPort())
    a = vtk.vtkActor()
    if clip is not None:            # section view: keep the half behind the plane, cut faces in orange
        pl = vtk.vtkPlane()
        pl.SetOrigin(*clip[0])
        pl.SetNormal(*clip[1])
        mp.AddClippingPlane(pl)
        bp = vtk.vtkProperty()
        bp.SetColor(*hex_rgb('#d9622b'))
        bp.SetAmbient(.55)
        bp.SetDiffuse(.45)
        a.SetBackfaceProperty(bp)
    a.SetMapper(mp)
    pr = a.GetProperty()
    pr.SetColor(*hex_rgb(colour))
    pr.SetAmbient(.25)
    pr.SetDiffuse(.72)
    pr.SetSpecular(.2)
    pr.SetSpecularPower(25)
    pr.SetOpacity(opacity)
    a.SetPosition(*pos)
    return a
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

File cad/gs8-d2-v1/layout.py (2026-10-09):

# SPDX-License-Identifier: MIT
"""GS8 D2 release layer: the single source of truth for geometry (no CAD dependency).

Import it from any build module:  import layout as L   (or  from layout import *).
Run it (plain python, no CadQuery) to self-check and print a summary:  python cad/gs8-d2-v1/layout.py

FRAME (all numbers in mm, assembly coordinates):
  X forward (toward the lens), Y to the operator's LEFT (panel side), Z up.
  Origin: body-bottom centre at the front plate, i.e. x = 0 is the hood front-plate OUTER face, y = 0 the body
  centre plane, z = 0 the tub floor underside (body bottom). The black base hangs below z = 0.
  The concept (concepts/nizo-evf-2026-10-03/D2/build_concept.py) had x = 0 at mid-length; every concept x is
  shifted by SHIFT = -77.0 (use cx()). y and z are unchanged.
Every number below comes from the concept unless a comment says CHANGED (then SPEC.md section 9 says why).
Purchased-part numbers are proxies (datasheet / listing / repo / estimate as tagged); nothing is printed, bought
or measured.

BOX convention: B(x0, x1, y0, y1, z0, z1) -> {'x': (x0, x1), 'y': (y0, y1), 'z': (z0, z1)}.
"""
import math

REVISION = 'GS8 D2 r7-20261009 (r6-20261008 + blocker review 2026-10-08 fixes)'
SHIFT = -77.0                      # concept x -> D2 x


def cx(*xs):
    """Concept x -> D2 x (one value, or a tuple for several)."""
    r = tuple(round(x + SHIFT, 4) for x in xs)
    return r[0] if len(r) == 1 else r


def B(x0, x1, y0, y1, z0, z1):
    return {'x': (round(x0, 4), round(x1, 4)), 'y': (round(y0, 4), round(y1, 4)), 'z': (round(z0, 4), round(z1, 4))}


def CYL(axis, c0, c1, r, a0, a1, r_in=None):
    """Cylinder along `axis` ('x'|'y'|'z'); (c0, c1) = the other two coordinates in xyz order; a0..a1 along the axis."""
    d = {'axis': axis, 'c': (round(c0, 4), round(c1, 4)), 'r': r, 'a': (round(a0, 4), round(a1, 4))}
    if r_in is not None:
        d['r_in'] = r_in
    return d


# =============================================================================== 1. FDM rules (from release_common.py)
FDM = dict(
    NOZZLE=0.4, LAYER=0.2,
    MIN_WALL=1.2, MIN_WALL_LOADED=1.6, MIN_FEATURE=0.8,
    SLIDE=0.25, LOCATE=0.15, SEAM=0.3,                  # per side
    MAX_OVERHANG_DEG=45.0, MAX_BRIDGE=30.0, TEARDROP_ABOVE_D=8.0,
    BED_CHAMFER=0.6,                                    # 45 deg chamfer on bed-face edges, no fillets on the bed face
    ENGRAVE_DEPTH=0.4, ENGRAVE_MIN_STROKE=0.6,
    ENGRAVE_TEXT_GROW=0.15,                             # FIXER P1: glyph outlines grow 0.15 per side (strokes >= 0.8)
    ENGRAVE_MAX_THIN_SHARE=0.20,                        # FIXER P1: groove check, share of a glyph under MIN_STROKE
    KNOB_BORE_OFFSET=0.10,                              # FIXER P10: radial D-bore growth over the shaft (coupon sets it)
    SNAP_GUSSET=0.8,                                    # FIXER P2: 45 deg root gusset leg on snap beams
    SNAP_KT=1.5,                                        # FIXER P2: strain concentration with the 0.8 gusset (r/t 0.5)
    ASA_DENSITY=1.07e-3,                                # g/mm3
)
PRINT_BEDS = {'250x210x220 (Prusa MK4/Core One class)': (250, 210, 220),
              '256x256x256 (Bambu X1/P1 class)': (256, 256, 256)}
# infill factor for mass = solid volume x ASA density x factor (4 walls, 25 % gyroid; small parts 100 %)
INFILL_FACTOR = {'shell': 0.85, 'base_grip': 0.6, 'small': 1.0, 'tpu': 1.0, 'thin': 1.0}
TPU_DENSITY = 1.21e-3

# =============================================================================== 2. global datums and body
L, W, H = 154.0, 70.0, 100.0
X_FRONT = 0.0                       # hood front-plate outer face
X_REAR = -154.0                     # tub rear outer face (concept X0 = -77)
T = 2.5                             # tub wall
XT1 = -2.7                          # tub front-wall outer face (concept X1 - 2.7)
X_FW_IN = XT1 - T                   # -5.2 tub front-wall inner face = CAMERA SEAT and Pi-edge reference
X_RW_IN = X_REAR + T                # -151.5 tub rear-wall inner face
ZT1 = 97.3                          # tub wall tops = hood band underside (declared contact)
YR, YL = -35.0, 35.0                # right wall outer face, panel outer face
Y_RW_IN = YR + T                    # -32.5 right-wall inner face
SPLIT = YL - 2.8                    # 32.2 panel inner face / tub-panel joint plane
RV = 5.0                            # vertical edge radius of the body outline (tub + panel)
FLOOR_Z = (0.0, T)                  # tub floor
LENS_AXIS = (0.0, 60.0)             # (y, z) of the optical axis
EYE_AXIS = (16.0, 78.0)             # (y, z) of the EVF axis
DIAL_Z = 57.0                       # control line on the panel
EXP_X, FPS_X = cx(14.0), cx(-46.0)  # -63.0 exposure dial, -123.0 18/24 selector
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

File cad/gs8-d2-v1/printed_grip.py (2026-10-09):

# SPDX-License-Identifier: MIT
"""GS8 D2 printed parts, owner grip_small (r2: R2): black ASA base + grip (one print) and the battery cap.

MODULE CONTRACT (layout.MODULE_CONTRACT): build(layout) -> {part_id: Workplane} for base_grip and cap
(r2 R2: the skirts are gone), in ASSEMBLY coordinates (X forward, Y left, Z up; mm); PRINT at module level; build_part(layout, part_id).

Owner design choices (the layout fixes the envelopes and the interface positions; these are internal joints):
- r2 R2 (finding 3): the 2 skirts and the J5 dovetail joint are ELIMINATED. The base side faces are plain (no groove,
  no barb dimple); the tub lip notches are filled flush by the panel boss tabs, so the panel comes off along +Y with
  4 PH1 screws out and nothing else (NOTES.md "r2 R2 options"). The base stays a separate print on the J4 keyholes.
- J6 cap -> grip: the cap carries 2 keys INSIDE the bay (web 1.6 at y +-10.65..12.25, 0.65 clear of the 20 mm pack;
  head 1.0 into a groove in each side wall with a 45 deg lower face, so the cap hangs on 45 deg lips 1.6 thick).
  The grooves end at x -60 (closed stop, key rear contact) and run out forward through 2 notches at the front
  corners, so the cap slides +X to open. Detent: a 0.35 bump on each key tip clicks into a 0.3 dimple near the
  rear (the free bottom edge of each side wall flexes 0.1 as it passes).
  r2 R2: key top -106.5 -> -105.9 (groove top -105.65), so the 45 deg head is 1.4 at its tip (was 0.8) and the
  detent bump is 1.2 tall in z (was 0.6); every retention section is >= 1.2 (CRITICAL_FEATURES in layout.py).
- J13 run button: the switch drops straight into a cradle (shelf + rear stop + 45 deg side guides) under the
  base opening; its red cap presses on through the dia 13.6 hole from the front (teardrop roof toward -Z, the print
  top). The rear stop takes the press load. The base opening is shaped to the switch, run-lead and pigtail
  passages (all inside layout.BASE_OPENING), which leaves base over the rear stop.
"""
import math

import cadquery as cq

import d2_common as dc

V = cq.Vector
SQ2 = math.sqrt(2.0)

CAP_KEY = dict(web_y=(10.65, 12.25), head_y=13.25, head_low_z=-108.3, top_z=-105.8, rear_x=-60.0,   # r2 R2
               groove_top_z=-105.55, groove_y=13.5, bump=0.35, bump_x=-57.0, bump_z=(-107.2, -106.0), dimple_y=13.75,
               # FIXER r2: key top and groove top +0.1 (head tip 1.65 at the probe, hook class 1.6)
               pocket=dict(inset=5.0, half_w=8.5, floor=3.0, r=4.0))
# r2 R2: dimple_y 13.8 -> 13.75 keeps the detent arm (side-wall strip outside the groove) 1.25 at the dimple
CRADLE = dict(shelf_t=1.6, rear_t=1.6, rear_top_z=-20.2, guide_t=1.6, guide_top_z=-20.5, pad_boss_t=0.75)
# rear stop top -20.2: above the cap axis (z -21, the press line) and below the XT30 pair box (z -20..-14.8)
# pad boss: 0.75 on the front-wall inner face behind the 1.5 deep run pad, so the wall there is 1.75 (not 1.0)
JUNCTION_FILLET = 3.0
HEEL_CHAMFER = 1.0

_FD = {pid: dc.L.PARTS[pid]['face_down'] for pid in ('base_grip', 'cap')}
PRINT = {
    'base_grip': dict(
        face_down=_FD['base_grip'],
        supports='none. Prints upside down (base top on the bed): keyhole lips are the first 1.6 mm, the head '
                 'pockets bridge 18.5 (x), the nut-pocket ceiling bridges 11.4 round the dia 6.6 hole, the run-button '
                 'shelf and rear stop bridge 25 between the bay walls, the heel strap slots bridge 13, the dia 13.6 run '
                 'hole has a 45 deg teardrop roof, the cap grooves have 45 deg faces.',
        notes='ASA black, 4 perimeters, 25 % gyroid; 40 % modifier meshes 8 mm round the 3 counterbores and the nut '
              'pocket (r4: out/stl/modifiers/base_grip__mod_*.stl, load at their exported position). '
              'Brim 5 mm (102 mm tall column on a 70 x 116 base). Clean the keyhole lips and the cap grooves with a '
              'file; test-slide the cap before assembly.'),
    'cap': dict(face_down=_FD['cap'], supports='none (key heads 45 deg; detent bumps 0.35 proud, 1.2 tall)',
                notes='ASA black, bottom (thumb grooves + open arrow) on the bed; 100 % or 6 perimeters.'),
}


# ----------------------------------------------------------------------------------------------- small helpers
def _xz_prism(poly, y0, y1):
    """Prism from an (x, z) polygon, over y0..y1."""
    pl = cq.Plane(origin=V(0, y1, 0), xDir=V(1, 0, 0), normal=V(0, -1, 0))
    return dc._prism(poly, pl, 0.0, y1 - y0)


def _yz_prism(poly, x0, x1):
    """Prism from a (y, z) polygon, over x0..x1."""
    pl = cq.Plane(origin=V(x0, 0, 0), xDir=V(0, 1, 0), normal=V(1, 0, 0))
    return dc._prism(poly, pl, 0.0, x1 - x0)


def _xy_prism(poly, z0, z1):
    """Prism from an (x, y) polygon, over z0..z1."""
    pl = cq.Plane(origin=V(0, 0, z0), xDir=V(1, 0, 0), normal=V(0, 0, 1))
    return dc._prism(poly, pl, 0.0, z1 - z0)


def _box(x0, x1, y0, y1, z0, z1):
    return dc.box_solid(dict(x=(x0, x1), y=(y0, y1), z=(z0, z1)))


def _rbox(x0, x1, y0, y1, z0, z1, r=0.0):
    """Box with its vertical (Z) edges rounded by r."""
    wp = cq.Workplane('XY').box(x1 - x0, y1 - y0, z1 - z0, centered=False).translate((x0, y0, z0))
    if r > 0:
        wp = wp.edges('|Z').fillet(r)
    return wp.val()


def _wp(s):
    return cq.Workplane('XY').newObject([s])


def _sorted(a, b):
    return (a, b) if a <= b else (b, a)


# ----------------------------------------------------------------------------------------------- base_grip
def _base_body(L):
    """Slab (5 mm front chamfer, bed chamfers) + grip column (er 9, heel chamfer) + R3 web fillet."""
    BS, G = L.BASE, L.GRIP
    (x0, x1), (y0, y1), (z0, z1) = BS['x'], BS['y'], BS['z']
    ch, bc = BS['front_chamfer'], L.FDM['BED_CHAMFER']
    rear_ch = 1.0
    slab = _xz_prism([(x0 + rear_ch, z0), (x1 - ch, z0), (x1, z0 + ch), (x1, z1 - bc), (x1 - bc, z1),
                      (x0 + bc, z1), (x0, z1 - bc), (x0, z0 + rear_ch)], y0, y1)
    slab_wp = _wp(slab)
    for yy in (y0, y1):
        sel = cq.selectors.BoxSelector((x0 - 1, yy - 0.1, z1 - 0.05), (x1 + 1, yy + 0.1, z1 + 0.05))
        slab_wp = dc.safe_chamfer(slab_wp, sel, bc)
    (gx0, gx1), (gy0, gy1), gz0 = G['x'], G['y'], G['z'][0]
    col = _wp(_rbox(gx0, gx1, gy0, gy1, gz0, z0 + 0.1, G['er']))
    col = dc.safe_chamfer(col, '<Z', HEEL_CHAMFER)
    body = slab_wp.val().fuse(col.val()).clean()
    sel = cq.selectors.BoxSelector((gx0 - 0.5, gy0 - 0.5, z0 - 0.05), (gx1 + 0.5, gy1 + 0.5, z0 + 0.05))
    return dc.safe_fillet(_wp(body), sel, JUNCTION_FILLET).val()
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

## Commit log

2026-10-08 Add the GS8 D2 fork (r5 + adopted cloud polish)
    GS8 D2 is a pistol-grip digital Super 8 cine camera: Raspberry Pi 5, the
    Raspberry Pi Global Shutter camera, an integrated micro-OLED EVF and a
    3D-printed ASA body. This commit carries only the D2 fork of the wider GS8
    project.
    - cad/gs8-d2-v1: CadQuery sources, checks, tests, docs and research notes.
    It also holds the current release outputs: Kowa receipt 2026-10-07
    13:34:26 +0800, 27/27 categories, 748 pass + 18 info, 0 fail. The Fujinon
    variant is 27/27, 745 + 18.
    - electronics/gs8-d2-v1: wiring, BOM generator and BOM.
    - software/gs8-camera-evf: the camera software, including the D2
    integration.
    - audit/d2-readiness-*: independent r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
    [base_edge_base.stl, base_edge_panel.stl, base_edge_tub.stl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]
2026-10-08 r6: settle print order and orientation; fix audit 2026-10-06 minor findings
    - Print order: layout.PRINT_PREREQS / COUPON_PREREQS / PRINT_SEQUENCE, enforced on
    slicer and G-COL-1 coupon records; receipt print_release; PRINT-GUIDE s7 generated.
    - Orientation: new computed check print_overhang (layer slices, bridges, declared
    support zones); two new tub supports (s_k2 and LL boss chins); collar ears r 5.6.
    - X2: per-lens collar centring gauge (stl/tools/collar_gauge.stl), step 7 reordered,
    centring stack in j7_float.
    - Checks: j7_float 0.25 mm back-focus sweep, missing lens/collar fail, lens gap 0.5,
    duplicate probe ids fail + LR-foot probe, G-LENS record for 'measured', bolted-only
    W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
    [base_grip.step, bom.csv, cap.step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]
2026-10-09 r7: rectify the 2026-10-08 assembly blocker review; add the IKEA-style assembly guide
    Physical blocker review of the build sequence (guide/BLOCKERS-2026-10-08.md):
    1 BLOCKER, 4 MAJOR, 12 MINOR. r7 fixes the BLOCKER and every MAJOR in CAD:
    - BX-1 (EVF HDMI plug vs tub rail): the pair slides in unplugged, the HDMI is
    plugged in place; new PLUGS registry, carried-plug sweeps/removals and the
    mate_paths check (the r6 order now fails at 60-66 mm3).
    - BX-2 (QT lead too short): 250 mm lead plugged with the panel 60 mm off;
    mate_reach, cable_stow, header_housings checks.
    - BX-3 (pigtail tie / XT30 reach): cut-to-length pigtail with RTV strain
    relief, XT30 28.4 mm out of the grip; lead_access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
    [base_grip.step, bom.csv, cap.step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]
